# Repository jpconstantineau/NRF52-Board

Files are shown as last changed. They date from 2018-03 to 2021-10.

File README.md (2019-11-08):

# NRF52-Board

This Repository is a collection of NRF5x boards.

TODO: remap folders...

|  Hardware Name | PCB Folder name | Processor | Firmware  | Circuit Diagram | Build Guide |
| --- |:---:|:---:|:-----:|:-----:|:-----:|
|  LiPo Charger 3.3V Regulator | [Batt_Charger_Regulator](/Batt_Charger_Regulator) | n/a | n/a | | [Build Guide](/Batt_Charger_Regulator/BuildGuide.md) |
|  CR2032 Coin Cell Holder | [Battery](/Battery) | n/a | n/a | | [Build Guide](/Battery/BuildGuide.md)|
|  Mini Switch | [MiniSwitch](/MiniSwitch) |n/a |  n/a | | [Build Guide](/MiniSwitch/BuildGuide.md)|
|  BlueMicro V1.x | [EByte_E73](/EByte_E73) |NRF52832 |  [BlueMicro_BLE](https://github.com/jpconstantineau/BlueMicro_BLE) | | [Build Guide](/EByte_E73/BuildGuide.md)|
|  BlueMicro V2.0b | [EByte_E73_Batt](/EByte_E73_Batt) | NRF52832 |  [BlueMicro_BLE](https://github.com/jpconstantineau/BlueMicro_BLE) | | [Build Guide](/EByte_E73_Batt/BuildGuide.md) |
|  BlueMicro V2.0c | [EByte_E73_Batt_ErgoTravel](/EByte_E73_Batt_ErgoTravel) | NRF52832 |  [BlueMicro_BLE](https://github.com/jpconstantineau/BlueMicro_BLE) | | [Build Guide](/EByte_E73_Batt_ErgoTravel/BuildGuide.md) |
| 4X4 backpack | [EByte_E73_Batt_Macro_4x4](/EByte_E73_Batt_Macro_4x4) | NRF52832 |  [BlueMicro_BLE](https://github.com/jpconstantineau/BlueMicro_BLE) | | [Build Guide](/EByte_E73_Batt_Macro_4x4/BuildGuide.md)|
| BlueMicro Tester | [EByte_E73_tester](/EByte_E73_tester) | NRF52832 |  Arduino | | |
| BlueMicro51 | [YJ-14015](/YJ-14015)| NRF51822 |  tbd | | |

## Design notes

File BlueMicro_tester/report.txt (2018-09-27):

Info: Backing up file “C:\GIT\NRF52-Board\EByte_E73_tester\sym-lib-table” to file “C:\GIT\NRF52-Board\EByte_E73_tester\rescue-backup\sym-lib-table-2018-09-22-21-38-46”.
Info: Backing up file “C:\GIT\NRF52-Board\EByte_E73_tester\EByte_E73_tester.sch” to file “C:\GIT\NRF52-Board\EByte_E73_tester\rescue-backup\EByte_E73_tester-2018-09-22-21-38-46.sch”.
Info: Backing up file “C:\GIT\NRF52-Board\EByte_E73_tester\EByte_E73_tester.pro” to file “C:\GIT\NRF52-Board\EByte_E73_tester\rescue-backup\EByte_E73_tester-2018-09-22-21-38-46.pro”.
Info: Backing up file “C:\GIT\NRF52-Board\EByte_E73_tester\EByte_E73_tester-cache.lib” to file “C:\GIT\NRF52-Board\EByte_E73_tester\rescue-backup\EByte_E73_tester-cache-2018-09-22-21-38-46.lib”.
Info: Backing up file “C:\GIT\NRF52-Board\EByte_E73_tester\EByte_E73_tester-rescue.lib” to file “C:\GIT\NRF52-Board\EByte_E73_tester\rescue-backup\EByte_E73_tester-rescue-2018-09-22-21-38-46.lib”.
Info: Backing up file “C:\GIT\NRF52-Board\EByte_E73_tester\EByte_E73_tester-rescue.dcm” to file “C:\GIT\NRF52-Board\EByte_E73_tester\rescue-backup\EByte_E73_tester-rescue-2018-09-22-21-38-46.dcm”.
Warning: No symbol “E73-2G4M04S” found in symbol library table.
Symbol “GND” mapped to symbol library “power”.
Symbol “GND” mapped to symbol library “power”.
Symbol “GND” mapped to symbol library “power”.
Symbol “VCC” mapped to symbol library “power”.
Symbol “L” mapped to symbol library “Device”.
Symbol “C” mapped to symbol library “Device”.
Symbol “C” mapped to symbol library “Device”.
Symbol “GND” mapped to symbol library “power”.
Symbol “C” mapped to symbol library “Device”.
Warning: No symbol “SW_PUSH” found in symbol library table.
Warning: No symbol “SW_PUSH” found in symbol library table.
Symbol “GND” mapped to symbol library “power”.
Symbol “R” mapped to symbol library “Device”.
Symbol “VCC” mapped to symbol library “power”.
Symbol “GND” mapped to symbol library “power”.
Warning: No symbol “Conn_01x06” found in symbol library table.
Symbol “GND” mapped to symbol library “power”.
Symbol “VCC” mapped to symbol library “power”.
Warning: No symbol “JUMPER-SMT_2_NO” found in symbol library table.
Symbol “GND” mapped to symbol library “power”.
Warning: No symbol “ProMicro” found in symbol library table.
Symbol “GND” mapped to symbol library “power”.
Symbol “VCC” mapped to symbol library “power”.
Symbol “GND” mapped to symbol library “power”.
Warning: No symbol “SW_PUSH” found in symbol library table.
Warning: No symbol “SW_PUSH” found in symbol library table.
Symbol “C” mapped to symbol library “Device”.
Symbol “GND” mapped to symbol library “power”.
Info: Symbol library table mapping complete!

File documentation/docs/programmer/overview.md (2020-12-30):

---
id: programmer_overview
title: Need a Programmer?
slug: /programmer/
---

## Why would you need one?

Here are a few reasons why you would need a SWD programmer:

* you have built/assembled a nRF52 board using a bare nRF52 chip or a module containing a nRF52 chip which were not previously programmed.
* you have completed the build of a partially assembled nRF52 board and need to flash the bootloader
* you have somehow bricked your nRF52 board and need to re-flash the bootloader
* you want to experiment with new bootloaders

## Available Options

| Name  | Connector  | Software  | License  | Comments  |
|---|---|---|---|---|
|[Segger J-Link Plus](https://www.digikey.com/en/products/detail/segger-microcontroller-systems/8-08-28-J-LINK-PLUS/4476087)| 2.54mm 2x10 | Segger J-Link | Segger | Expensive |
|[Segger J-Link Edu](https://www.digikey.com/en/products/detail/segger-microcontroller-systems/8-08-90-J-LINK-EDU/2263130)| 2.54mm 2x10 | Segger J-Link | Segger | Educational Use Only |
|[Segger J-Link Edu Mini](https://www.digikey.com/en/products/detail/segger-microcontroller-systems/8-08-91-J-LINK-EDU-MINI/7387472)| 1.27mm 2x5 | Segger J-Link | Segger | Educational Use Only, only supports 3.3V targets.  You will need a cable adapter.|
|Chinese J-Link Clone| Varies depending on version | Segger J-Link | Segger | may generate odd error messages (which can be dismissed), only supports 3.3V targets |
|Chinese ST-Link V2 Clone| non-standard 2.54 2x5 | OpenOCD | Open Source | Complex to setup, only supports 3.3V targets |
|Raspberry Pi| 40 Pin header | OpenOCD | Open Source | Complex to setup, only supports 3.3V targets|
|CMSIS-DAP| Varies but generally 1.27mm 2x5 | OpenOCD | Open Source | Complex to setup, only supports 3.3V targets |
|[Blackmagic Probe](https://1bitsquared.com/collections/frontpage/products/black-magic-probe)| 1.27mm 2x5 | GDB | Open Source | No additional software to setup. You will need a cable adapter. Supports 1.7-5V targets.|
|BluePill| non-standard 2.54 | GDB | Open Source | Cheap but complex to setup, only supports 3.3V targets |
|[nRF52 SWD Programmer and Debugger](/docs/programmer/programmer_nrf52bmp)| 2.54mm 2x5 and 2.54mm 1x4 | GDB | Open Source | No additional software to setup. Supports 1.8-3.3V targets. |

## Notes on Nordic Semiconductor and Segger

[Segger and Nordic have worked together for years and Segger Embedded Studio is used internally by Nordic engineers](https://www.nordicsemi.com/Software-and-tools/Development-Tools/Segger-Embedded-Studio). This is why Nordic usually recommends Segger's J-Link as the tool of choice for programming the nRF52 chips.

## Notes on Adafruit nRF52 Arduino support

The [Adafruit nRF52 Arduino](https://github.com/adafruit/Adafruit_nRF52_Arduino) board support package uses Segger's J-Link to program the bootloader.  If you don't have a j-link, you won't be able to use the integration within the Arduino IDE to flash the bootloader.

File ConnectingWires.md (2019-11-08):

## Preparing Connecting wires to Flash a BlueMicro ##

**Preparing a purple Jlink wire bundle**

You will need to connect power to the BlueMicro since the purple jlink does not provide power; it only detects that the BlueMicro receives power...

Swdck -> SWDck

Swdio -> swdio

Gnd -> gnd

VCC -> VCC

Remove all 1 pin shells from a 4 wire bundle.  For the BlueMicro, this will be a M-F bundle.

* Take a 4 pin shell
* line-up the 4 dupont metal connectors in the shell to line up with the jlink lines (choose colors that make sense for each line)
* Take 2 2 pins shells. 
* Put GND and VCC in one of the 2 pin shell. 
* Put swdio and swdck in the other 2 pin shell. 

We use 2 pin shells because we need to mirror the connections when we flash to left vs right (the BlueMicro is upside down on one side)

**Preparing a Serial Bundle**

For the serial, you need 3 wires

Gnd -> gnd

Rx -> tx

Tx -> Rx.

For serial, 
* Take a 6 pin shell (enough to fit the entire CH340g serial adapter) 
* Take a 3 wire bundle (F-F).  
* On the 6 pin side, line up RX,TX and GNd with colors that make sense...
* For the other end, install the small angled header in the ErgoTravel where it has gnd, Rx and TX. This is the same header as the RGB strips connections for wired builds.  
* Once soldered, you can then fill-in a 4 pin shell with the Rx,tx and GNdD (Reset will be somewhere in there but not used) VCC isnt connected too.

Do not connect VCC of the serial adapter. I have seen such adapters burn out because the internal power regulator was competing with a more powerful power regulator... Just connect the battery and the 3 serial wires and you should be good.  You will need to press the reset switch at the right time to get the BlueMicro in dfu serial. (If a firmware is loaded, it remains in dfu serial for a couple of seconds)

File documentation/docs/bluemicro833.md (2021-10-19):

---
id: bluemicro833
title: BlueMicro833 V1.x
---
## Description

## Processor and Module

The BlueMicro833 uses the nRF52833 from Nordic Semiconductors. For an overview of the features of this SoC, refer to Nordic's [Product Page](https://www.nordicsemi.com/Products/Low-power-short-range-wireless/nRF52840).  The most important features are as follows:

* 64 MHz Cortex-M4 with FPU
* 512 KB Flash, 128 KB RAM
* 2.4 GHz Transceiver
* -20 to +8 dbm programmable TX Power
* 42 configurable GPIOs
* USB 2.0

For a detailed description of the nRF52833, you can download the [Specification](https://infocenter.nordicsemi.com/pdf/nRF52833_OPS_v0.7.pdf) (582 pages).

The BlueMicro833 uses the [Ebyte E73-2G4M08S1E module](https://s.click.aliexpress.com/e/_AkrGeT).   
The module uses a ceramic antenna and makes 31 GPIOs available externally, 2 of which are reserved for the low frequency crystal oscilator and 1 is reserved for the reset button.
For a detailed description of the module, refer to the [manual](https://www.ebyte.com/en/pdf-down.aspx?id=2004).

## Bootloader

Although the BlueMicro833 can be programmed using the Nordic Software Development Kit and other commercial tools, we recommend using the open source [Adafruit nRF52 Bootloader](https://github.com/adafruit/Adafruit_nRF52_Bootloader) as the bootloader for the BlueMicro833. 

You can obtain the bootloader from the following locations:

* release artifacts of the [Adafruit Repo](https://github.com/adafruit/Adafruit_nRF52_Bootloader/releases)

## Firmware

CircuitPython is supported by the BlueMicro833.  You can get the UF2 Build at the following location:

* CircuitPython Download for the [BlueMicro833](https://circuitpython.org/board/bluemicro833/)

## Pinout

You can find the pinout in the schematic [here](https://github.com/jpconstantineau/BlueMicro833_hardware/blob/main/Schematic.pdf) at the top right.

## PCB

[hardware design repo](https://github.com/jpconstantineau/BlueMicro833_hardware)

## Schematic

You can find the schematic [here](https://github.com/jpconstantineau/BlueMicro833_hardware/blob/main/Schematic.pdf)

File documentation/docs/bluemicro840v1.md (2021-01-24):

---
id: bluemicro840_v1
title: BlueMicro840 V1.x
---
## Description

## Processor and Module

The BlueMicro840 uses the nRF52840 from Nordic Semiconductors. For an overview of the features of this SoC, refer to Nordic's [Product Page](https://www.nordicsemi.com/Products/Low-power-short-range-wireless/nRF52840).  The most important features are as follows:

* 64 MHz Cortex-M4 with FPU
* 1 MB Flash, 256 KB RAM
* 2.4 GHz Transceiver
* -20 to +8 dbm programmable TX Power
* 48 configurable GPIOs
* USB 2.0

For a detailed description of the nRF52840, you can download the [datasheet](https://infocenter.nordicsemi.com/pdf/nRF52840_PS_v1.1.pdf) (619 pages).

The BlueMicro840 uses the [Ebyte E73-2G4M08S1C module](https://s.click.aliexpress.com/e/_dWxR3nN). This module is FCC and CE certified.  
The module uses a ceramic antenna and makes 32 GPIOs available externally, 2 of which are reserved for the low frequency crystal oscilator and 1 is reserved for the reset button.
For a detailed description of the module, refer to the [manual](http://www.ebyte.com/en/downpdf.aspx?id=445).

## Bootloader

Although the BlueMicro840 can be programmed using the Nordic Software Development Kit and other commercial tools, we recommend using the open source [Adafruit nRF52 Bootloader](https://github.com/adafruit/Adafruit_nRF52_Bootloader) as the bootloader for the BlueMicro840.  Two versions of the bootloader are compatible with the BlueMicro840:

* [Nordic nRF52840-DK](https://www.nordicsemi.com/Software-and-Tools/Development-Kits/nRF52840-DK) - also named PCA10056
* [BlueMicro840](http://nrf52.jpconstantineau.com/docs/bluemicro840_v1).

You can obtain the above bootloaders from the following locations:

* release artifacts of the [Adafruit Repo](https://github.com/adafruit/Adafruit_nRF52_Bootloader/releases)
* release artifacts of the [Forked Repo](https://github.com/jpconstantineau/Adafruit_nRF52_Bootloader/releases)
* Adafruit nRF52 Arduino Board Support Package
* Community Add-on to Adafruit nRF52 Arduino Board Support Package

## Firmware

## Pinout


NOTE: The Silkscreen on pin 6 (labelled 0.31) is incorrectly printed as 0.31. It should read 0.26. The schematic below is correct.

## PCB
| Top  | Bottom  |
|---|---|
|  |   |

NOTE: The Silkscreen on pin 6 (labelled 0.31) is incorrectly printed as 0.31. It should read 0.26. The schematic below is correct.

## Schematic

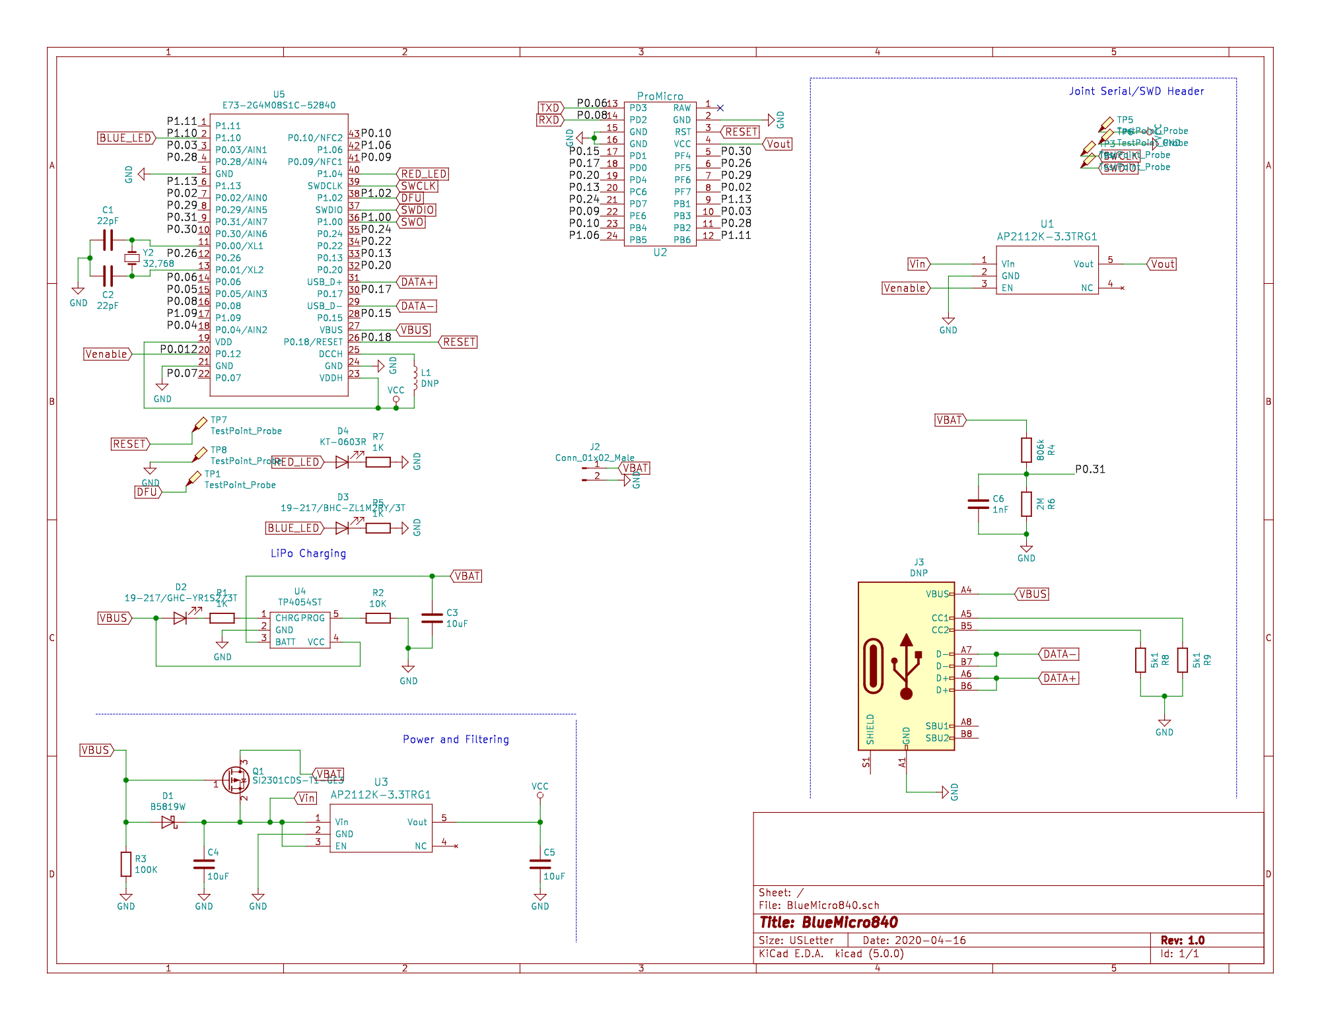
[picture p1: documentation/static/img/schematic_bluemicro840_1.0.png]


## Building it yourself?

You need to order the parts included in this [csv BOM](https://raw.githubusercontent.com/jpconstantineau/NRF52-Board/master/BlueMicro840/BlueMicro840.csv).  You can it load in Excel.  The LCSC column refers to the part number at [LCSC.com](https://lcsc.com/).

### Small Components

If you are assembling the BlueMicro840 yourself, refer to the [HTML Bom](http://nrf52.jpconstantineau.com/bom/BlueMicro840/ibom.html) to help you as you assemble it. If you have received the partially assembled boards, you will have all these components already installed and you can move on to the next section.

### USB-C Connector

Steps to solder the TYPE-C-31-M-12 from Korean Hroparts Elec onto a PCB using only a Soldering Iron:
1 - using a no-clean rosin fluxed Solder, pre-apply some solder to the pads, making sure you don't have large "blobs" or joints between pads.
2 - place the connector on top, making sure to align it properly.
3 - apply heat to the connector pins.  This will solder the pins in place.
4 - once soldered, move on to the body of the connector, starting with one of the larger pegs.
5 - Once the 4 metal body pegs are soldered, pass again over the connector pins; making sure that no solder bridges two pins.

<figure class="video-container">
 <iframe src="http://www.youtube.com/embed/PbO9HdlcIPY" frameborder="0" allowfullscreen width="100%"></iframe>
 </figure>

Tools I use for soldering the connector:

* TS 100 Soldering Iron with 19V power supply (300C setting)
* TS-D24 Soldering Tip. This is the Chisel Tip one.
* Copper Cleaning Ball for Soldering Iron (ball of copper wool in a metal container)
* MG Chemicals 63/37 No Clean Leaded Solder, 0.032" Diameter

Once you have soldered the connectors on, you will need to test if there are any shorts between VUsb and GND. These are the outermost pins on each side of the connector.  Because VUsb is not available on the pins, I use a USB tester.  You can test it using a multimeter on the continuity testing function.

<figure class="video-container">
 <iframe src="http://www.youtube.com/embed/2jEpu-We5eI" frameborder="0" allowfullscreen width="100%"></iframe>
 </figure>

Tools I use for testing  the connector:
* [USB Tester](https://s.click.aliexpress.com/e/_AaXAiW)
* [25cm USB-C Cable](https://s.click.aliexpress.com/e/_Aot7Zo)
* Old phone charger

### E73 Module

With the hidden pads underneath the module, soldering it to a PCB using just a soldering iron isn't a trivial task.

Steps:

1. Add a bead of solder to the inner pads of the E73 module.  Make sure that they are not too large and are all the same size
2. Line-up the beads with the holes matching these pads in the PCB.  Since the beads will "fall into" the holes they will "fall in place" somewhat.  A binder clip will help hold everything together
3. Heat-up the inner pads on the opposite side of the PCB, distributing the heat to all pads so that the solder melt and until there is no gap left between the module and PCB.  This will require multiple passes with a larger soldering iron tip to heat more than 1 pad at a time.
4. Once the inner pads are soldered, change your tip to a conical one with w relatively fine tip (not super fine).  You can then start soldering the outer pads.  Make sure to keep the head and iron away from the holes of the PCB.  Only heat the castellations of the module, apply a little bit of solder and let it flow towards the PCB pad.
5. Go and solder the 3 sides of the module, one joint at a time.
6. Once you have all joints done, visually inspect all connections to make sure there are no shorts between pins.
7. Go ahead and test with a USB tester.  This will make sure there are no shorts in the power circuitry.
8. To test the rest, we need to flash a bootloader and some testing firmware on it.

<figure class="video-container">
 <iframe src="http://www.youtube.com/embed/k_32XvBC0sA" frameborder="0" allowfullscreen width="100%"></iframe>
 </figure>

Tools Used:

* TS 100 Soldering Iron with 19V power supply (300C setting)
* TS-D24 Soldering Tip. This is the Chisel Tip one.
* TS-B2 Conical Soldering Tip (not very fine like the TS-I)
* Copper Cleaning Ball for Soldering Iron (ball of copper wool in a metal container)
* MG Chemicals 63/37 No Clean Leaded Solder, 0.032" Diameter
* Small Binder Clip
* Solder Wick

### Flash Bootloader

Using the Community nRF52 Add-on Boards in the Arduino IDE and a Black Magic Probe (nRF52 GDB Debugger), it's possible to unlock and flash the bootloader very easily without the need to configure any special software.

<figure class="video-container">
 <iframe src="http://www.youtube.com/embed/-Na2m6-LVGI" frameborder="0" allowfullscreen width="100%"></iframe>
 </figure>

1. Select Board type.  In this case, it's a BlueMacro840
2. Select Programmer (use Black Magic Probe - Unlock and Erase)
3. Select Serial port from Programmer (there are 2, you may have to try each one)
4. Select "Burn Bootloader" while making sure there is good contact with the board. This will unlock the nrf52840 (or nrf52832)
5. Select Programmer (use Black Magic Probe)
6. Select "Burn Bootloader" while making sure there is good contact with the board. This will flash the bootloader

There are 2 common errors:
* SWD Scan failed: this is generally due to a poor connection with the chip. Note that in the video, I give the BlueMacro840 and programmer a gentle twist to make sure I have a good contact.
* Cannot flash because the chip is protected.  You need to "unlock and erase" before flashing the bootloader. 

### Test USB-C Connector

This step is done after the bootloader is flashed to the chip.  With the bootloader enabled, we will see if the computer detects the nRF52840 chip.  If the device doesn't connect or if the device is not recognized, it's likely that the data lines on the USB-C connector are not soldered properly.

<figure class="video-container">
 <iframe src="http://www.youtube.com/embed/brCGFSwaw_k" frameborder="0" allowfullscreen width="100%"></iframe>
 </figure>

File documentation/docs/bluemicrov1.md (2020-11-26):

---
id: bluemicro_v1
title: BlueMicro V1.x
---

## Description

The BlueMicro V1.x is a simple breakout board for the Ebyte E73-2G4M04S1B module (nRF52832) so that the pinout matches that of the Arduino Pro Micro.

## Processor and Module

The BlueMicro uses the nRF52832 from Nordic Semiconductors. For an overview of the features of this SoC, refer to Nordic's [Product Page](https://www.nordicsemi.com/Products/Low-power-short-range-wireless/nRF52832).  The most important features are as follows:

* 64 MHz Cortex-M4 with FPU
* 512 KB Flash, 64 KB RAM
* 2.4 GHz Transceiver
* -20 to +4 dbm programmable TX Power
* 32 configurable GPIOs

For a detailed description of the nRF52832, you can download the [datasheet](http://infocenter.nordicsemi.com/pdf/nRF52832_PS_v1.4.pdf) (533 pages).

The BlueMicro uses the [Ebyte E73-2G4M04S1B module](https://s.click.aliexpress.com/e/_ACxA0g). This module is FCC and CE certified.  
The module uses a PCB antenna, has an external antenna connector and makes 30 GPIOs available externally, 1 of which is reserved for the reset button.  The bootloader and firmware may reserve additional GPIOs for specific functions (2 pins for serial, 1 pin for factory reset, 1 pin to put in DFU)
For a detailed description of the module, refer to the [manual](http://www.ebyte.com/en/downpdf.aspx?id=243).

If you want to replace the PCB antenna with an external antenna, the following [antenna](https://s.click.aliexpress.com/e/_A1WdTb) is the one that's designed by the module manufacturer.  The manual indicate the small surface mount resistor that needs moving to disconnect the PCB antenna and connect the external antenna.

## Bootloader

Although the BlueMicro can be programmed using the Nordic Software Development Kit and other commercial tools, we recommend using the open source [Adafruit nRF52 Bootloader](https://github.com/adafruit/Adafruit_nRF52_Bootloader) as the bootloader for the BlueMicro.  The Adafruit nRF52832 Feather bootloader is fully compatible with the BlueMicro.

You can obtain the bootloader from the following locations:

* release artifacts of the [Adafruit Repo](https://github.com/adafruit/Adafruit_nRF52_Bootloader/releases)
* release artifacts of the [Forked Repo](https://github.com/jpconstantineau/Adafruit_nRF52_Bootloader/releases)
* Adafruit nRF52 Arduino Board Support Package
* Community Add-on to Adafruit nRF52 Arduino Board Support Package

## Pinout

## PCB
| Top  | Bottom  |
|---|---|
|  |   |

## Schematic

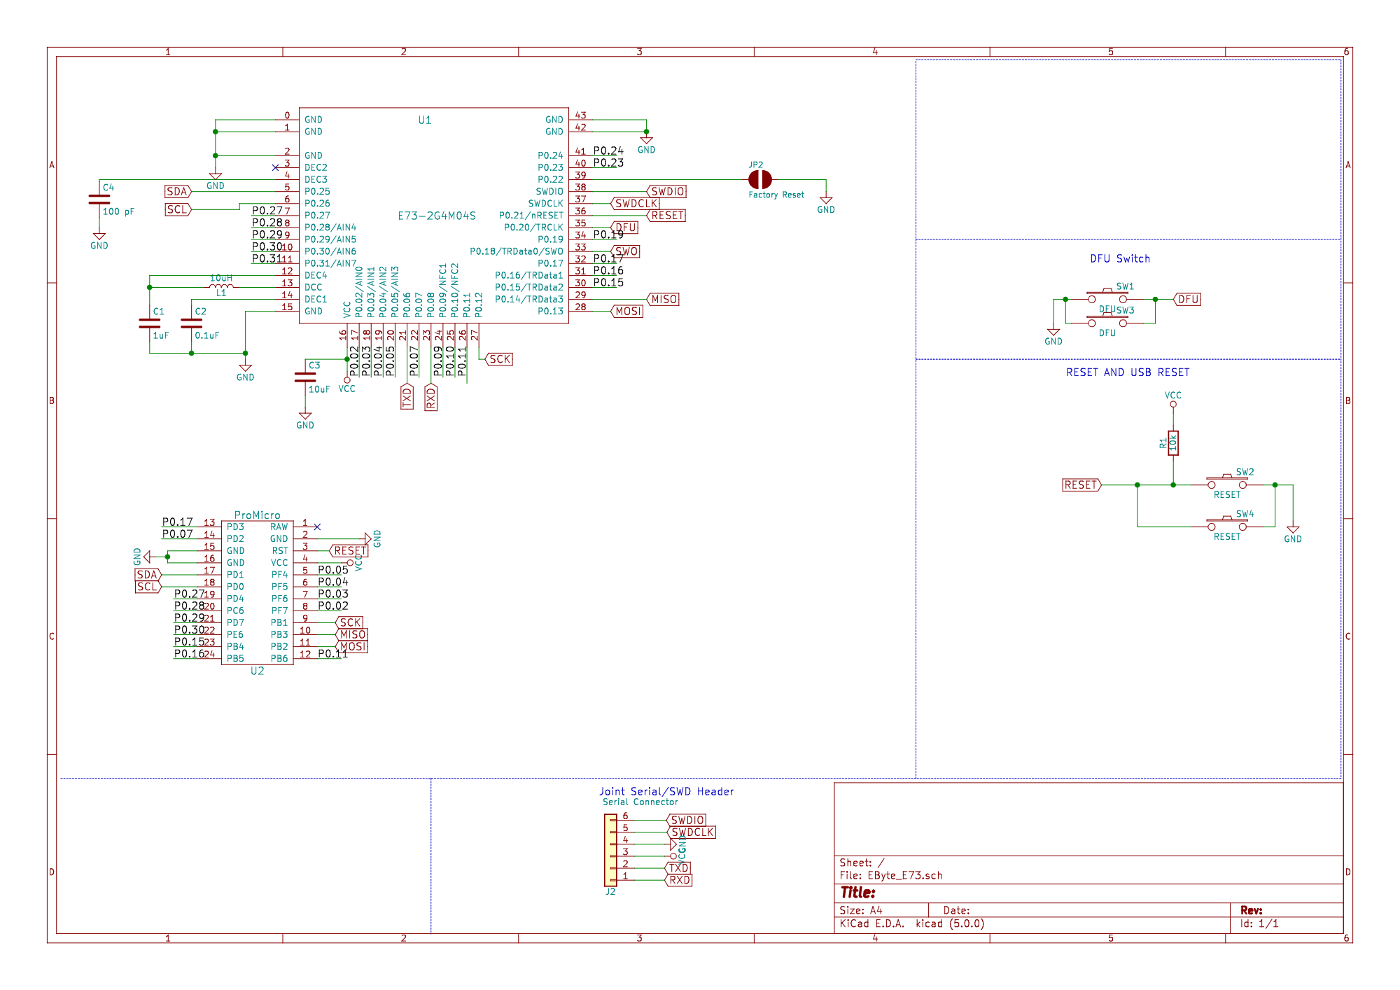
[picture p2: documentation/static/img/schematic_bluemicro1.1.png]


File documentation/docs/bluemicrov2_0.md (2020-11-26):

---
id: bluemicro_v2_0
title: BlueMicro V2.0
---

## Description

The BlueMicro V2.0 expands on the BlueMicro V1.x by adding a LiPo charger on board as well as battery monitoring circuitry to the breakout board for the Ebyte E73-2G4M04S1B module (nRF52832). The charger is powered by connecting a standard micro-usb cable to a computer or regular 5V charger.  The pinout still matches that of the Arduino Pro Micro.  The Raw pin is meant to be connected to the LiPo battery for powering on the BlueMicro.

## Processor and Module

The BlueMicro uses the nRF52832 from Nordic Semiconductors. For an overview of the features of this SoC, refer to Nordic's [Product Page](https://www.nordicsemi.com/Products/Low-power-short-range-wireless/nRF52832).  The most important features are as follows:

* 64 MHz Cortex-M4 with FPU
* 512 KB Flash, 64 KB RAM
* 2.4 GHz Transceiver
* -20 to +4 dbm programmable TX Power
* 32 configurable GPIOs

For a detailed description of the nRF52832, you can download the [datasheet](http://infocenter.nordicsemi.com/pdf/nRF52832_PS_v1.4.pdf) (533 pages).

The BlueMicro uses the [Ebyte E73-2G4M04S1B module](https://s.click.aliexpress.com/e/_ACxA0g). This module is FCC and CE certified.  
The module uses a PCB antenna, has an external antenna connector and makes 30 GPIOs available externally, 1 of which is reserved for the reset button.  The bootloader and firmware may reserve additional GPIOs for specific functions (2 pins for serial, 1 pin for factory reset, 1 pin to put in DFU)
For a detailed description of the module, refer to the [manual](http://www.ebyte.com/en/downpdf.aspx?id=243).

If you want to replace the PCB antenna with an external antenna, the following [antenna](https://s.click.aliexpress.com/e/_A1WdTb) is the one that's designed by the module manufacturer.  The manual indicate the small surface mount resistor that needs moving to disconnect the PCB antenna and connect the external antenna.

## Bootloader

Although the BlueMicro can be programmed using the Nordic Software Development Kit and other commercial tools, we recommend using the open source [Adafruit nRF52 Bootloader](https://github.com/adafruit/Adafruit_nRF52_Bootloader) as the bootloader for the BlueMicro.  The Adafruit nRF52832 Feather bootloader is fully compatible with the BlueMicro.

You can obtain the bootloader from the following locations:

* release artifacts of the [Adafruit Repo](https://github.com/adafruit/Adafruit_nRF52_Bootloader/releases)
* release artifacts of the [Forked Repo](https://github.com/jpconstantineau/Adafruit_nRF52_Bootloader/releases)
* Adafruit nRF52 Arduino Board Support Package
* Community Add-on to Adafruit nRF52 Arduino Board Support Package

## Pinout

## PCB
| Top  | Bottom  |
|---|---|
|  |   |

## Schematic

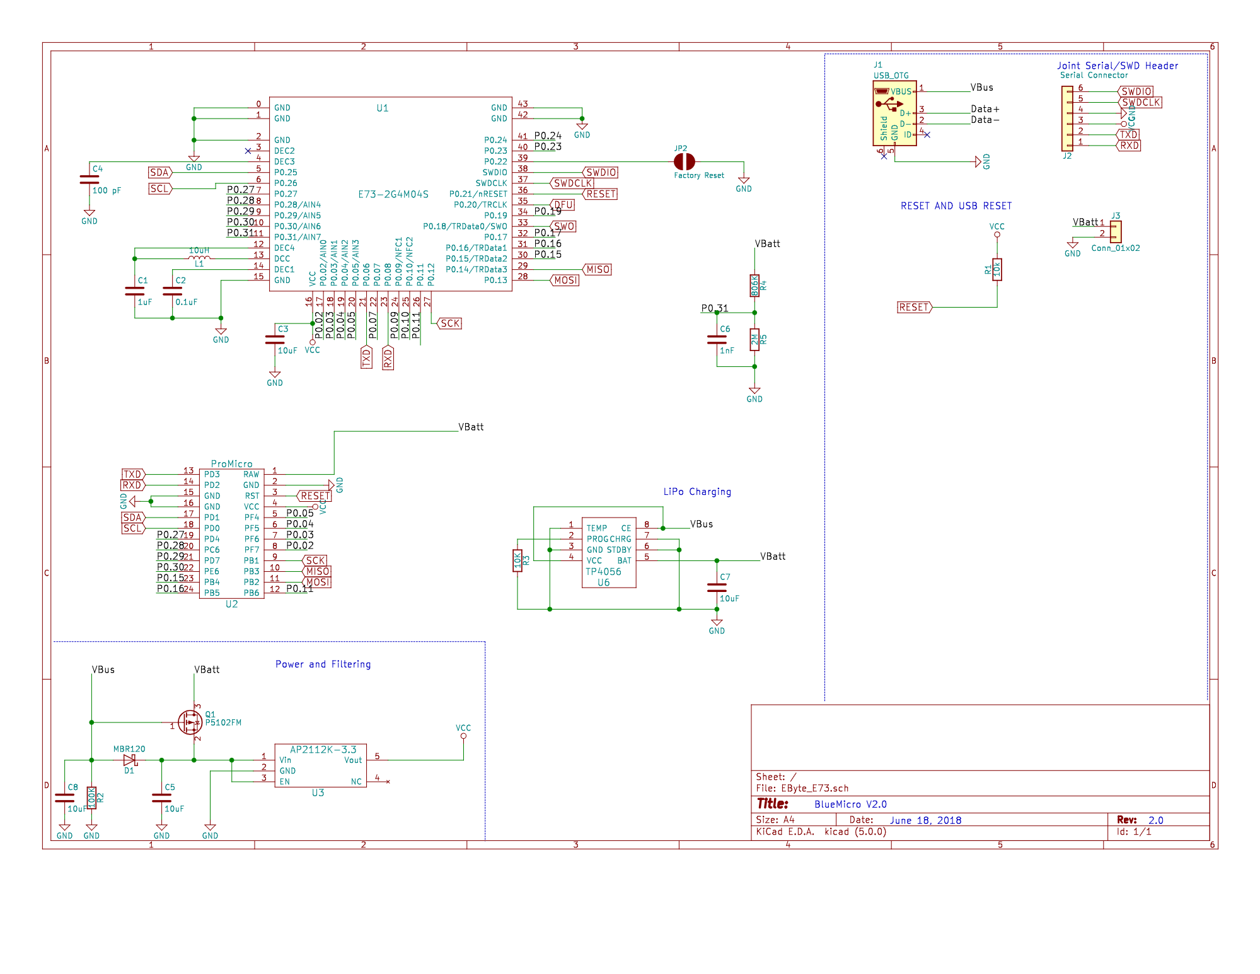
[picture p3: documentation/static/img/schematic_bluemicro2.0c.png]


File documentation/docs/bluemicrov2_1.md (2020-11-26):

---
id: bluemicro_v2_1
title: BlueMicro V2.1
---
## Description

The BlueMicro V2.1 expands on the BlueMicro V1.x and V2.0 by adding a serial chip to the breakout board for the Ebyte E73-2G4M04S1B module (nRF52832).  This serial chip allows for programming the BlueMicro without the need for any additionnal hardware and simplifies the process since the serial chip is also connected to the reset circuitry.  The charger is still powered by connecting a standard micro-usb cable to a computer or regular 5V charger.  The pinout still matches that of the Arduino Pro Micro.  The Raw pin is meant to be connected to the LiPo battery for powering on the BlueMicro.

Since the serial GPIOs are directly connected to the serial chip, the pinout differs slightly from the BlueMicro v2.0.

## Processor and Module

The BlueMicro uses the nRF52832 from Nordic Semiconductors. For an overview of the features of this SoC, refer to Nordic's [Product Page](https://www.nordicsemi.com/Products/Low-power-short-range-wireless/nRF52832).  The most important features are as follows:

* 64 MHz Cortex-M4 with FPU
* 512 KB Flash, 64 KB RAM
* 2.4 GHz Transceiver
* -20 to +4 dbm programmable TX Power
* 32 configurable GPIOs

For a detailed description of the nRF52832, you can download the [datasheet](http://infocenter.nordicsemi.com/pdf/nRF52832_PS_v1.4.pdf) (533 pages).

The BlueMicro uses the [Ebyte E73-2G4M04S1B module](https://s.click.aliexpress.com/e/_ACxA0g). This module is FCC and CE certified.  
The module uses a PCB antenna, has an external antenna connector and makes 30 GPIOs available externally, 1 of which is reserved for the reset button.  The bootloader and firmware may reserve additional GPIOs for specific functions (2 pins for serial, 1 pin for factory reset, 1 pin to put in DFU)
For a detailed description of the module, refer to the [manual](http://www.ebyte.com/en/downpdf.aspx?id=243).

If you want to replace the PCB antenna with an external antenna, the following [antenna](https://s.click.aliexpress.com/e/_A1WdTb) is the one that's designed by the module manufacturer.  The manual indicate the small surface mount resistor that needs moving to disconnect the PCB antenna and connect the external antenna.

## Bootloader

Although the BlueMicro can be programmed using the Nordic Software Development Kit and other commercial tools, we recommend using the open source [Adafruit nRF52 Bootloader](https://github.com/adafruit/Adafruit_nRF52_Bootloader) as the bootloader for the BlueMicro.  The Adafruit nRF52832 Feather bootloader is fully compatible with the BlueMicro.

You can obtain the bootloader from the following locations:

* release artifacts of the [Adafruit Repo](https://github.com/adafruit/Adafruit_nRF52_Bootloader/releases)
* release artifacts of the [Forked Repo](https://github.com/jpconstantineau/Adafruit_nRF52_Bootloader/releases)
* Adafruit nRF52 Arduino Board Support Package
* Community Add-on to Adafruit nRF52 Arduino Board Support Package

## Pinout

## PCB
| Top  | Bottom  |
|---|---|
|  |   |

## Schematic

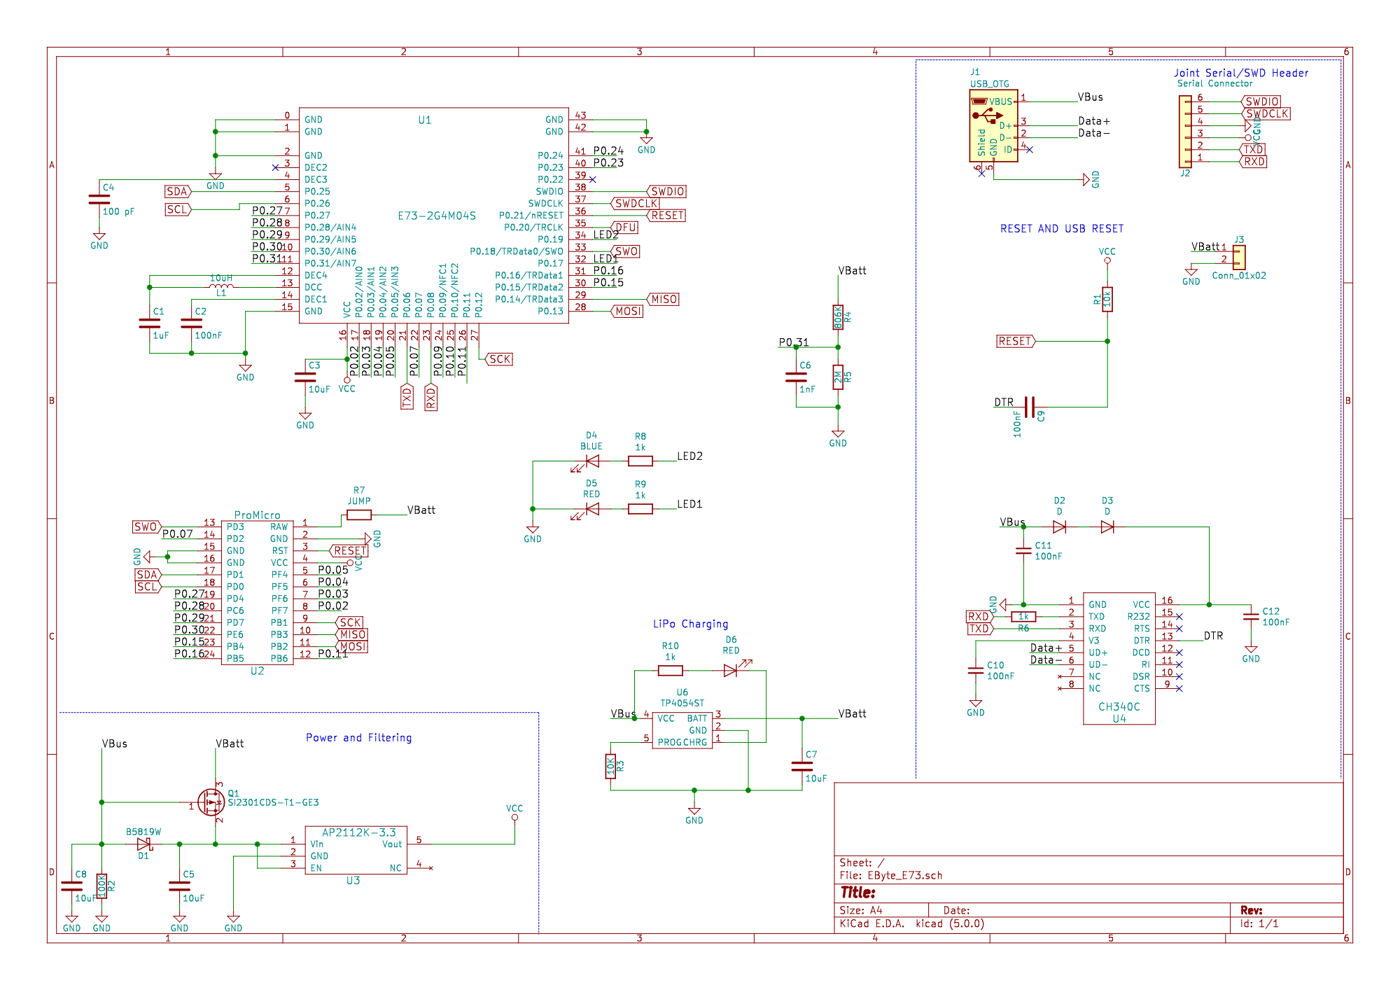
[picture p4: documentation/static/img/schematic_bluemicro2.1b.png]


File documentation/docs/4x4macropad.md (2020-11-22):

---
id: 4x4macropad
title: 4x4 Macropad
---

## Pinout

## Schematic

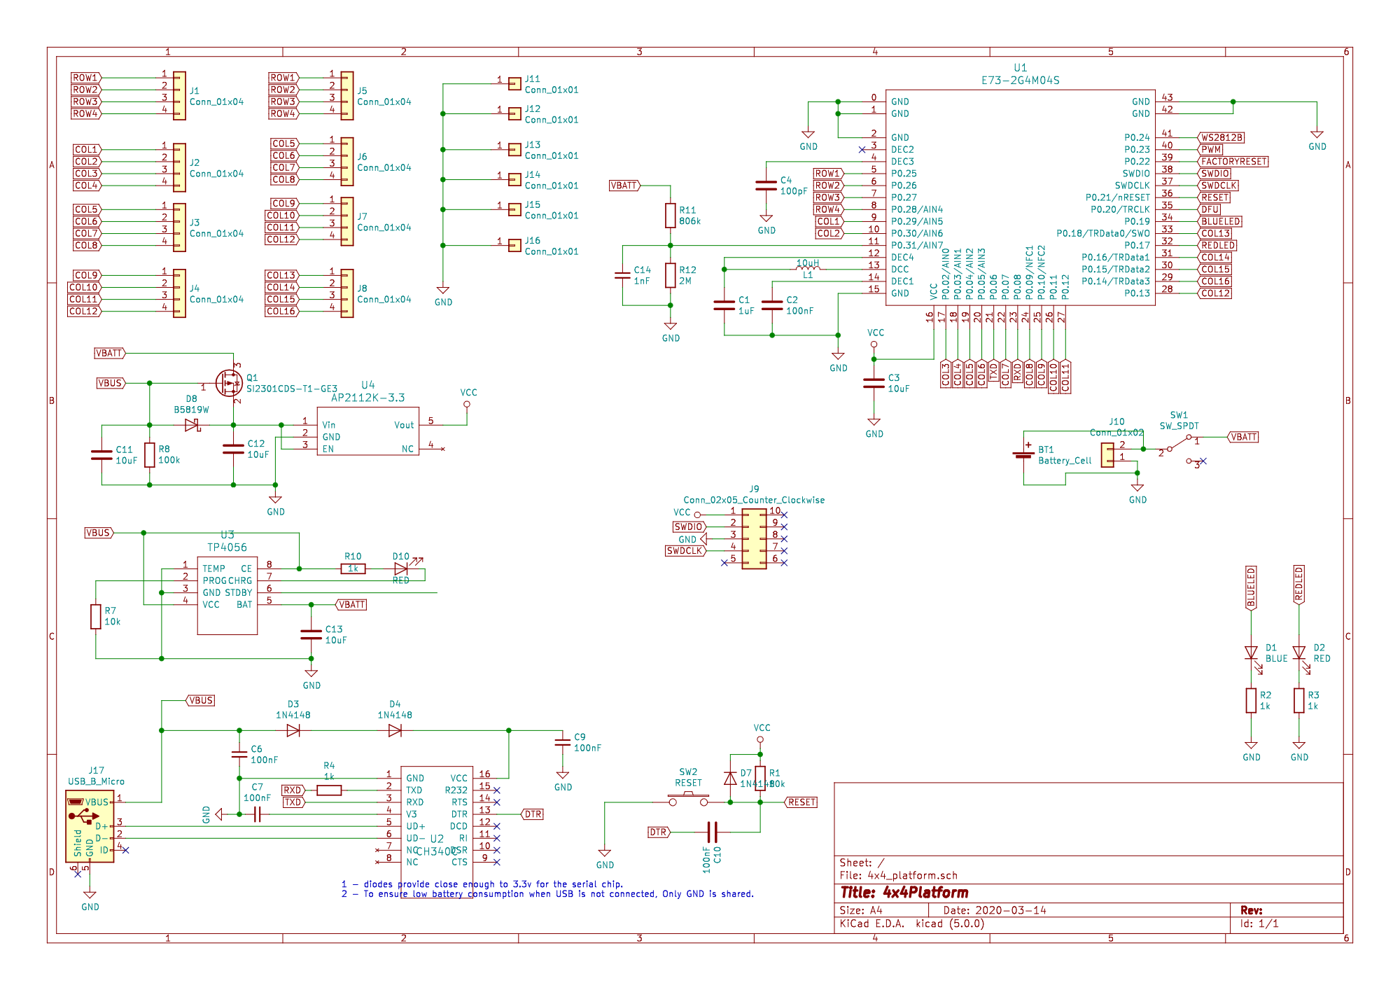
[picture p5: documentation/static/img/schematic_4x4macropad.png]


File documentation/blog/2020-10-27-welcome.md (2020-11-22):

---
slug: welcome
title: Welcome
author: Pierre Constantineau
author_title: Wireless electronics enthousiast in Canada
author_url: https://github.com/jpconstantineau
author_image_url: https://avatars3.githubusercontent.com/u/1149816?s=460&u=521fbf5035ea442b1d07281c0c7573ca3596cf3f&v=4
tags: [BlueMicro]
---

Currently working on:
- Documentation
- More Documentation
- Helping people out on Discord.

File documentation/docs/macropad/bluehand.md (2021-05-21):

---
id: bluehand
title: 2x4 BlueHand
---

## Description

The BlueHand was custom designed for the layout of [artsey.io](https://www.artsey.io/).  This layout uses 8 keys as a chorded layout that allows for typing pretty much everything by pressing chords instead of single keys (a bit like steno keyboards).
It's easy to pick up in your own hands and even type from inside your pockets!

## Processor and Module

The BlueHand uses the nRF52840 from Nordic Semiconductors. For an overview of the features of this SoC, refer to Nordic's [Product Page](https://www.nordicsemi.com/Products/Low-power-short-range-wireless/nRF52840).  The most important features are as follows:

* 64 MHz Cortex-M4 with FPU
* 1 MB Flash, 256 KB RAM
* 2.4 GHz Transceiver
* -20 to +8 dbm programmable TX Power
* 48 configurable GPIOs
* USB 2.0

For a detailed description of the nRF52840, you can download the [datasheet](https://infocenter.nordicsemi.com/pdf/nRF52840_PS_v1.1.pdf) (619 pages).

The BlueHand uses the [Ebyte E73-2G4M08S1C module](https://s.click.aliexpress.com/e/_dWxR3nN). This module is FCC and CE certified.  
The module uses a ceramic antenna and makes 32 GPIOs available externally, 2 of which are reserved for the low frequency crystal oscilator and 1 is reserved for the reset button.
For a detailed description of the module, refer to the [manual](http://www.ebyte.com/en/downpdf.aspx?id=445).

## Bootloader

Although the BlueHand can be programmed using the Nordic Software Development Kit and other commercial tools, we recommend using the open source [Adafruit nRF52 Bootloader](https://github.com/adafruit/Adafruit_nRF52_Bootloader) as the bootloader for the BlueHand.  Two versions of the bootloader are compatible with the BlueHand:

* [Nordic nRF52840-DK](https://www.nordicsemi.com/Software-and-Tools/Development-Kits/nRF52840-DK) - also named PCA10056
* [BlueMicro840](http://nrf52.jpconstantineau.com/docs/bluemicro840_v1).

You can obtain the above bootloaders from the following locations:

* release artifacts of the [Adafruit Repo](https://github.com/adafruit/Adafruit_nRF52_Bootloader/releases)
* release artifacts of the [Forked Repo](https://github.com/jpconstantineau/Adafruit_nRF52_Bootloader/releases)
* Adafruit nRF52 Arduino Board Support Package
* Community Add-on to Adafruit nRF52 Arduino Board Support Package

## Firmware

### Artsey & ZMK

Once you have your BlueHand, you can head over to the builds of [zmk-artsey](https://github.com/artseyio/zmk-artsey).  Look into the artifacts in the most recent [actions](https://github.com/artseyio/zmk-artsey/actions) and download the bluehand_right-bluemicro840_v1-zmk-artsey or bluehand_left-bluemicro840_v1-zmk-artsey firmare. Unzip the file, double-press reset and copy the uf2 file to the mass storage device that appeared as you double-reset the BlueHand.  Since it's compatible with the BlueMicro840, you should see BlueMicro840 as the device that just showed up for the firmware update.  

### BlueMicro_BLE

## PCB

 

## Schematic



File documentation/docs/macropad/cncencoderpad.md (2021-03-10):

---
id: cncencoderpad
title: Encoder Pad
---

## Description

## PCB

## Schematic

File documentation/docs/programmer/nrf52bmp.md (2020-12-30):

---
id: programmer_nrf52bmp
title: nRF52 GDB Debugger
---

## Description

The nRF52 GDB Debugger is an inexpensive Open Source blackmagic probe compatible SWD debugger designed to be used with ARM GDB. It supports [many platforms](https://github.com/blacksphere/blackmagic/wiki), but was primarily designed for use with our Nordic Semiconductor nRF52 BLE boards.

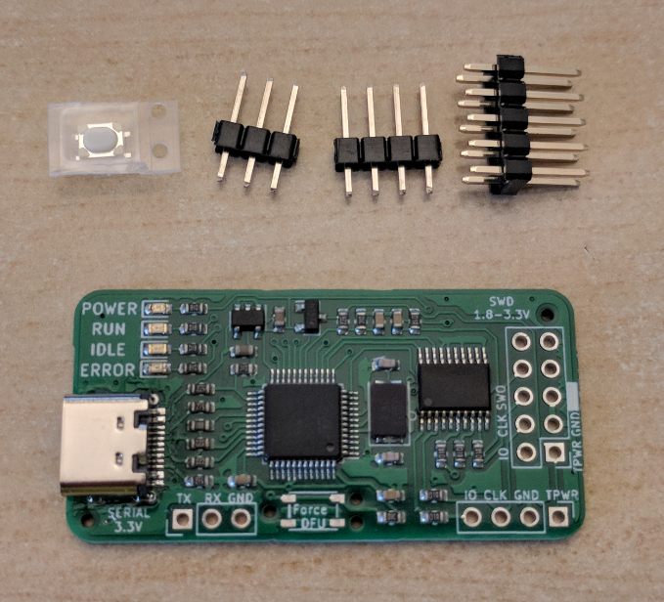
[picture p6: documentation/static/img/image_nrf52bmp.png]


When we built our BlueMicro840 and BlueMacro840 boards, we were looking for an simple option to upload the bootloader without the need to worry about additionnal cables or adapters between the programmer and the board.  Then we came across the blackmagic probe (BMP) project - an Open Source debugging tool for embedded microprocessors. 

Although the BMP hardware is excellent, it requires the use of adapters to convert the standard 1.27mm 2x5 pins programming header to the larger 2.54mm pin header.
So we decided to make use of their liberal open source license and build something that fits our requirements, albeit with less capabilities.  To maintain firmware compatibility with the original BMP, we designed it to be compatible with the first version of the BlackMagic probe.  As such, the same firmware as the Blackmagic Probe can be uploaded to the nRF52 GDB Debugger.

From a software point of view, using the Blackmagic probe greatly simplifies the debugging and code uploading process by just using ARM GDB - no need to run a GDB server or use an additional complex tool like openocd.  Arduino Support for the nRF52 GDB Debugger has been added to the Community nRF52 Board Support Package.  This further simplifies the process of uploading the bootloader to the boards. 

## Final Assembly

If you purchased an assembled and tested nRF52 GDB Debugger, the USB-C connector will be soldered on.  The bootloader and the Black Magic Probe firmware will have been flashed on.  To save on potential damage to the headers while shipping, they are not installed on the nRF52 GDB Debugger.  You will need to solder these yourself.  

* 2x5 Pin header: this is a standard ARM programmer pinout which is designed to be used with the Tag Connect TC2050-IDC-NL programming cable.  These are only needed if you plan to use a standard ARM programming cable.
* 1x4 Pin header: this header matches the SWD pins on the edge of the BlueMicro840 and BlueMacro840 controllers. If you only need to flash a BlueMicro840 or BlueMacro840, you only need to install these pins.
* 1x3 Pin header: this header exposes the serial pins of the programmer.  These are not generally needed.
* DFU update button: this button is only needed if you need to upload a new version of the firmware to the nRF52 GDB Debugger.

## Received a pertially assembled one?

If you purchased a partially assembled nRF52 GDB Debugger, the USB-C connector won't be soldered on.  The bootloader will have been flashed but the firmware will not have been flashed.

### USB-C Connector

Steps to solder the TYPE-C-31-M-12 from Korean Hroparts Elec onto a PCB using only a Soldering Iron:

1.  using a no-clean rosin fluxed Solder, pre-apply some solder to the pads, making sure you don't have large "blobs" or joints between pads.
2.  place the connector on top, making sure to align it properly.
3. apply heat to the connector pins.  This will solder the pins in place.
4. once soldered, move on to the body of the connector, starting with one of the larger pegs.
5. Once the 4 metal body pegs are soldered, pass again over the connector pins; making sure that no solder bridges two pins.

<figure class="video-container">
 <iframe src="http://www.youtube.com/embed/PbO9HdlcIPY" frameborder="0" allowfullscreen width="100%"></iframe>
 </figure>

Tools I use for soldering the connector:

* TS 100 Soldering Iron with 19V power supply (300C setting)
* TS-D24 Soldering Tip. This is the Chisel Tip one.
* Copper Cleaning Ball for Soldering Iron (ball of copper wool in a metal container)
* MG Chemicals 63/37 No Clean Leaded Solder, 0.032" Diameter

Once you have soldered the connectors on, you will need to test if there are any shorts between VUsb and GND. These are the outermost pins on each side of the connector.  Because VUsb is not available on the pins, I use a USB tester.  You can test it using a multimeter on the continuity testing function.

<figure class="video-container">
 <iframe src="//www.youtube.com/embed/2jEpu-We5eI" frameborder="0" allowfullscreen width="100%"></iframe>
 </figure>

Tools I use for testing  the connector:
* [USB Tester](https://s.click.aliexpress.com/e/_AaXAiW)
* [25cm USB-C Cable](https://s.click.aliexpress.com/e/_Aot7Zo)
* Old phone charger

### Flashing the firmware

With the bootloader flashed to the nRF52 GDB Debugger, the LEDs will be cycling/blinking.  This indicates that the bootloader is ready to listen to the DFU-Util for flashing a firmware.

You will need to download the [latest firmware](https://github.com/blacksphere/blackmagic/releases) from the blackmagic github reporitory. Just download the latest .tar.gz file and uncompress it (I use 7-zip). You will need the "blackmagic-native.bin" file from it.

To flash the firmware, you will need the "dfu-util" package. Follow the instructions on Blackmagic's [Upgrading Fiwmware](https://github.com/blacksphere/blackmagic/wiki/Upgrading-Firmware) wiki page for detailed steps on how to proceed.

## Using the nRF52 GDB Debugger to Flash the bootloader to a nRF52

Using the [Community nRF52 Add-on Boards](https://github.com/jpconstantineau/Community_nRF52_Arduino/wiki/Installation-Instructions) in the Arduino IDE, it's possible to unlock and flash the bootloader very easily without the need to configure any special software.

<figure class="video-container">
 <iframe src="http://www.youtube.com/embed/-Na2m6-LVGI" frameborder="0" allowfullscreen width="100%"></iframe>
 </figure>

1. Select Board type.  In this video, it's a BlueMacro840
2. If your chip is locked: Select Programmer (use Black Magic Probe - Unlock and Erase)
3. Select Serial port from Programmer (there are 2, you may have to try each one)
4. Select "Burn Bootloader" while making sure there is good contact with the board. This will unlock the nrf52840 (or nrf52832)
5. If your chip is not locked: Select Programmer (use Black Magic Probe)
6. Select "Burn Bootloader" while making sure there is good contact with the board. This will flash the bootloader

There are 2 common errors:
* SWD Scan failed: this is generally due to a poor connection with the chip. Note that in the video, I give the BlueMacro840 and nRF52 GDB Debugger a gentle twist to make sure I have a good contact.
* Cannot flash because the chip is protected.  You need to "unlock and erase" before flashing the bootloader. 

## PCB
| Top  | Bottom  |
|---|---|
| |  |

## Schematic

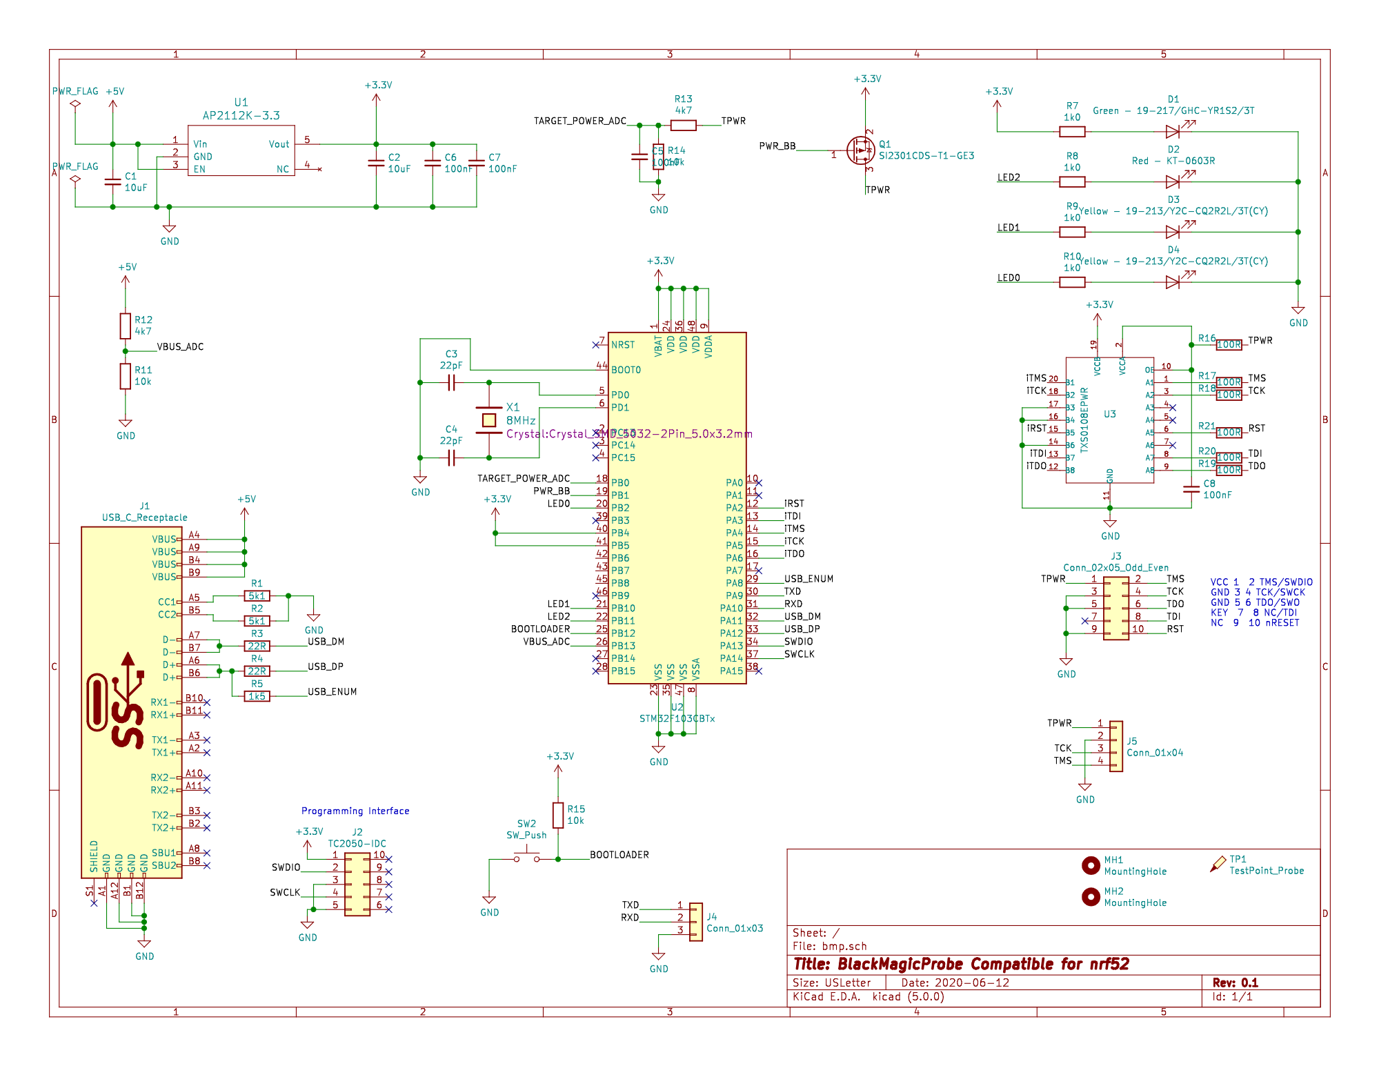
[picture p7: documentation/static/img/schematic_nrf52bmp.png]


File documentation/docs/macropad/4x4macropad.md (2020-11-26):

---
id: 4x4macropad
title: 4x4 Macropad
---

## Description

The 4x4 Macropad design was inspired from the 4x4 macropad from [40 percent club](https://www.40percent.club/2018/01/4x4x4x4x4.html). 

## Processor and Module

The Macropad uses the nRF52832 from Nordic Semiconductors. For an overview of the features of this SoC, refer to Nordic's [Product Page](https://www.nordicsemi.com/Products/Low-power-short-range-wireless/nRF52832).  The most important features are as follows:

* 64 MHz Cortex-M4 with FPU
* 512 KB Flash, 64 KB RAM
* 2.4 GHz Transceiver
* -20 to +4 dbm programmable TX Power
* 32 configurable GPIOs

For a detailed description of the nRF52832, you can download the [datasheet](http://infocenter.nordicsemi.com/pdf/nRF52832_PS_v1.4.pdf) (533 pages).

The Macropad uses the [Ebyte E73-2G4M04S1B module](https://s.click.aliexpress.com/e/_ACxA0g). This module is FCC and CE certified.  
The module uses a PCB antenna, has an external antenna connector and makes 30 GPIOs available externally, 1 of which is reserved for the reset button.  The bootloader and firmware may reserve specific GPIOs for specific functions (2 pins for serial, 1 pin for factory reset, 1 pin to put in DFU)
For a detailed description of the module, refer to the [manual](http://www.ebyte.com/en/downpdf.aspx?id=243).

If you want to replace the PCB antenna with an external antenna, the following [antenna](https://s.click.aliexpress.com/e/_A1WdTb) is the one that's designed by the module manufacturer.  The manual indicate the small surface mount resistor that needs moving to disconnect the PCB antenna and connect the external antenna.

## Bootloader

Although the Macropad can be programmed using the Nordic Software Development Kit and other commercial tools, we recommend using the open source [Adafruit nRF52 Bootloader](https://github.com/adafruit/Adafruit_nRF52_Bootloader) as the bootloader for the Macropad.  The Adafruit nRF52832 Feather bootloader is fully compatible with the Macropad.

You can obtain the bootloader from the following locations:

* release artifacts of the [Adafruit Repo](https://github.com/adafruit/Adafruit_nRF52_Bootloader/releases)
* release artifacts of the [Forked Repo](https://github.com/jpconstantineau/Adafruit_nRF52_Bootloader/releases)
* Adafruit nRF52 Arduino Board Support Package
* Community Add-on to Adafruit nRF52 Arduino Board Support Package

## Pinout

## PCB
| Top  | Bottom  |
|---|---|
|  |   |

## Schematic



## Build Guide

<iframe width="800" height="450" src="https://www.youtube.com/embed/ZNXx6ZQMCHM" frameborder="0" allow="accelerometer; autoplay; clipboard-write; encrypted-media; gyroscope; picture-in-picture" allowfullscreen></iframe>

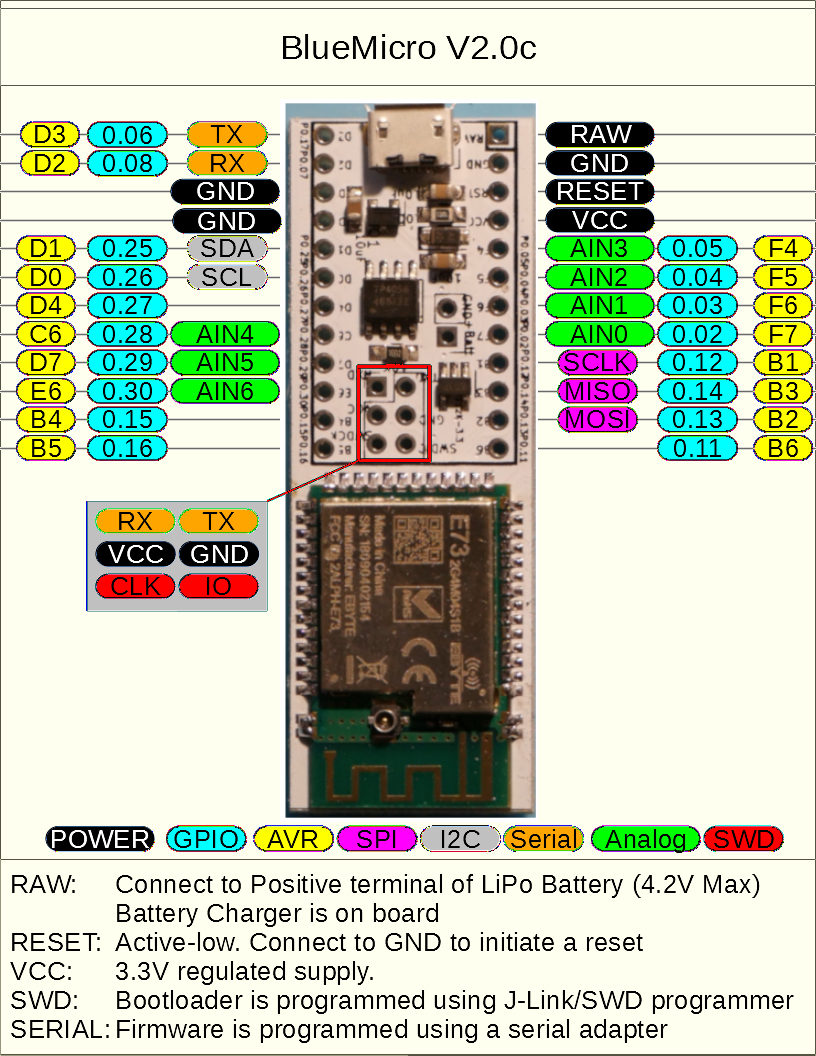
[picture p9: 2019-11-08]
BlueMicro2.0c/BlueMicro2.0c.pinout.png

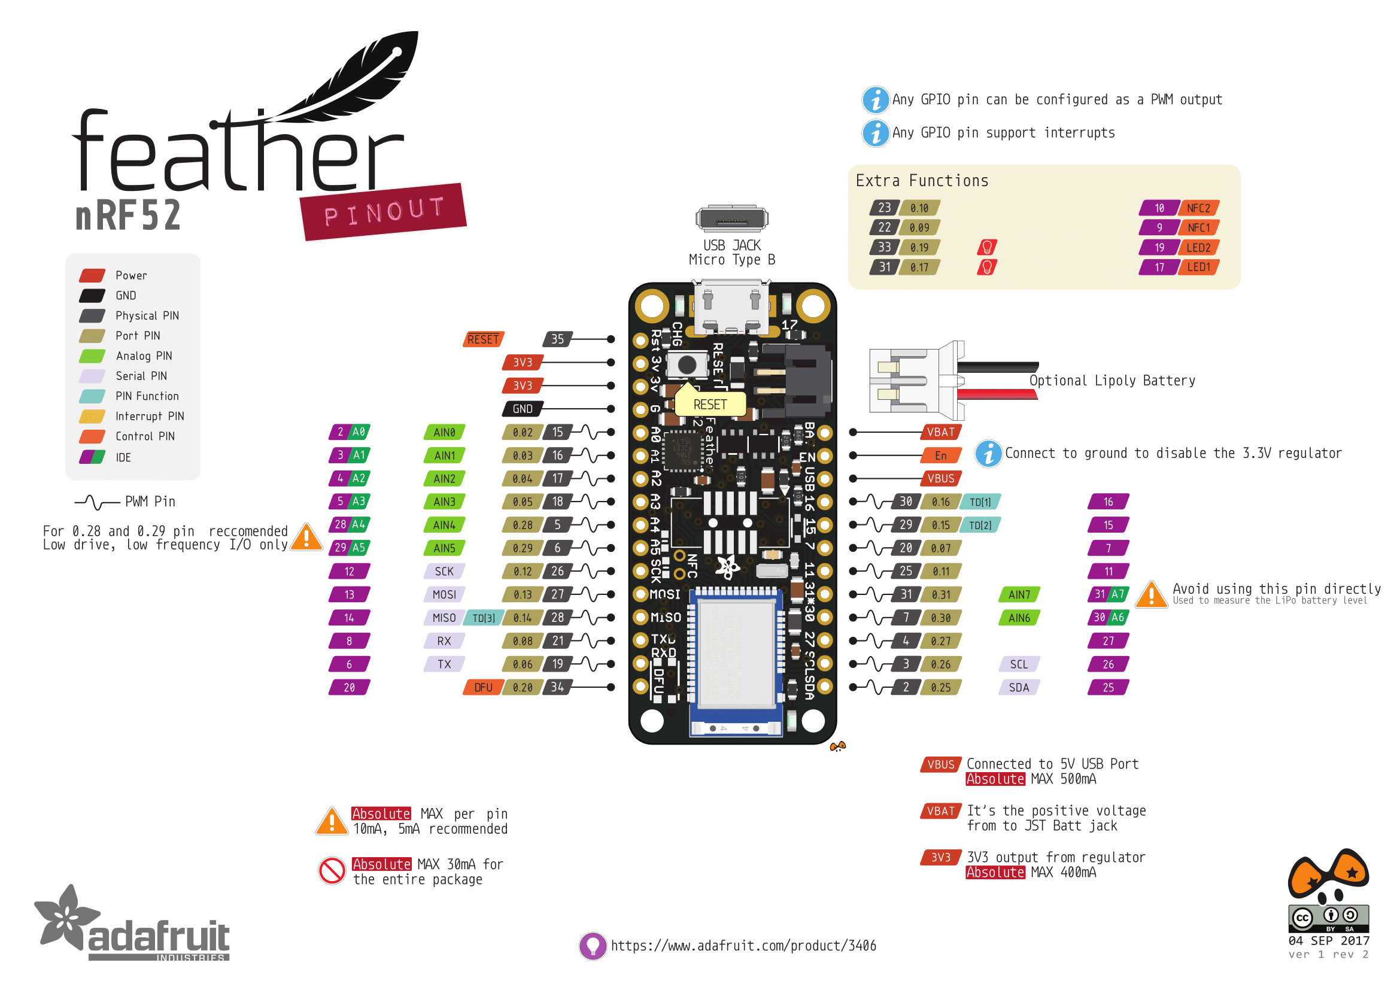
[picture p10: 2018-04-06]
Reference/microcontrollers_Feather_NRF52_Pinout_v1.2-1.png

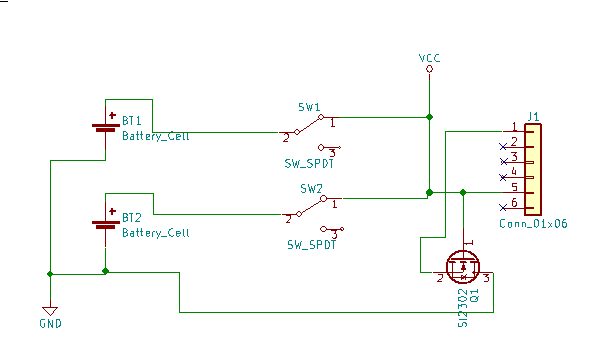
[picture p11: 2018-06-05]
Misc PCBs/CR2032_Battery/Schematic.PNG

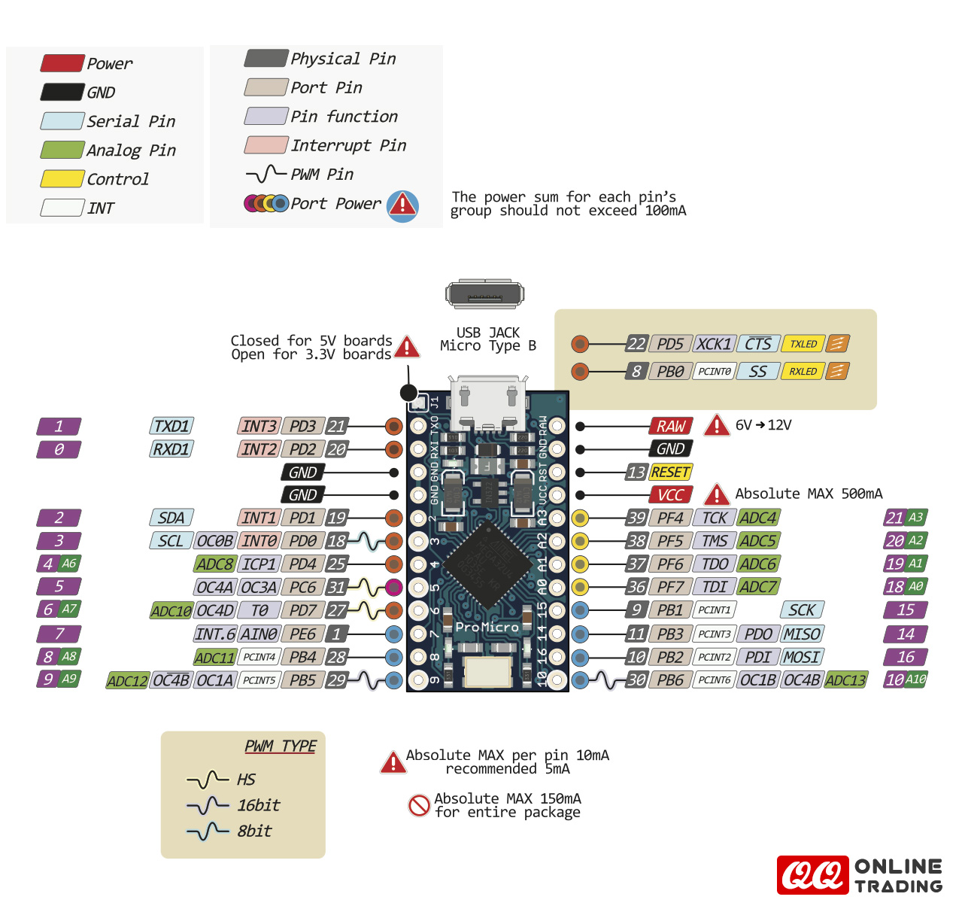
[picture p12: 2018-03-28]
Reference/pro_micro_pinout_v1_0_blue.jpg

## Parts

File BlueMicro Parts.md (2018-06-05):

BlueMicro Development Kits

**BlueMicro PCBs**

Contact /u/jpconstantineau for availability

- V1.0: suitable for the Ergotravel

- V1.1: suitable for any boards that uses the TX/RD arduino lines as GPIOs

**CR2032 Coin Cell holder:**

Contact /u/jpconstantineau for availability

This is an inexpensive way to power the BlueMicro.  Alternate methods will be to use a LiPo rechargable battery.  The Coin cell holder is designed to fit (with minor adjustments) in the ICP header of the Ergotravel. It also fits on the same header of the Iris. 
If using it directly in the header, the thickness of the board may need to be a bit thicker.

**NRF52832 Modules:**

Order directly from china on ebay or AliExpress

1 E73-2G4M04S1B Module: [ebay](https://www.ebay.com/itm/CE-FCC-nRF52832-E73-2G4M04S1B-2-4GHz-SMD-Wireless-Module-PCB-IPX-compatiable/192508539795) or [aliexpress](https://www.aliexpress.com/item/CDEBYTE-E73-2G4M04S-BLE-4-2-5-0-long-distance-100m-2-4GHz-SMD-ARM-Core/32820692238.html)

2 E73-2G4M04S1B Modules: [ebay]() or [aliexpress](https://www.aliexpress.com/item/CDEBYTE-E73-2G4M04S-BLE-4-2-5-0-long-distance-100m-2-4GHz-SMD-ARM-Core/32820692238.html)

**Programming Modules:**

Order directly from china on ebay or AliExpress

*Serial Programming Modules for BlueMicro*

CH340G Modules [ebay]() or [aliexpress](https://www.aliexpress.com/store/product/10PCS-replace-Pl2303-CP2102-USB-To-RS232TTL-CH340G-Converter-Module-Adapter-STC-NEW/2130127_32652163895.html)

CP2102 Modules [ebay]() or [aliexpress](https://www.aliexpress.com/item/1Pcs-CP2102-USB-2-0-to-TTL-UART-Module-6Pin-Serial-Converter-STC-Replace-FT232-Adapter/32279672853.html)

*SWD Programming Modules for BlueMicro*

Purple Jlink Clone [ebay]() or [aliexpress](https://www.aliexpress.com/item/CJMCU-Jlink-for-SWD-Jlink-3-Wire-for-STM32-on-SWD-Debug/32622682260.html)

Blue Jlink Clone [ebay]() or [Aliexpress](https://www.aliexpress.com/item/The-J-link-OB-ARM-emulator-debugger-j-link-programmer-downloader-link-instead-of-V8-SWD/32812820920.html)

Black j-Link Clone: [ebay]() or [aliexpress](https://www.aliexpress.com/item/Black-Plastic-ADS-IAR-STM32-JTAG-Interface-JLINK-V8-Debugger-ARM-ARM7-Emulator-Cortex-M4-M0/32810732789.html)

This module is useful on the black JLink: [aliexpress](https://www.aliexpress.com/item/SWD-TO-JTAG-Adapter-Board-For-STM32/32818529073.html)

NRD52 DK from Nordic Semiconductors contains a genuine j-link and can used to flash exterval boards. see [here](https://devzone.nordicsemi.com/f/nordic-q-a/20536/programming-external-custom-nrf52832-board-using-nrf52-dk) for instructions.

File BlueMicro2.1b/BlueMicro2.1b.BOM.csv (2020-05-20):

Comment | Designator | Footprint | LCSC | LCSC
1uF | C1 | Capacitor_SMD:C_0402_1005Metric |  | C52923
100nF | C2,C9,C10,C11,C12 | Capacitor_SMD:C_0402_1005Metric |  | C1525
10uF | C3,C5,C7,C8 | Capacitor_SMD:C_0402_1005Metric |  | C15525
100 pF | C4 | Capacitor_SMD:C_0402_1005Metric |  | C1546
1nF | C6 | Capacitor_SMD:C_0402_1005Metric |  | C1523
B5819W | D1 | Diode_SMD:D_SOD-123 |  | C8598
D | D2,D3 | Diode_SMD:D_SOD-123 |  | C81598
BLUE | D4 | LED_SMD:LED_0603_1608Metric |  | C72041
RED | D5,D6 | LED_SMD:LED_0603_1608Metric |  | C2286
USB_OTG | J1 | Connectors_USB:USB_Micro-B_Molex-105017-0001
Serial Connector | J2 | Pin_Headers:Pin_Header_Straight_2x03_Pitch2.54mm
Conn_01x02 | J3 | Pin_Headers:Pin_Header_Straight_1x02_Pitch2.54mm
10uH | L1 | Inductor_SMD:L_0805_2012Metric |  | C1046
SI2301CDS-T1-GE3 | Q1 | TO_SOT_Packages_SMD:SOT-23 |  | C10487
10k | R1 | Resistor_SMD:R_0402_1005Metric |  | C25744
100K | R2 | Resistor_SMD:R_0402_1005Metric |  | C25741
10K | R3 | Resistor_SMD:R_0402_1005Metric |  | C25744
806K | R4 | Resistor_SMD:R_0603_1608Metric |  | C23250
2M | R5 | Resistor_SMD:R_0603_1608Metric |  | C22976
1k | R6,R8,R9,R10 | Resistor_SMD:R_0402_1005Metric |  | C11702
JUMP | R7 | Resistor_SMD:R_0402_1005Metric |  | C17168
E73-2G4M04S | U1 | E73:E73-2G4M04S
ProMicro | U2 | footprints:Pro_Micro
AP2112K-3.3 | U3 | Package_TO_SOT_SMD:SOT-23-5 |  | C51118
CH340C | U4 | SMD_Packages:SO-16-N |  | C84681
TP4054ST | U6 | Package_TO_SOT_SMD:SOT-23-5 |  | C32574

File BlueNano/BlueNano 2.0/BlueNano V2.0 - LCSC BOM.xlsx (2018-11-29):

Quantity | Manufacture Part Number | Manufacturer(optional) | Description(optional) | LCSC Part Number(optional) | Package(optional)
10 | NRF52832-QFAA-R | Nordic Semiconductor | U1 - NRF52832 | C77540 | QFN-48_6x6x04P
10 | CP2104-F03-GM | SILICON LABS | U2 - USB Serial | C47742 | QFN-24_4x4x05P
10 | AP2112K-3.3TRG1 | Diodes Incorporated | U3 - LDO Regulator 3.3V | C51118 | SOT-25
10 | TP4054 | Nanjing Extension Microelectronics | U4 - TP4054 - LiPo Charger | C32574 | SOT-23-5
10 | X201632MKD4SI | Yangxing Tech | Y1 - 32Mhz | C108165 | SMD-2016_4P
10 | SC-32S32.768kHz20PPM9pF | Seiko Instruments | Y2 - 32.768khz | C97605 | SMD-3215_2P
10 | LQW15AN3N9B00D | Murata Electronics | L1 - 3.9nH | C98062 | 0402
50 | FC-DA1608HRK-620D | Foshan NationStar Optoelectronics | D1 - led red | C84263 | 0603
10 | B140WS-7 | Diodes Incorporated | D2 - schottky barier diode | C95171 | SOD-323
10 | LP0404N3T5G | Leshan Radio | Q1 mosfet p-channel | C172433 | SOT-883
10 |  | Jing Extension of the Electronic Co | J2 - Micro USB Connector | C10418 | SMD
50 | C0402C0G120K500NTB | Shenzhen Eyang Tech Development | C1,C2,C11,C12 - 12pF | C183716 | 0402
50 | C0402C0G0R8B500NTB | Shenzhen Eyang Tech Development | C3 - 0.8pF | C183713 | 0402
50 | GRM155R71A104KA01D | Murata Electronics | C4,C5,C8,C16,C18 - 100nF 0402 | C71687 | 0402
50 | 0402X106M6R3NT | Guangdong Fenghua Advanced Tech | C6, C14,C15,C17 - 10uF 0402 | C163694 | 0402
50 | 0402CG101J500NT | Guangdong Fenghua Advanced Tech | C7 - 100pF | C1546 | 0402
50 | 0402X475M100NT | Guangdong Fenghua Advanced Tech | C9 - 4.7uF | C167656 | 0402
50 | CL05X105KQ5NNNC | Samsung Electro-Mechanics | C10 - 1uF | C318566 | 0402
50 | 0402B102K500NT | Guangdong Fenghua Advanced Tech | C13 - 1nF | C1523 | 0402
100 | AC0402FR-07806KL | YAGEO | R1 - 806kohm | C227236 | 0402
100 | RC0402FR-072ML | YAGEO | R2 - 2MOhm | C138014 | 0402
100 | RC0402FR-0710KL | YAGEO | R3, R6 - 10kohm | C60490 | 0402
100 | RC0402FR-07330RL | YAGEO | R4 - 330ohm 0402 | C105875 | 0402
100 | 0402WGJ0104TCE | Uniroyal Elec | R5 - 100kohm | C25530 | 0402
100 | RC0402JR-071KL | YAGEO | R7 - 1k | C105637 | 0402
0 | CL10B105KO8NNNC | Samsung Electro-Mechanics | C10(V1.0) - 1uF 0603 | C59782 | 0603
0 | CL10A475KQ8NNNC | Samsung Electro-Mechanics | C9(V1.0) - 4.7uF 0603 | C8032 | 0603

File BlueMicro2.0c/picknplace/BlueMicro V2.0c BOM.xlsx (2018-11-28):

Item # | *Ref Des | *Qty | Manufacturer | *Mfg Part # | Description / Value | *Package | Type | Your Instructions / Notes
1 | U1 | DNP | ebyte | E73-2G4M04S1B | nRF52832 Bluetooth Module | Module | SMD | Do not source/install
2 | U2 | DNP | n/a | n/a | Pro Micro Footprint | DIP | thru-hole | Nothing to install
3 | U3 | 1 | Diodes Incorporated | AP2112K-3.3TRG1 | AP2112K-3.3 | SOT-25 | SMD
4 | U6 | 1 | Nanjing Extension Microelectronics | TP4056 | TP4056 | SOP-8_EP_150mil | SMD
5 | Q1 | 1 | NIKO Semicon | P5102FM | MOSFET P-Channel 20V 3.5A 900mV @ 250uA 45 mΩ @ 3.5A, 4.5V SOT-23(SOT-23-3) RoHS | SOT-23 | SMD
6 | D1 | 1 | SK | MBR120LSF | Schottky Barrier Diodes (SBD) SOD-123 RoHS | SOD-123 | SMD
7 | J1 | 1 | Jing Extension of the Electronic Co. | A01SB141B1-067 | LCSC MICRO USB 5S B Type horns High temperature | SMD | SMD | LCSC Part No: C10418
8 | L1 | 1 | Sunlord | SDFL2012S100KTF | 10 uH ±10% | 0805 | SMD | Replacement with similar part OK
9 | R1, R3 | 2 | YAGEO | RC0805FR-0710KL | Chip Resistor - Surface Mount 10KOhms ±1% 1/8W 0805 | 0805 | SMD | Replacement with similar part OK
10 | R2 | 1 | YAGEO | RC0805FR-07100KL | Chip Resistor - Surface Mount 100KOhms ±1% 1/8W 0805 RoHS | 0805 | SMD | Replacement with similar part OK
11 | R4 | 1 | YAGEO | AC0805FR-07806KL | Chip Resistor - Surface Mount 806KOhms ±1% 1/8W 0805 RoHS | 0805 | SMD | Replacement with similar part OK
12 | R5 | 1 | YAGEO | RC0805JR-072ML | Chip Resistor - Surface Mount 2MOhms ±5% 1/8W 0805 RoHS | 0805 | SMD | Replacement with similar part OK
13 | C3, C5, C7, C8 | 4 | Samsung Electro-Mechanics | CL21A106KOQNNNE | Multilayer Ceramic Capacitors MLCC - SMD/SMT 10uF 16V 0805 RoHS | 0805 | SMD | Replacement with similar part OK
14 | C6 | 1 | Guangdong Fenghua Advanced Tech | 0805CG102J500NT | Multilayer Ceramic Capacitors MLCC - SMD/SMT 1nF 50V 0805 RoHS | 0805 | SMD | Replacement with similar part OK
15 | C4 | 1 | YAGEO | CC0805KRX7R9BB101 | Multilayer Ceramic Capacitors MLCC - SMD/SMT 100pF 50V 0805 RoHS | 0805 | SMD | Replacement with similar part OK
16 | C1 | 1 | Samsung Electro-Mechanics | CL21B105KAFNFNE | Multilayer Ceramic Capacitors MLCC - SMD/SMT 1uF 25V 0805 RoH | 0805 | SMD | Replacement with similar part OK
17 | C2 | 1 | Guangdong Fenghua Advanced Tech | 0805B104K500NT | Multilayer Ceramic Capacitors MLCC - SMD/SMT 100nF 50V 0805 RoHS | 0805 | SMD | Replacement with similar part OK
 | DNP= Do not populate
 | * Must filled

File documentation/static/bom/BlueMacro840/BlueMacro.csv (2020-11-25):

Comment | Designator | Footprint | LCSC | LCSC
22pF | C1,C2 | Capacitor_SMD:C_0603_1608Metric |  | C1653
10uF | C3,C5,C4 | Capacitor_SMD:C_0603_1608Metric |  | C19702
1nF | C6 | Capacitor_SMD:C_0603_1608Metric |  | C1588
B5819W | D1 | Diode_SMD:D_SOD-123 |  | C8598
19-217/GHC-YR1S2/3T | D2 | LED_SMD:LED_0603_1608Metric |  | C72043
KT-0603R | D3 | LED_SMD:LED_0603_1608Metric |  | C2286
19-217/BHC-ZL1M2RY/3T | D4 | LED_SMD:LED_0603_1608Metric |  | C72041
Conn_01x02 | J1 | Connector_PinHeader_2.54mm:PinHeader_1x02_P2.54mm_Vertical
USB_C_Receptacle | J3 | footprints:HRO-TYPE-C-31-M-12-C165948 |  | C165948
L | L1 | Inductor_SMD:L_0805_2012Metric |  | C1046
SI2301CDS-T1-GE3 | Q1 | Package_TO_SOT_SMD:SOT-23 |  | C10487
100k | R1 | Resistor_SMD:R_0603_1608Metric |  | C25803
10k | R2 | Resistor_SMD:R_0603_1608Metric |  | C25804
1k | R3,R7,R8 | Resistor_SMD:R_0603_1608Metric |  | C21190
806k | R4 | Resistor_SMD:R_0603_1608Metric |  | C23250
2M | R5 | Resistor_SMD:R_0603_1608Metric |  | C22976
5.1k | R6,R9 | Resistor_SMD:R_0603_1608Metric |  | C23186
VCC | TP1 | footprints:TestPoint_THTPad_1.1x1.1mm_Drill0.8mm
GND | TP2 | footprints:TestPoint_THTPad_1.1x1.1mm_Drill0.8mm
SWDCK | TP3 | footprints:TestPoint_THTPad_1.1x1.1mm_Drill0.8mm
SDWIO | TP4 | footprints:TestPoint_THTPad_1.1x1.1mm_Drill0.8mm
TP4054ST | U1 | Package_TO_SOT_SMD:SOT-23-5 |  | C32574
E73-2G4M08S1C | U2 | E73:E73-2G4M08S1C-52840
AP2112K-3.3TRG1 | U3,U5 | Package_TO_SOT_SMD:SOT-23-5 |  | C51118
Micro | U4 | E73:arduino_micro
32.768kHz | Y1 | Crystal:Crystal_SMD_3215-2Pin_3.2x1.5mm |  | C32346

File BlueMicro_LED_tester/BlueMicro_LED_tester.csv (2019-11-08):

Comment | Designator | Footprint | LCSC
LED | D1,D12,D13,D14,D15,D16,D17,D18,D19,D20,D2,D3,D4,D5,D6,D7,D8,D9,D10,D11 | LED_SMD:LED_0603_1608Metric | C2286
DNP | J1 | Connector_PinHeader_2.54mm:PinHeader_1x02_P2.54mm_Vertical
2k2 | R1,R12,R13,R14,R15,R16,R17,R18,R19,R20,R2,R3,R4,R5,R6,R7,R8,R9,R10,R11 | Resistor_SMD:R_0603_1608Metric | C4190
SW_PUSH | SW1 | footprints:SW_TACT_ALPS_SKQGABE010 | C318884
DMP | U1 | footprints:Pro_Micro

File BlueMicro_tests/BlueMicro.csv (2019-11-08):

Comment | Designator | Footprint | LCSC
1uF | C1 | Capacitor_SMD:C_0603_1608Metric
1nF | C14 | Capacitor_SMD:C_0603_1608Metric
0.1uF | C2,C10 | Capacitor_SMD:C_0603_1608Metric
10uF | C3,C12,C11,C13 | Capacitor_SMD:C_0603_1608Metric
100pF | C4 | Capacitor_SMD:C_0603_1608Metric
22pF | C5,C8 | Capacitor_SMD:C_0603_1608Metric
100nF | C7,C9,C6 | Capacitor_SMD:C_0603_1608Metric
BLUE | D1 | LED_SMD:LED_0603_1608Metric
RED | D2,D5,D6,D10 | LED_SMD:LED_0603_1608Metric
1N4148W | D3,D4,D7 | Diode_SMD:D_SOD-123
B5819W | D8 | Diode_SMD:D_SOD-123
GREEN | D9 | LED_SMD:LED_0603_1608Metric
Conn_01x02 | J10 | Connector_PinHeader_2.54mm:PinHeader_1x02_P2.54mm_Vertical
USB_B_Micro | J17 | Connector_USB:USB_Micro-B_Molex-105017-0001
Conn_01x04 | J9 | Connector_PinHeader_2.54mm:PinHeader_1x04_P2.54mm_Vertical
10uH | L1 | Inductor_SMD:L_0603_1608Metric
Si2301CDS | Q1 | Package_TO_SOT_SMD:SOT-23
10k | R1,R7,R9 | Resistor_SMD:R_0603_1608Metric
806k | R11 | Resistor_SMD:R_0603_1608Metric
2M | R12 | Resistor_SMD:R_0603_1608Metric
1k | R2,R3,R4,R5,R6,R10 | Resistor_SMD:R_0603_1608Metric
100k | R8 | Resistor_SMD:R_0603_1608Metric
TestPoint_Probe | TP1,TP2,TP3,TP4,TP5,TP6,TP7 | TestPoint:TestPoint_Pad_1.0x1.0mm
E73-2G4M04S | U1 | E73:E73-2G4M04S
CH340G | U2 | Package_SO:SOP-16_4.4x10.4mm_P1.27mm
TP4056 | U3 | Package_SO:SSOP-8_3.95x5.21x3.27mm_P1.27mm
AP2112K-3.3 | U4 | Package_TO_SOT_SMD:SOT-23-5
ProMicro | U5 | footprints:Pro_Micro
12MHz | Y1 | Crystal:Crystal_SMD_3225-4Pin_3.2x2.5mm

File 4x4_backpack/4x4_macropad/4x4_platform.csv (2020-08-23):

Comment | Designator | Footprint | LCSC | LCSC
Battery_Cell | BT1 | E73:Keystone_1058_1x2032-CoinCell
1uF | C1 | Capacitor_SMD:C_0805_2012Metric_Pad1.15x1.40mm_HandSolder |  | C28323
1nF | C14 | Capacitor_SMD:C_0805_2012Metric_Pad1.15x1.40mm_HandSolder |  | C46653
100nF | C2,C7,C9,C6,C10 | Capacitor_SMD:C_0805_2012Metric_Pad1.15x1.40mm_HandSolder |  | C49678
10uF | C3,C12,C11,C13 | Capacitor_SMD:C_0805_2012Metric_Pad1.15x1.40mm_HandSolder |  | C15850
100pF | C4 | Capacitor_SMD:C_0805_2012Metric_Pad1.15x1.40mm_HandSolder |  | C1790
BLUE | D1 | LED_SMD:LED_0805_2012Metric_Pad1.15x1.40mm_HandSolder |  | C2293
RED | D2,D10 | LED_SMD:LED_0805_2012Metric_Pad1.15x1.40mm_HandSolder |  | C84256
1N4148 | D3,D4,D7 | Diode_SMD:D_SOD-123 |  | C81598
B5819W | D8 | Diode_SMD:D_SOD-123 |  | C8598
Conn_01x04 | J1,J2,J3,J4,J5,J6,J7,J8 | Connector_PinHeader_2.54mm:PinHeader_1x04_P2.54mm_Vertical
Conn_01x02 | J10 | Connector_PinHeader_2.54mm:PinHeader_1x02_P2.54mm_Vertical
Conn_01x01 | J11,J12,J13,J14,J15,J16 | MountingHole:MountingHole_2.2mm_M2_ISO7380
USB_B_Micro | J17 | Connector_USB:USB_Micro-B_Molex-105017-0001
Conn_02x05_Counter_Clockwise | J9 | Connector:Tag-Connect_TC2050-IDC-NL_2x05_P1.27mm_Vertical
10uH | L1 | Capacitor_SMD:C_0805_2012Metric_Pad1.15x1.40mm_HandSolder |  | C1046
SI2301CDS-T1-GE3 | Q1 | Package_TO_SOT_SMD:SOT-23 |  | C10487
10k | R1 | Capacitor_SMD:C_0805_2012Metric_Pad1.15x1.40mm_HandSolder |  | C17414
806k | R11 | Resistor_SMD:R_0805_2012Metric_Pad1.15x1.40mm_HandSolder |  | C63494
2M | R12 | Resistor_SMD:R_0805_2012Metric_Pad1.15x1.40mm_HandSolder |  | C26112
1k | R2,R3,R4,R10 | Resistor_SMD:R_0805_2012Metric_Pad1.15x1.40mm_HandSolder |  | C17513
10k | R7 | Resistor_SMD:R_0805_2012Metric_Pad1.15x1.40mm_HandSolder |  | C17414
100k | R8 | Resistor_SMD:R_0805_2012Metric_Pad1.15x1.40mm_HandSolder |  | C17407
SW_SPDT | SW1 | E73:SPDT_C128955
RESET | SW2 | E73:SW_TACT_ALPS_SKQGABE010 |  | C318884
E73-2G4M04S | U1 | E73:E73-2G4M04S
CH340C | U2 | Package_SO:SOP-16_4.4x10.4mm_P1.27mm |  | C84681
TP4056 | U3 | Package_SO:SSOP-8_3.95x5.21x3.27mm_P1.27mm |  | C16581
AP2112K-3.3 | U4 | Package_TO_SOT_SMD:SOT-23-5 |  | C51118

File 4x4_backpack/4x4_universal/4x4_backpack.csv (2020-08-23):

Comment | Designator | Footprint | LCSC
DIODE | D1,D3,D4,D2,D8,D7,D6,D5,D9,D10,D11,D12,D14,D13,D15,D16 | footprints:D_SOD123_axial-dual
Conn_01x04 | J1,J2,J3,J4,J5,J6,J7,J8 | Connector_PinHeader_2.54mm:PinHeader_1x04_P2.54mm_Vertical
Conn_01x01 | J11,J12,J13,J14,J15,J16 | MountingHole:MountingHole_2.2mm_M2_ISO7380
CHERRY_MX | S1,S5,S10,S13,S2,S3,S4,S6,S7,S8,S11,S9,S12,S14,S15,S16 | footprints:MX-Alps-Choc-1U

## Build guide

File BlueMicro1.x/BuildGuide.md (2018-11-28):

# BlueMicro V1.x Build Guide

Line up all the components - in their bags.  DO NOT remove SMD components from bags yet! You can't differentiate them.  Assembly steps for the V1.0 are identical.

Let's start with 1 capacitor.  Always open 1 bag at a time.  This makes sure that all free components on the bench are identical.

Place a bit of solder on one of the pads.

Melt solder, Place capacitor, remove soldering iron while holding the capacitor. Rotate board for easier access of the other side.  Solder the other side of the capacitor.

Capacitor Installed.

Install the capacitor

Inductor installed (missing picture) - Install the last Capacitor on this side.

Back side complete.

Install the Resistor.

Finish with the last capacitor.

Now that all discrete components are installed, let's get ready with the module.

Use Painter's tape to hold the module in place.

Align the connections.

Be careful of the alignment in both directions - on all 3 sides.

Module "tacked" in place.  Remove the tape.

Module "tacked" in place.  From here on, solder all the joints.

Module "tacked" in place.  From here on, solder all the joints.

Using Diode Legs to create pins to socket the BlueMicro.  Note the use of Painter's tape to make sure that the legs don't get soldered into the socket.  Note that the Reset and DFU switches were installed prior to this step.  For a split keyboard, it's common to have to have the Pro Micro face down on one half and face up on the other half.  The switches are soldered on top for one and on the bottom for the other Blue Micro.  This allows for easy access to the switches once installed in the keyboard halves.

Using Diode Legs to create pins to socket the BlueMicro.
Note the use of other sockets to help with alignment and holding the SIP sockets in place.

BlueMicro with legs.

Verify that all legs are the same length.

Note mistake made: Shorter leg.  This will not contact in the socket properly.  Must be fixed before continuing.

Let's Get Ready to Flash the Bootloader - You will need a J-link.  Here I am showing the blue chinese clone.  The Purple chinese and black chinese clones work too.  If you have a genuine j-link, use that.  If you have a NRF52-DK, you can use it too since it contains a j-link

The blue Chinese j-link clone supplies +3.3V.  You can connect it to the central header of the BlueMicro.

Once the bootloader if flashed, the firmware can be flashed using a serial adapter.  Note that the serial adapter supplied 3.3V and is connected to the central header.  Note that the TX is connected to RX and RX is connected to TX.

Flashing the Firmware using Serial connection

The BlueMicro and the CR2032 battery in an Iris

The Black Chinese J-Link Clone with the adapter supplied 3.3V. It can connect directly to the central header of the BlueMicro.

The Purple Chinese J-Link Clone with the adapter DOES NOT supply 3.3V. It can connect directly to the central header of the BlueMicro but a 3V source must supply power to the BlueMicro.  In this case, the CR2032 coin cell works perfectly.

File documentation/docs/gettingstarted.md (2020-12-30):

---
id: gettingstarted
title: Overview
slug: /
---

### What are they?

The BlueMicro boards are designed to be used with the Adafruit nRF52 Arduino Core but with the footprint of other Arduino boards such as the Arduino Pro Micro and the Arduino Micro.  

### Why?

Many DIY keyboards use the Arduino Pro Micro or the Arduino Micro as their microcontroller.  These don't support BLE communications natively.   Because the nRF52 chips have a 32-bit ARM Cortex-M4F processor, they have plenty of processing power compared to the traditional AVR chips. The BlueMicro boards were inspired from the Adafruit nrf52 feathers but made to be used directly in DIY keyboards as a replacement for the atmega32u4 based controllers.  By taking the schematic of the Feather and making a breakout board that matches the Arduino Pro Micro, I was able to replace the Pro Micros in my keyboards.

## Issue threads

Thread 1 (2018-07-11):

YJ-14015 setup

joric, 2018-07-11:
YJ-14015 is nRF51 but all the Adafruit nRF52 Arduino documentation is about nRF52, and s132 softdevice isn't compatible with nRF51 either. Is it supposed to use Arduino-nRF5 by Sandeep Mistry?

jpconstantineau, 2018-07-11:
You are right. This isn't for the BlueMicro software which needs SoftDevice S132 and not S130.

This hardware board is intended as a breakout board for the YJ14015 modules.
I have a few of these modules on hand but the current board has a problem with the module footprint.

joric, 2018-07-11:
I've just managed to run [Arduino-nRF5 by Sandeep Mistry](https://github.com/sandeepmistry/arduino-nRF5) on a similar to YJ-14015 nRF51 chip (Waveshare Core51822 and BLE400 board with ST-Link v2, pretty generic) in arduino IDE, just followed instructions. Not sure there's a Bluefruit library but it works.
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

joric, 2018-07-11:
Managed to make it work as a HID keyboard using unmodified HID sample from https://github.com/sandeepmistry/arduino-BLEPeripheral and get output from the BLE400 built in UART. So yeah, it's all very doable. I'll post my progress at https://github.com/joric/mitosis/tree/devel/

Closed 2018-08-13.

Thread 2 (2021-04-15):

4x4 Bluetooth Macropad Rotary Encoder

bentemple, 2021-04-15:
Just wondering if there are a few open pins that I could hook up a rotary encoder to to include one with my 4x4 bluetooth macropad.

Sorry, couldn't find your email or a way to contact so thought this might be a reasonable place to reach you on. Thanks in advance for any help!

bentemple, 2021-04-15:
NVM, found email. I'm stupid

Closed 2021-04-15.

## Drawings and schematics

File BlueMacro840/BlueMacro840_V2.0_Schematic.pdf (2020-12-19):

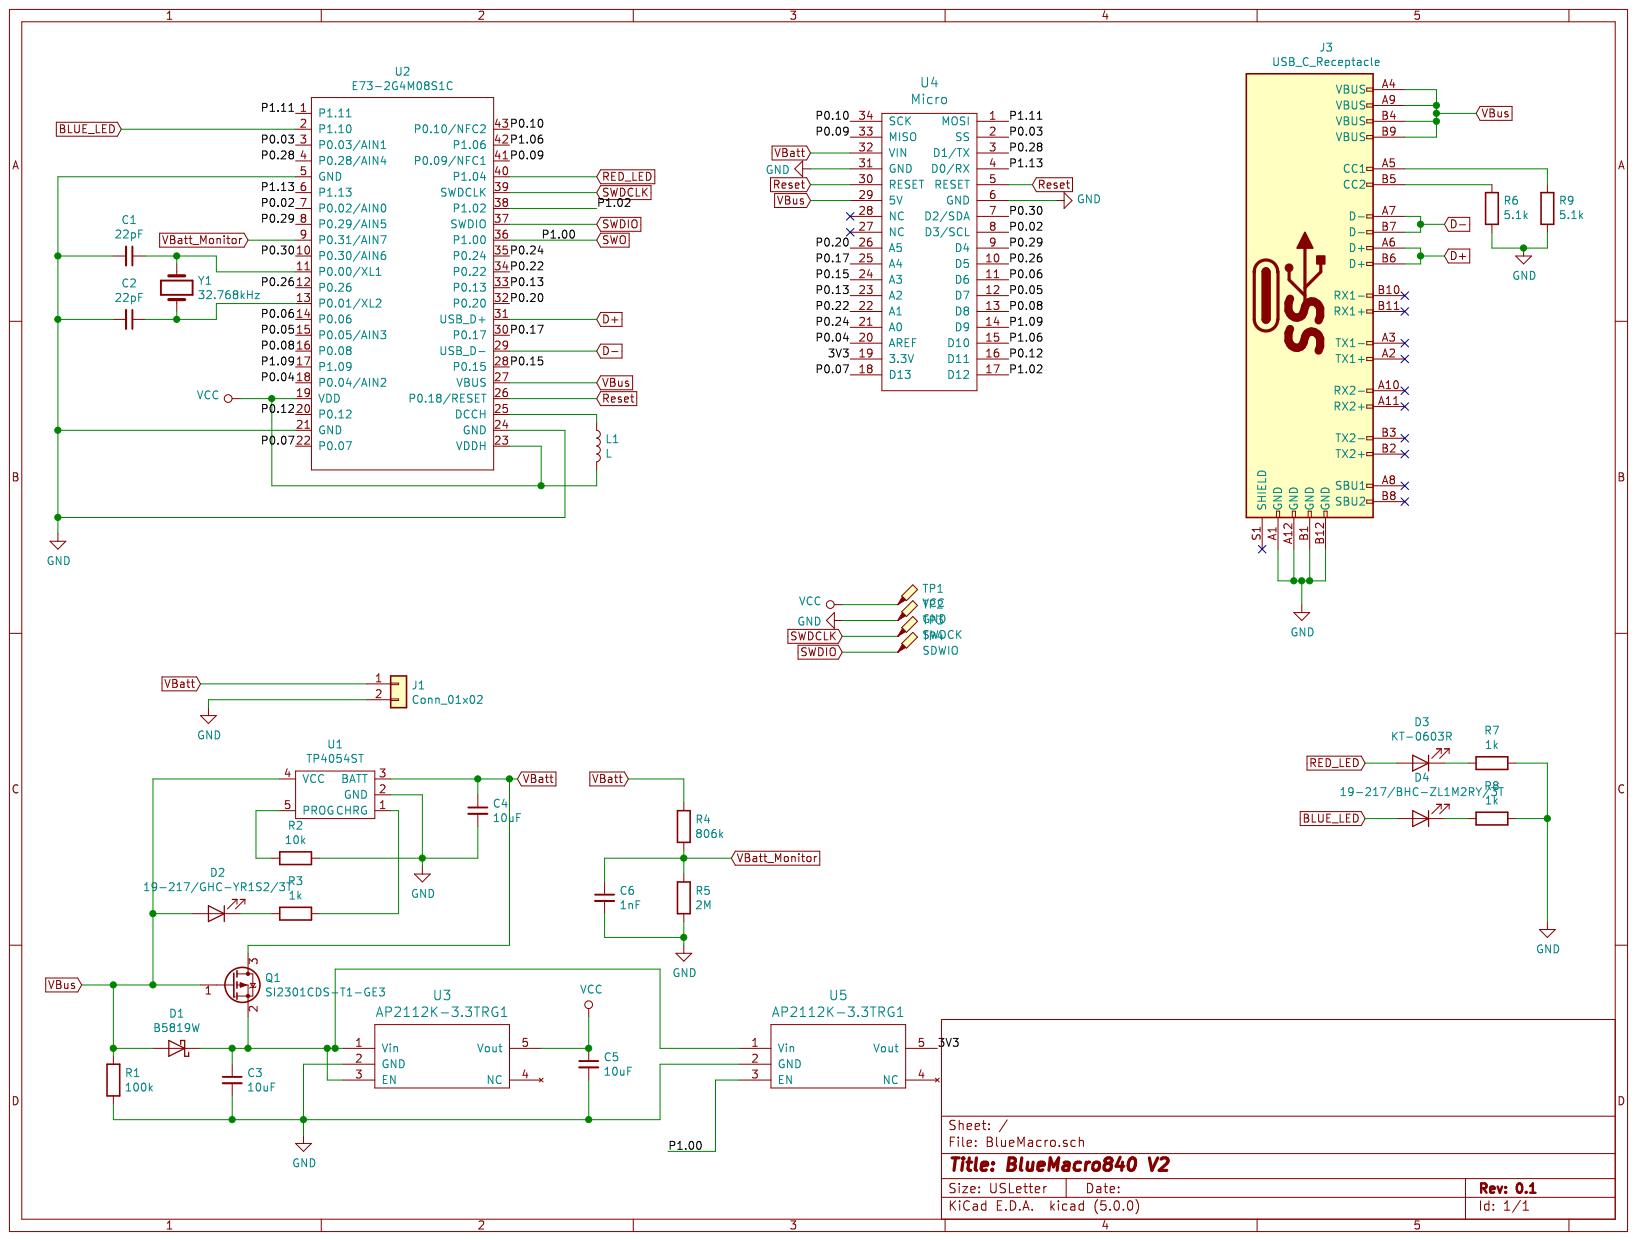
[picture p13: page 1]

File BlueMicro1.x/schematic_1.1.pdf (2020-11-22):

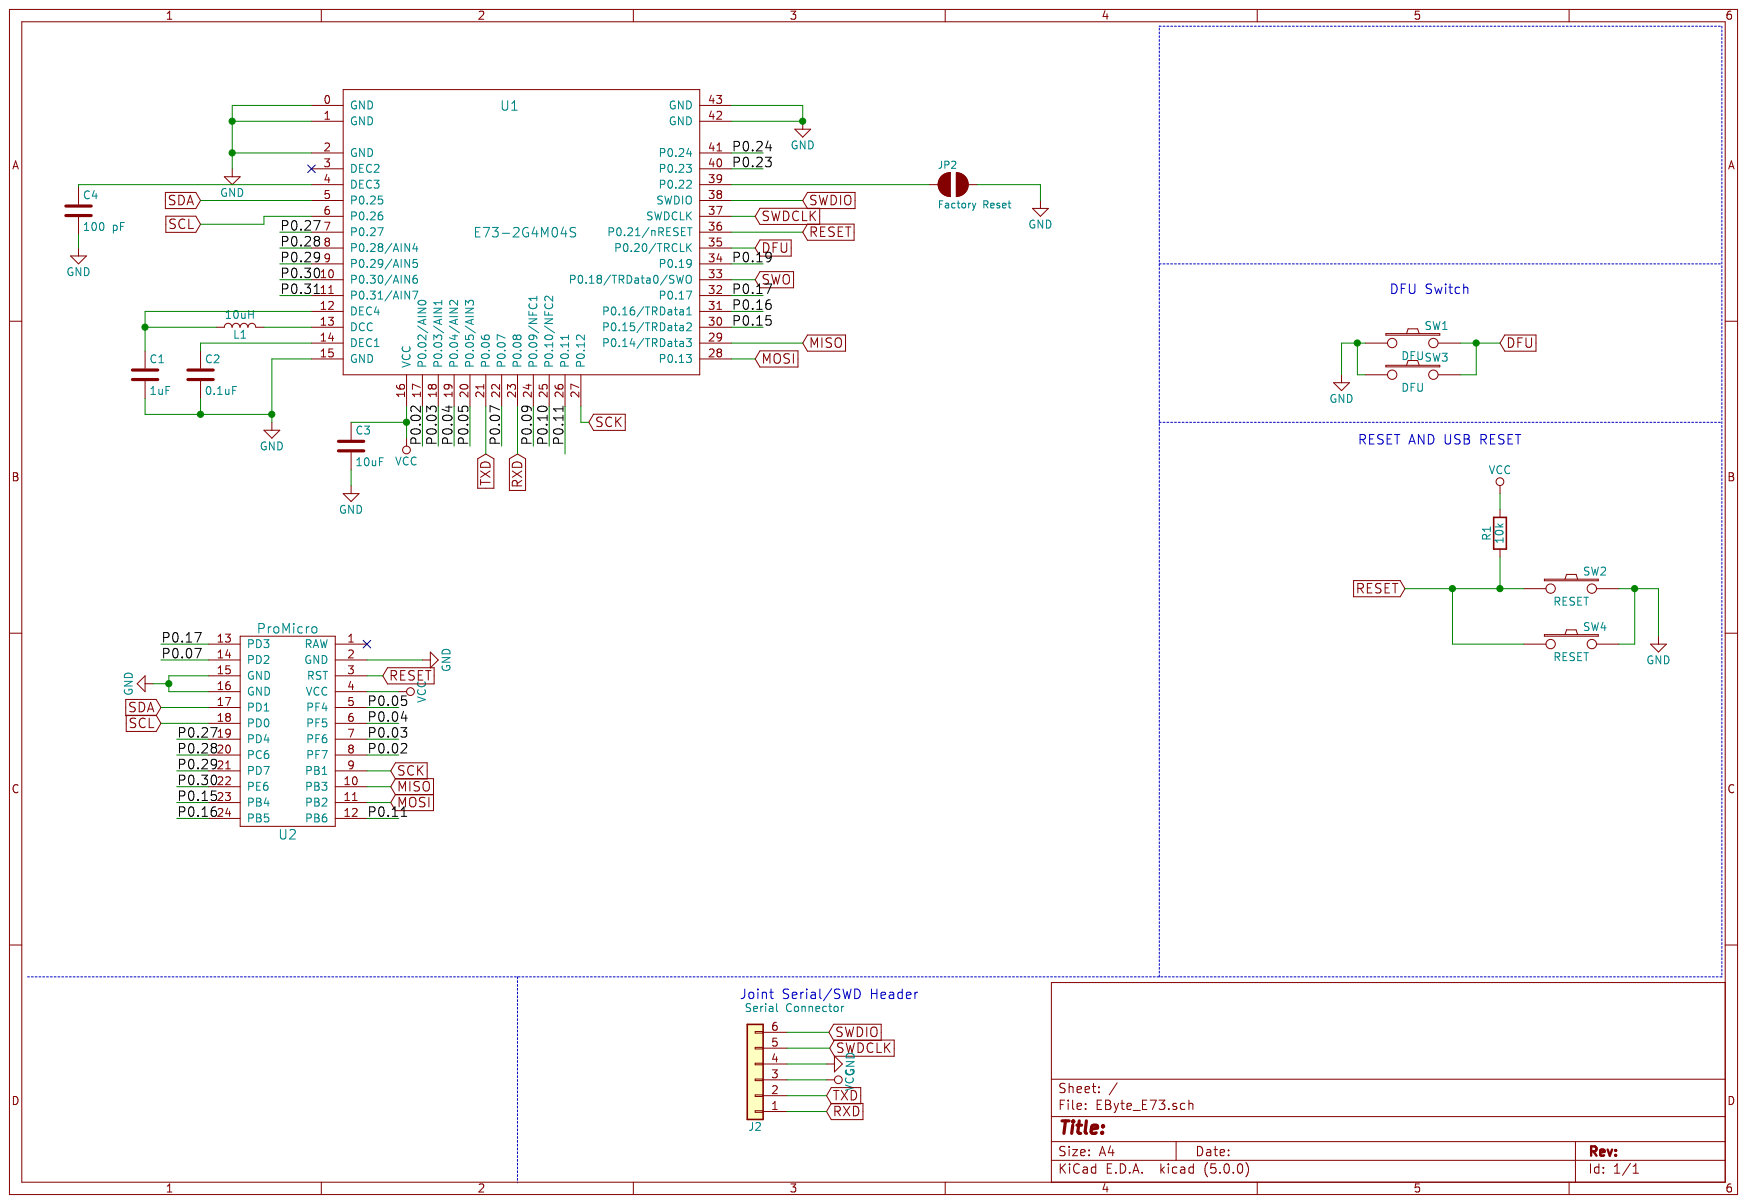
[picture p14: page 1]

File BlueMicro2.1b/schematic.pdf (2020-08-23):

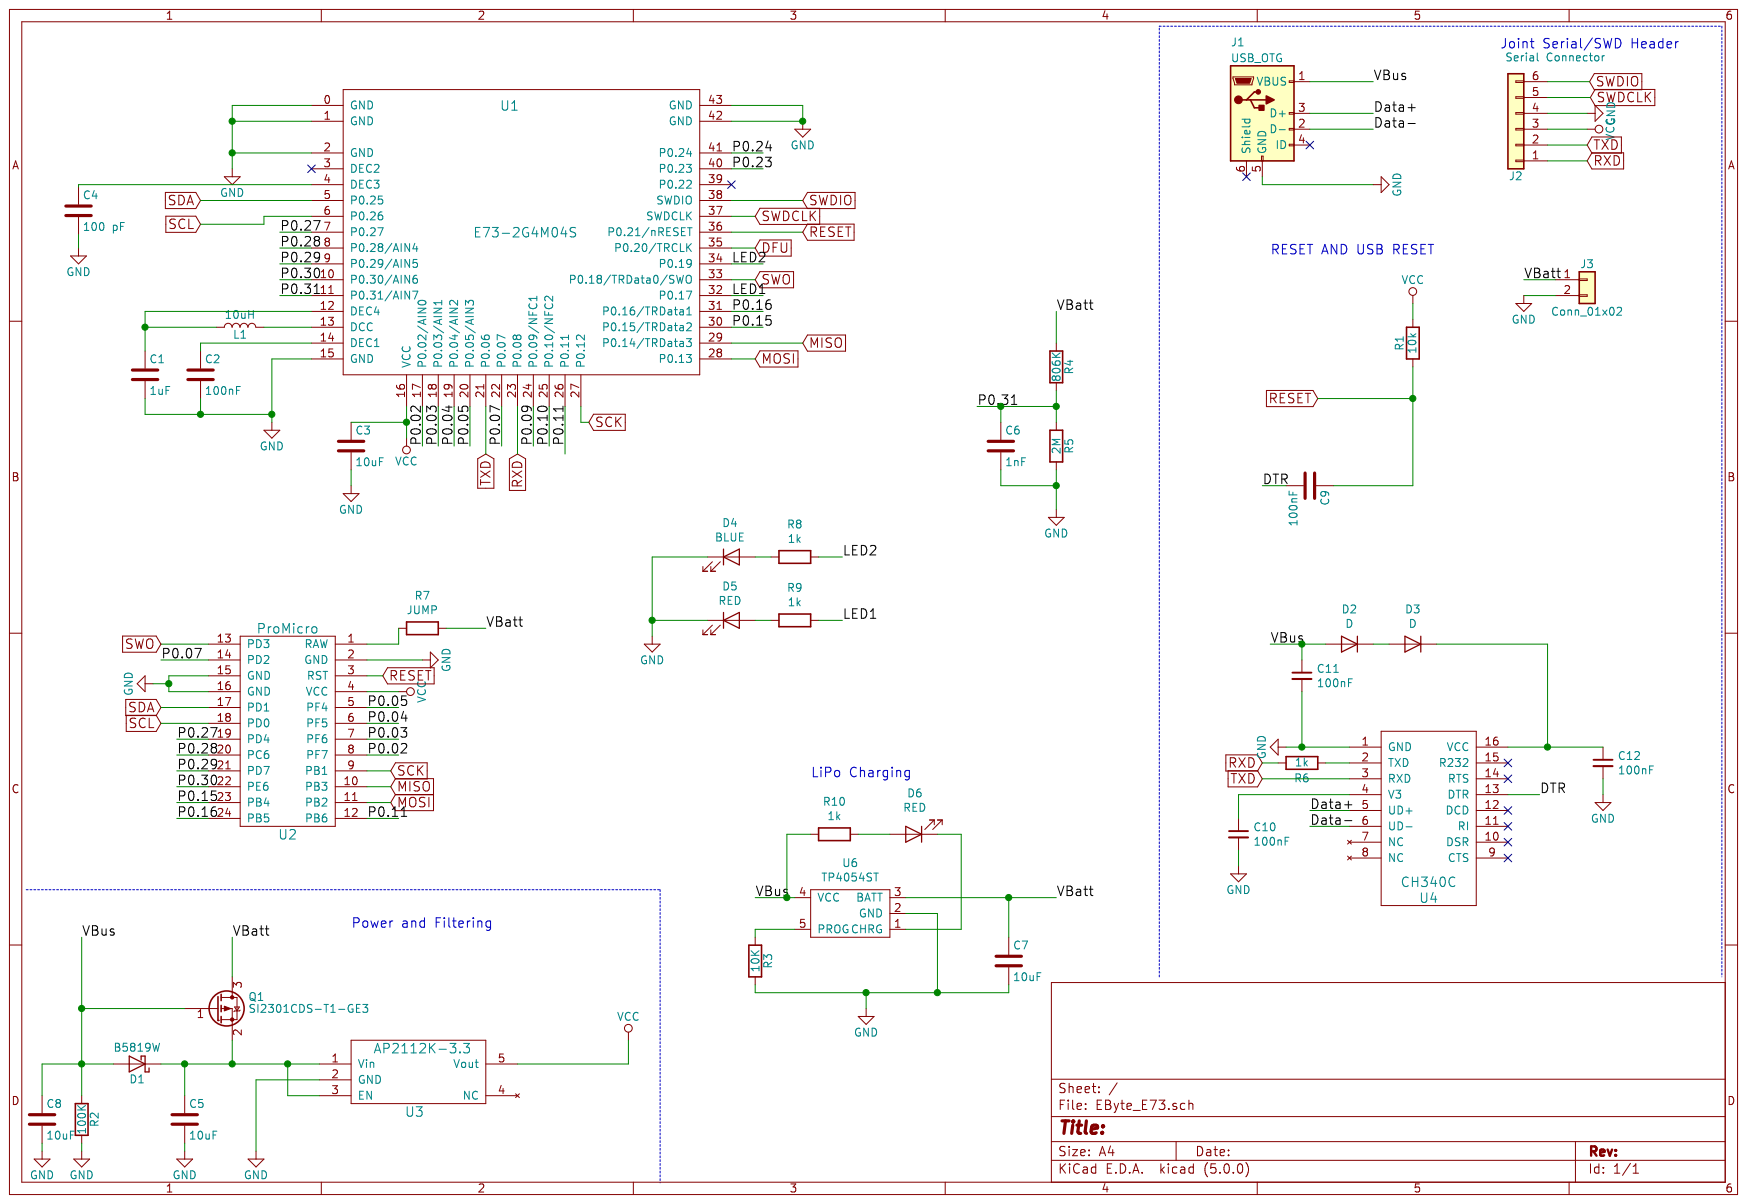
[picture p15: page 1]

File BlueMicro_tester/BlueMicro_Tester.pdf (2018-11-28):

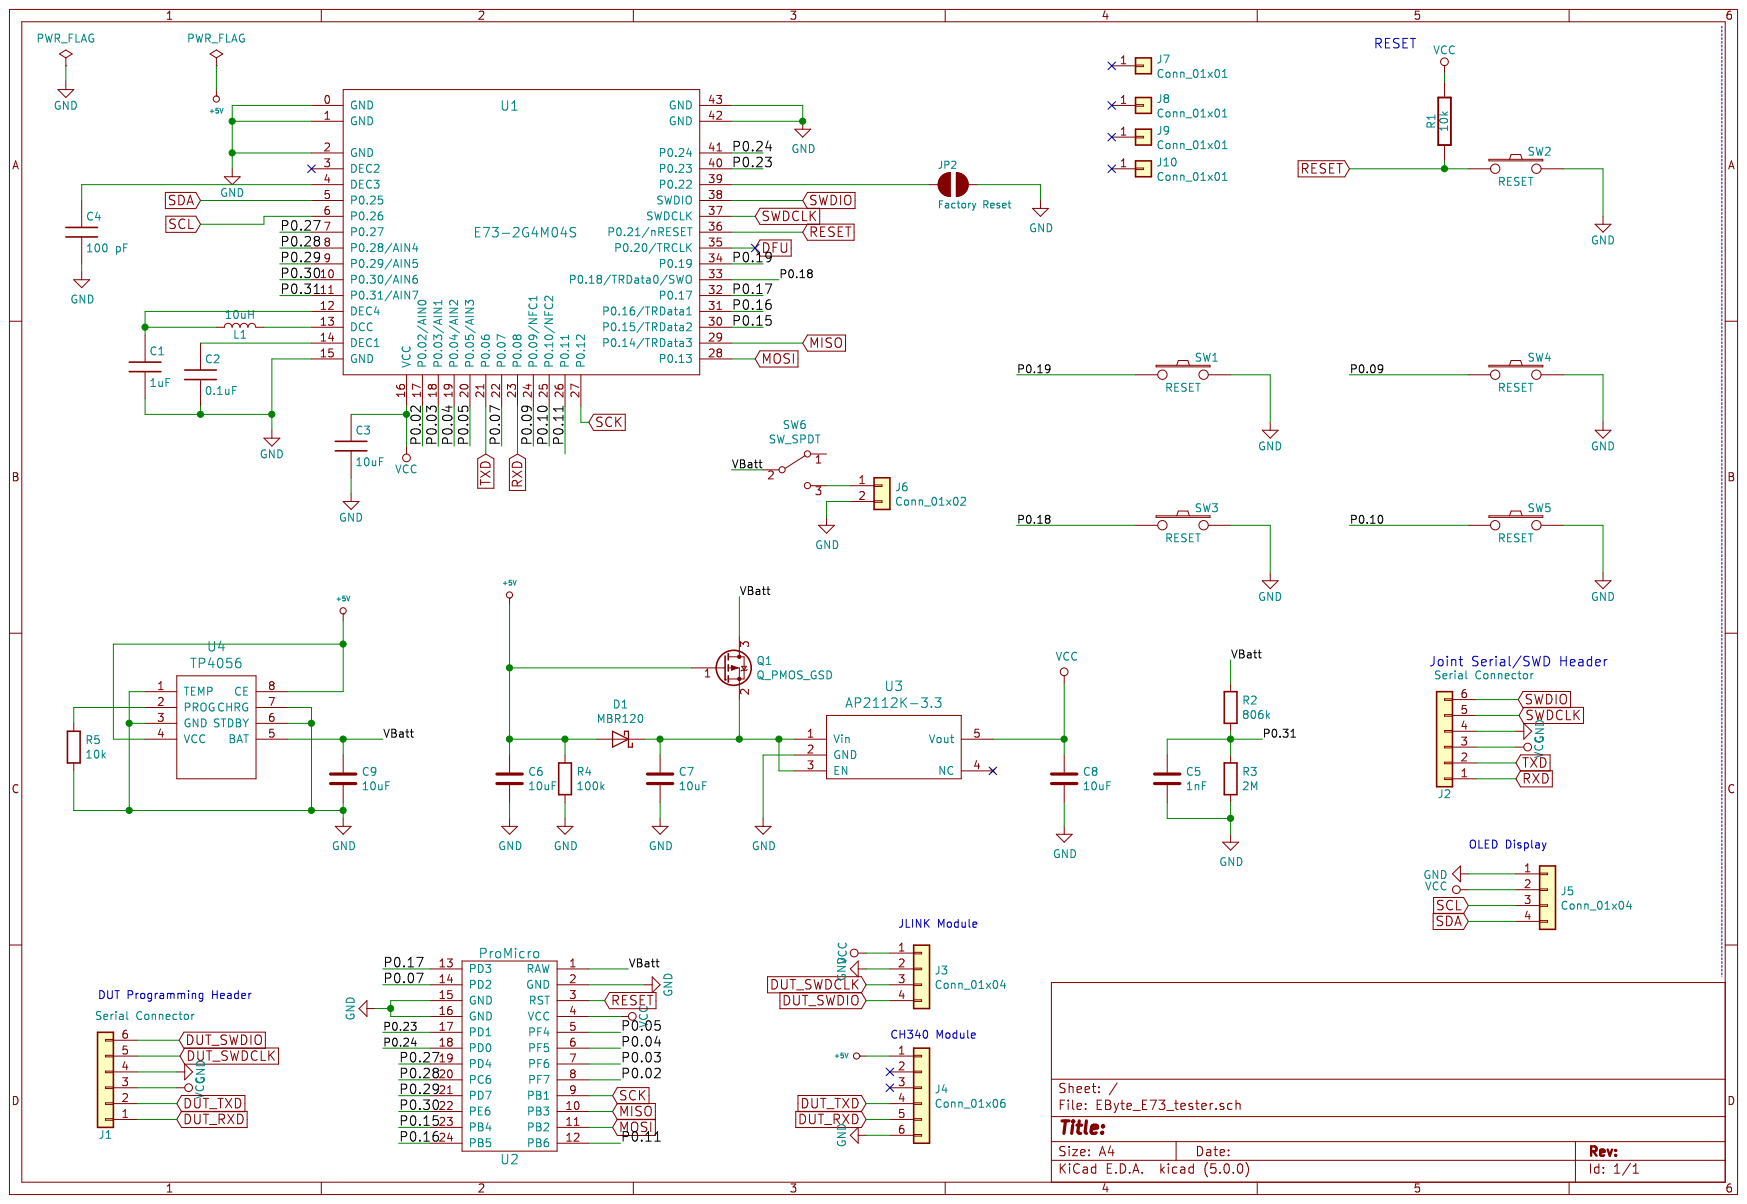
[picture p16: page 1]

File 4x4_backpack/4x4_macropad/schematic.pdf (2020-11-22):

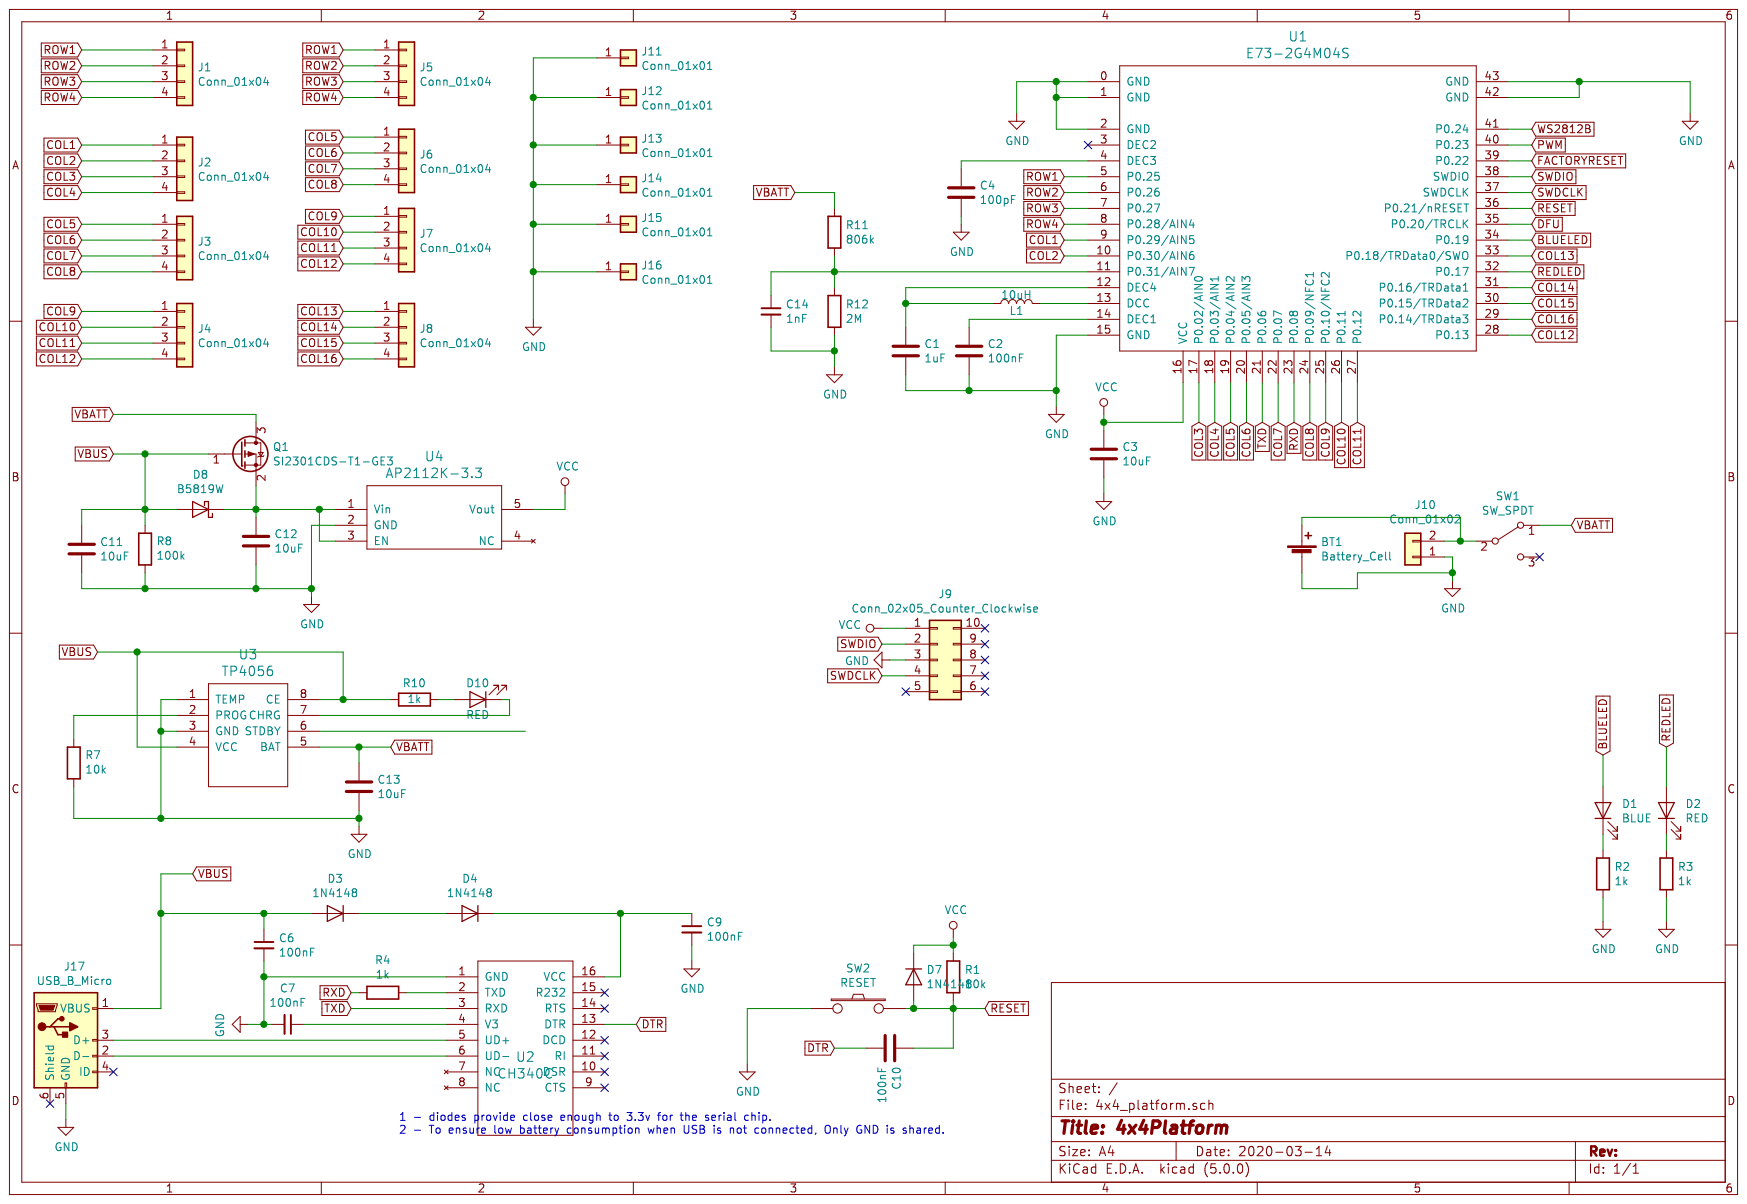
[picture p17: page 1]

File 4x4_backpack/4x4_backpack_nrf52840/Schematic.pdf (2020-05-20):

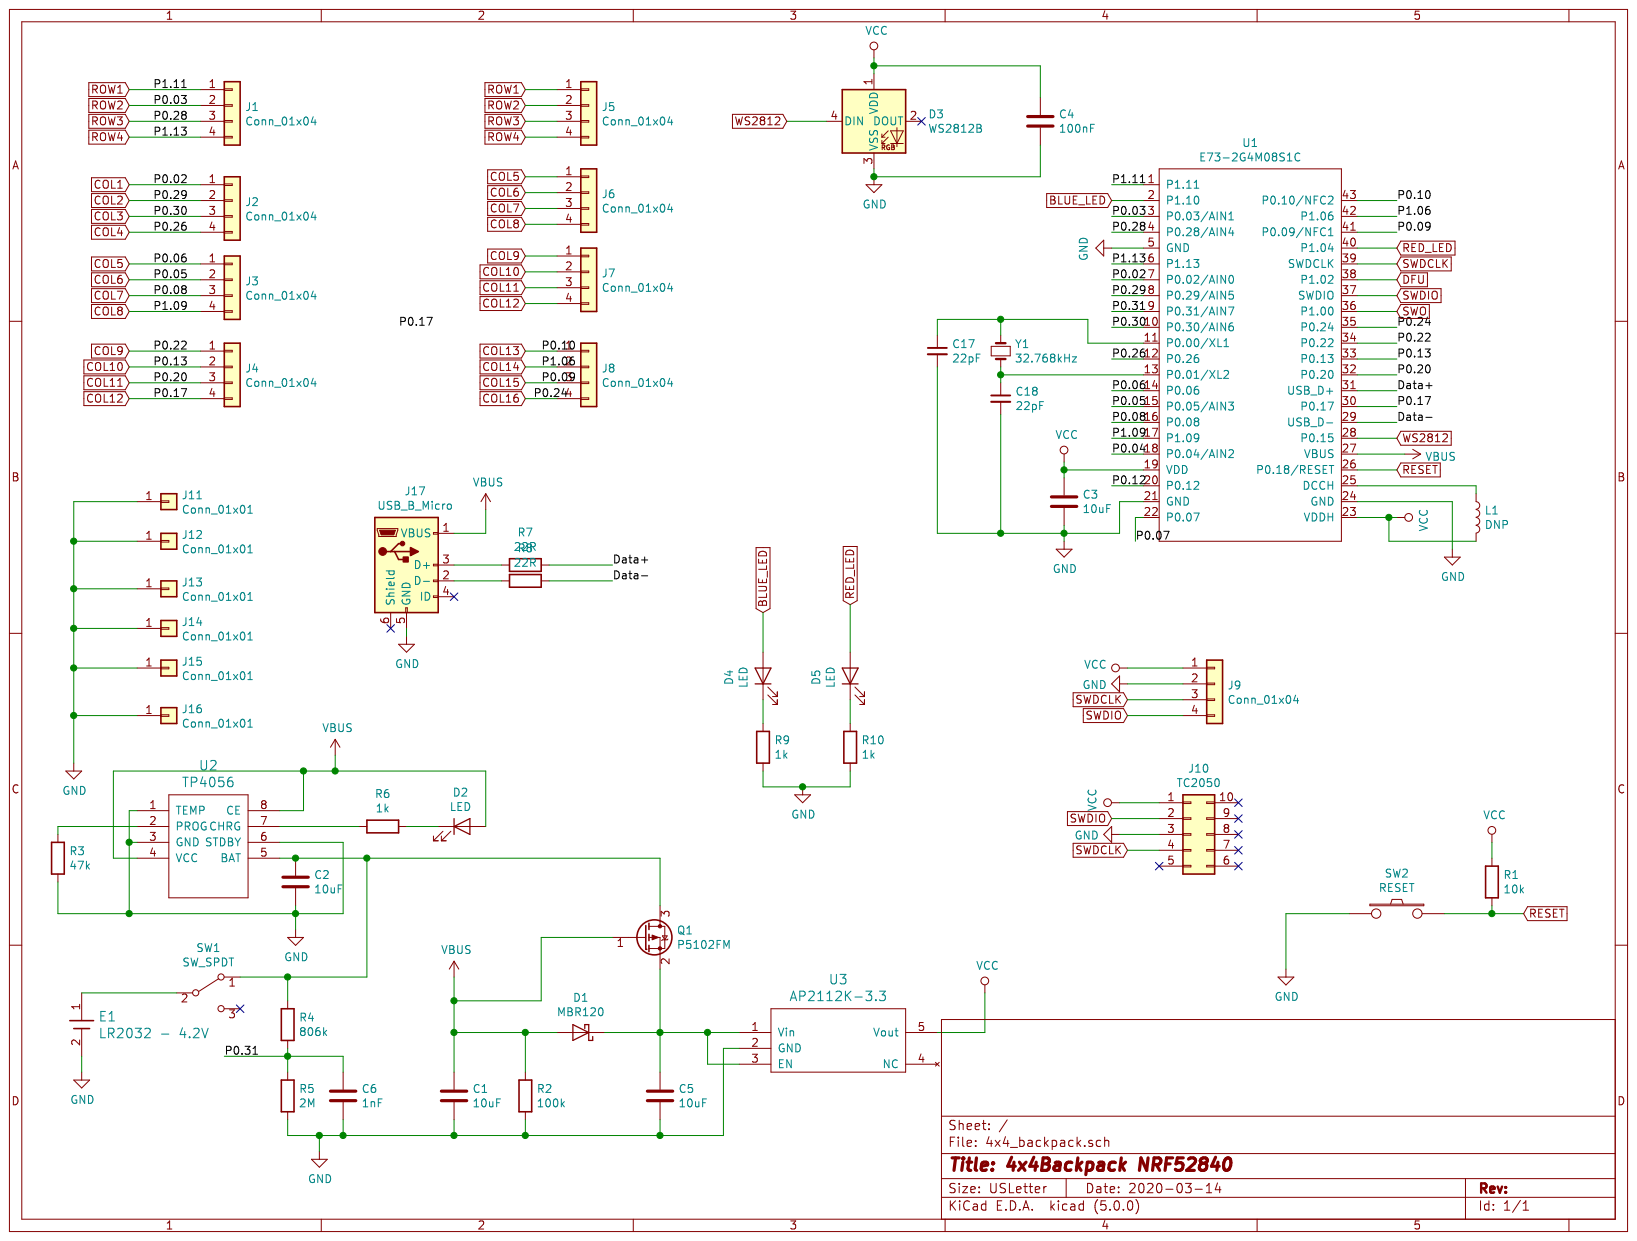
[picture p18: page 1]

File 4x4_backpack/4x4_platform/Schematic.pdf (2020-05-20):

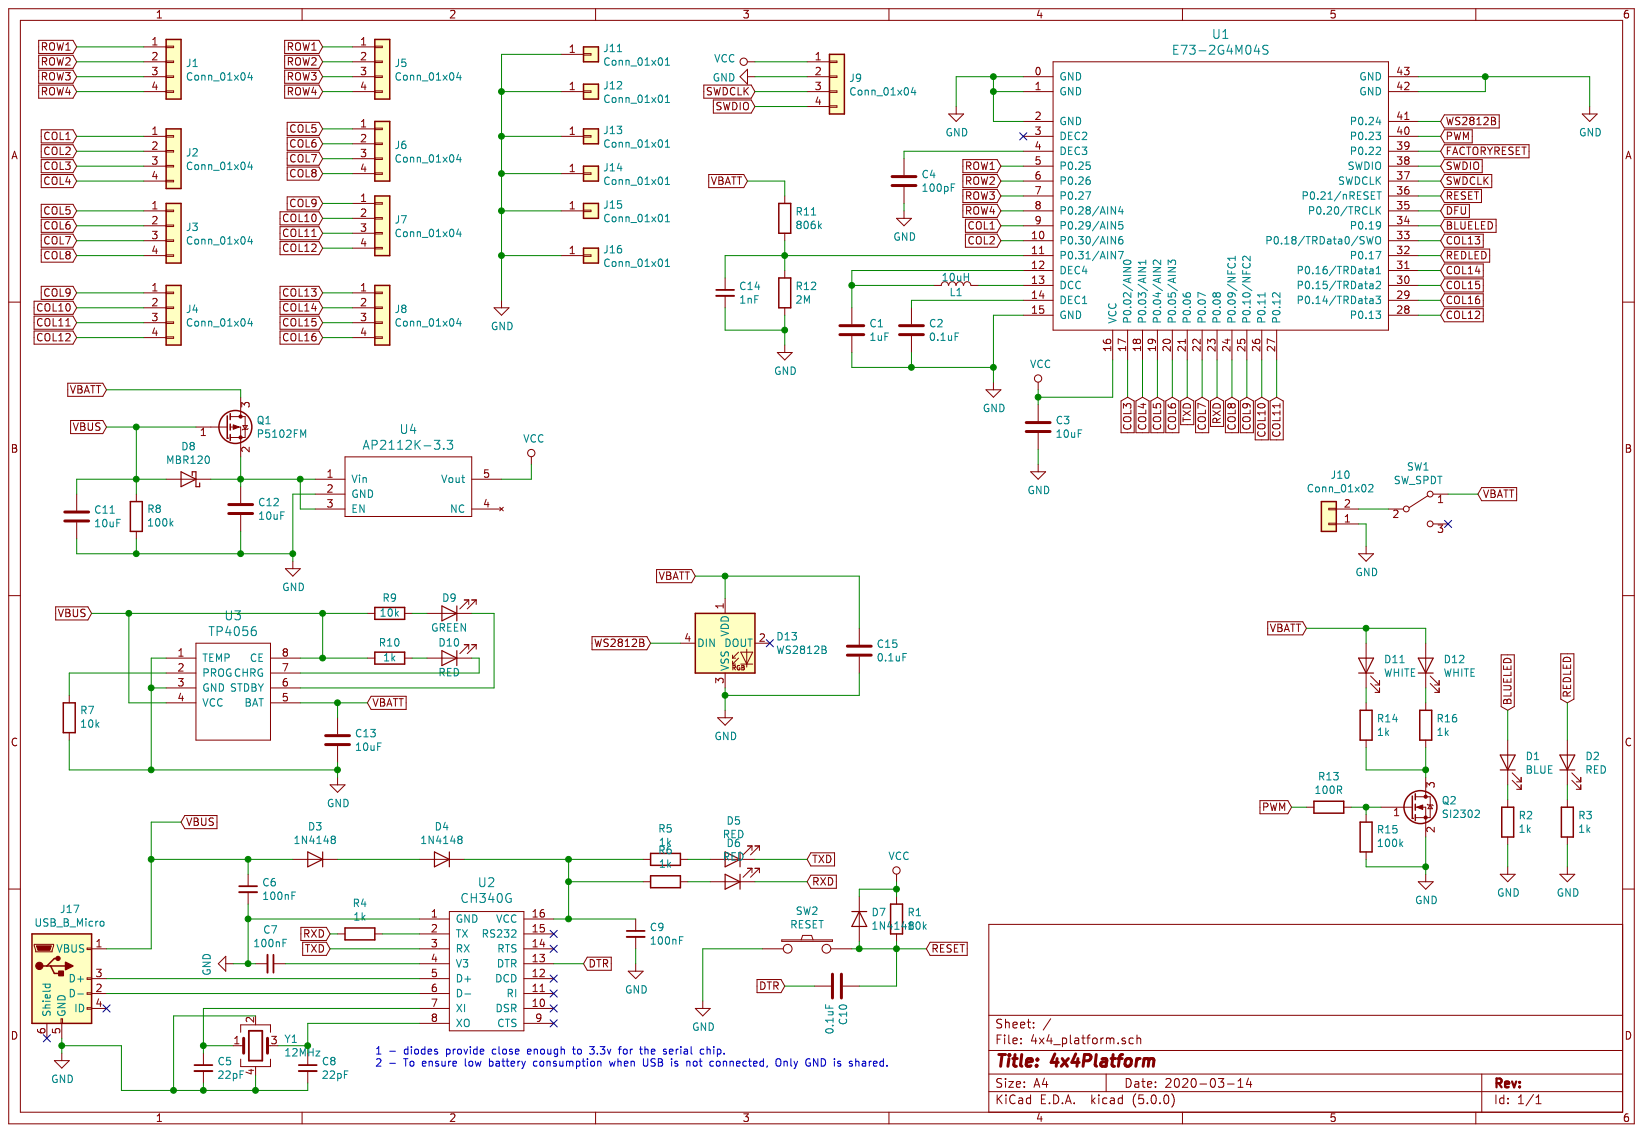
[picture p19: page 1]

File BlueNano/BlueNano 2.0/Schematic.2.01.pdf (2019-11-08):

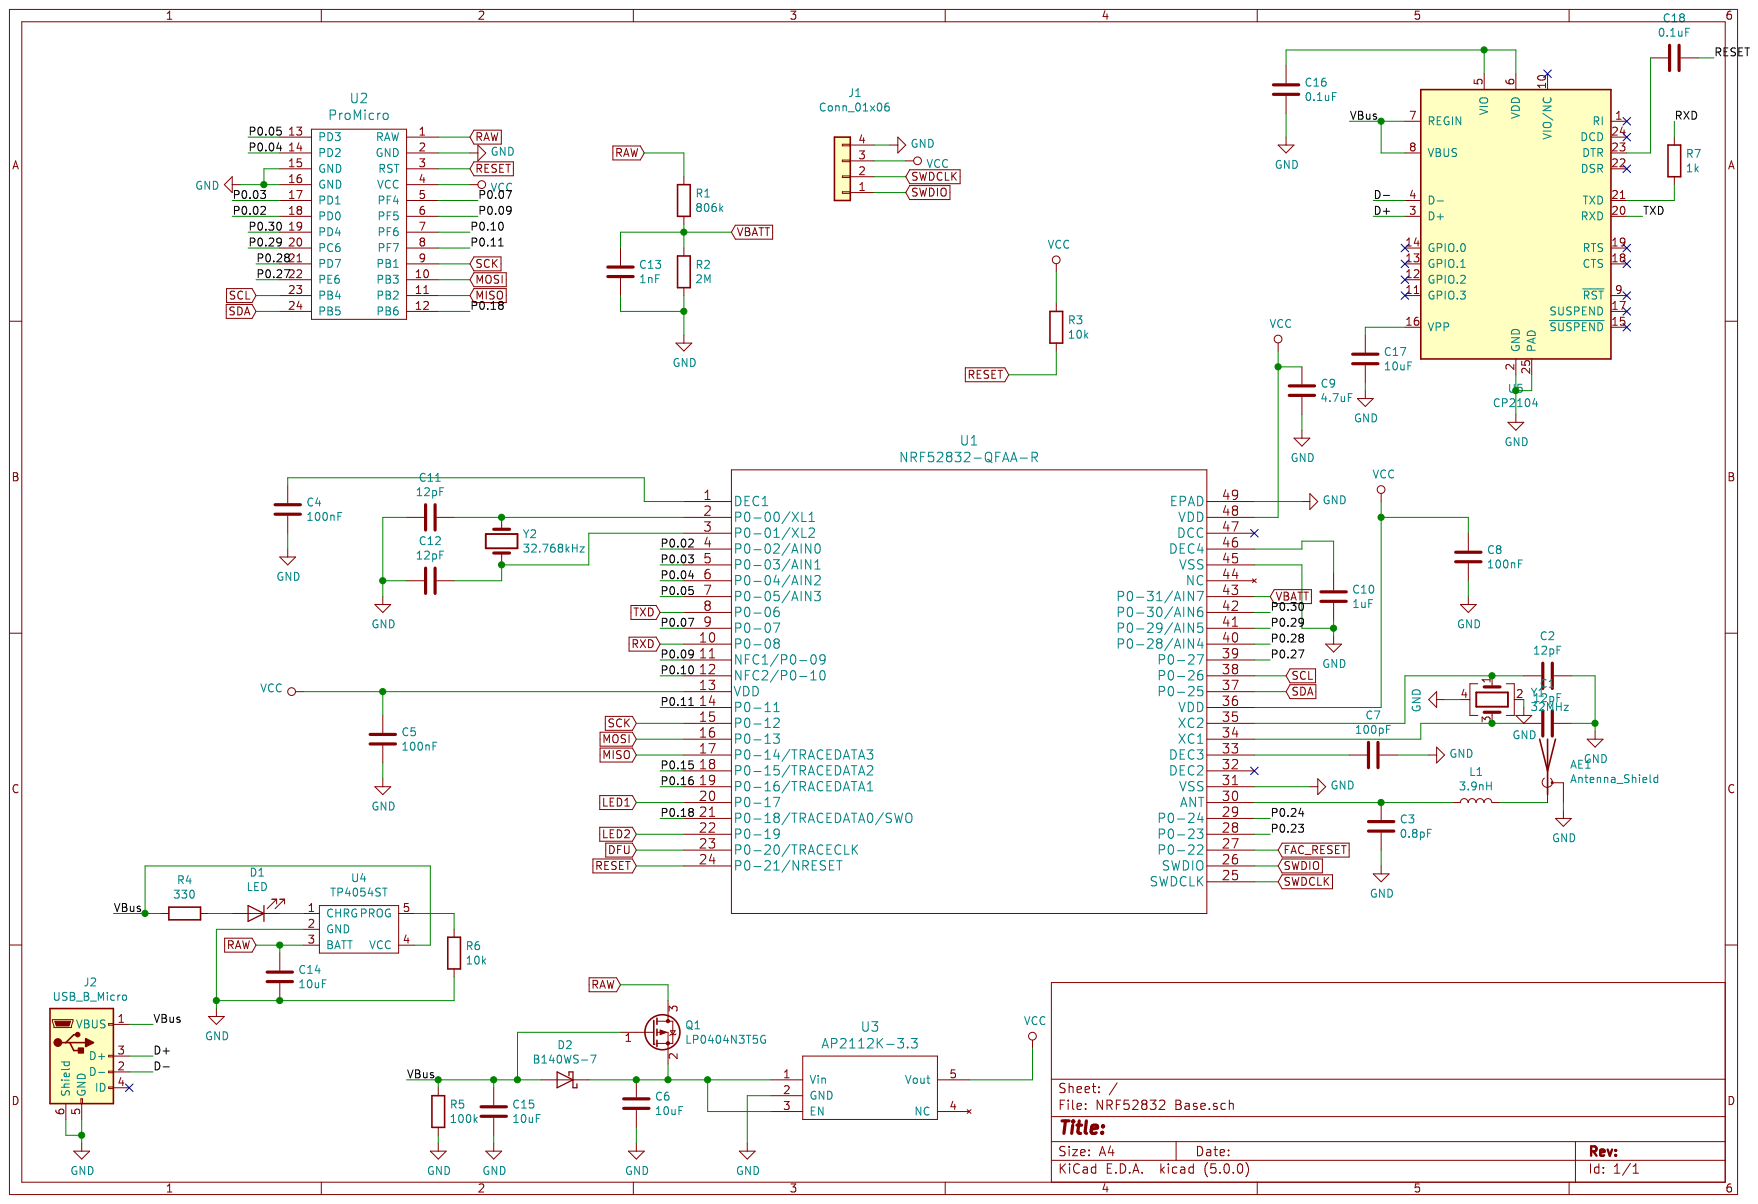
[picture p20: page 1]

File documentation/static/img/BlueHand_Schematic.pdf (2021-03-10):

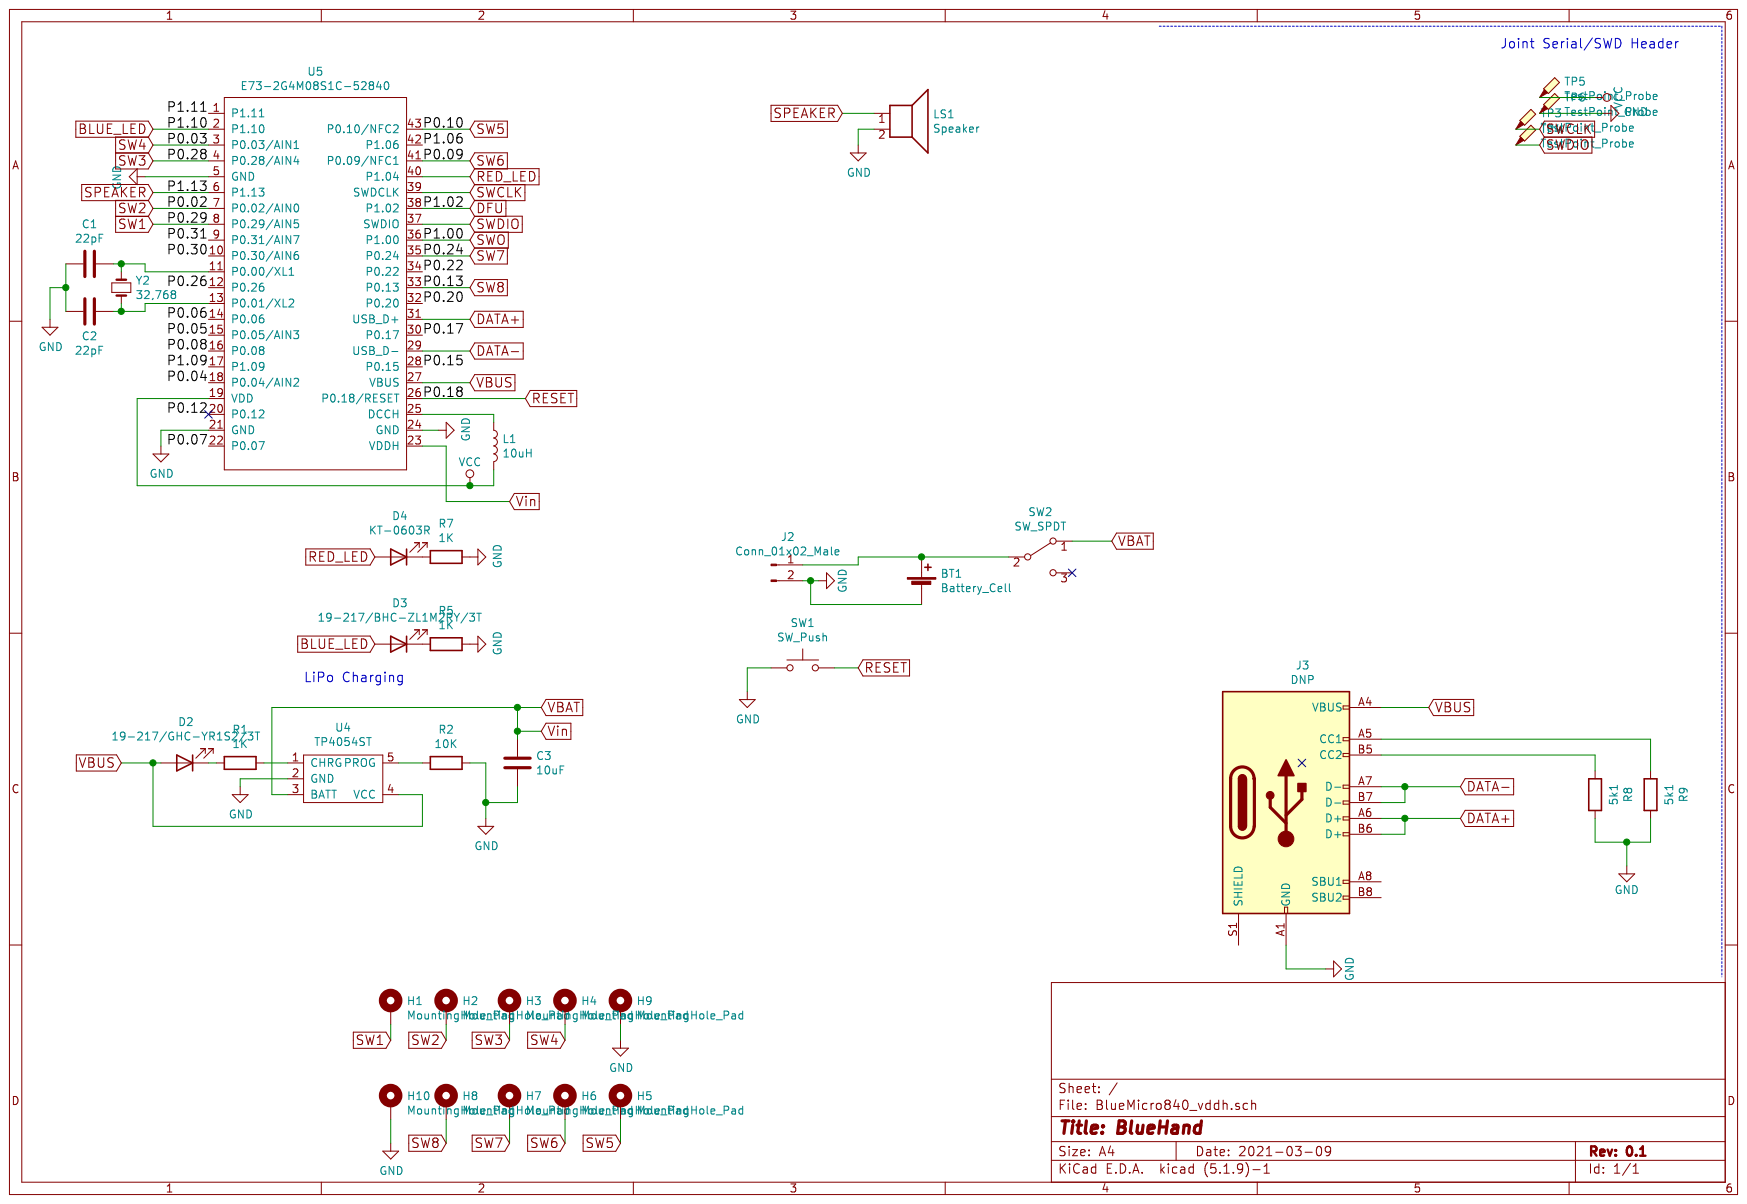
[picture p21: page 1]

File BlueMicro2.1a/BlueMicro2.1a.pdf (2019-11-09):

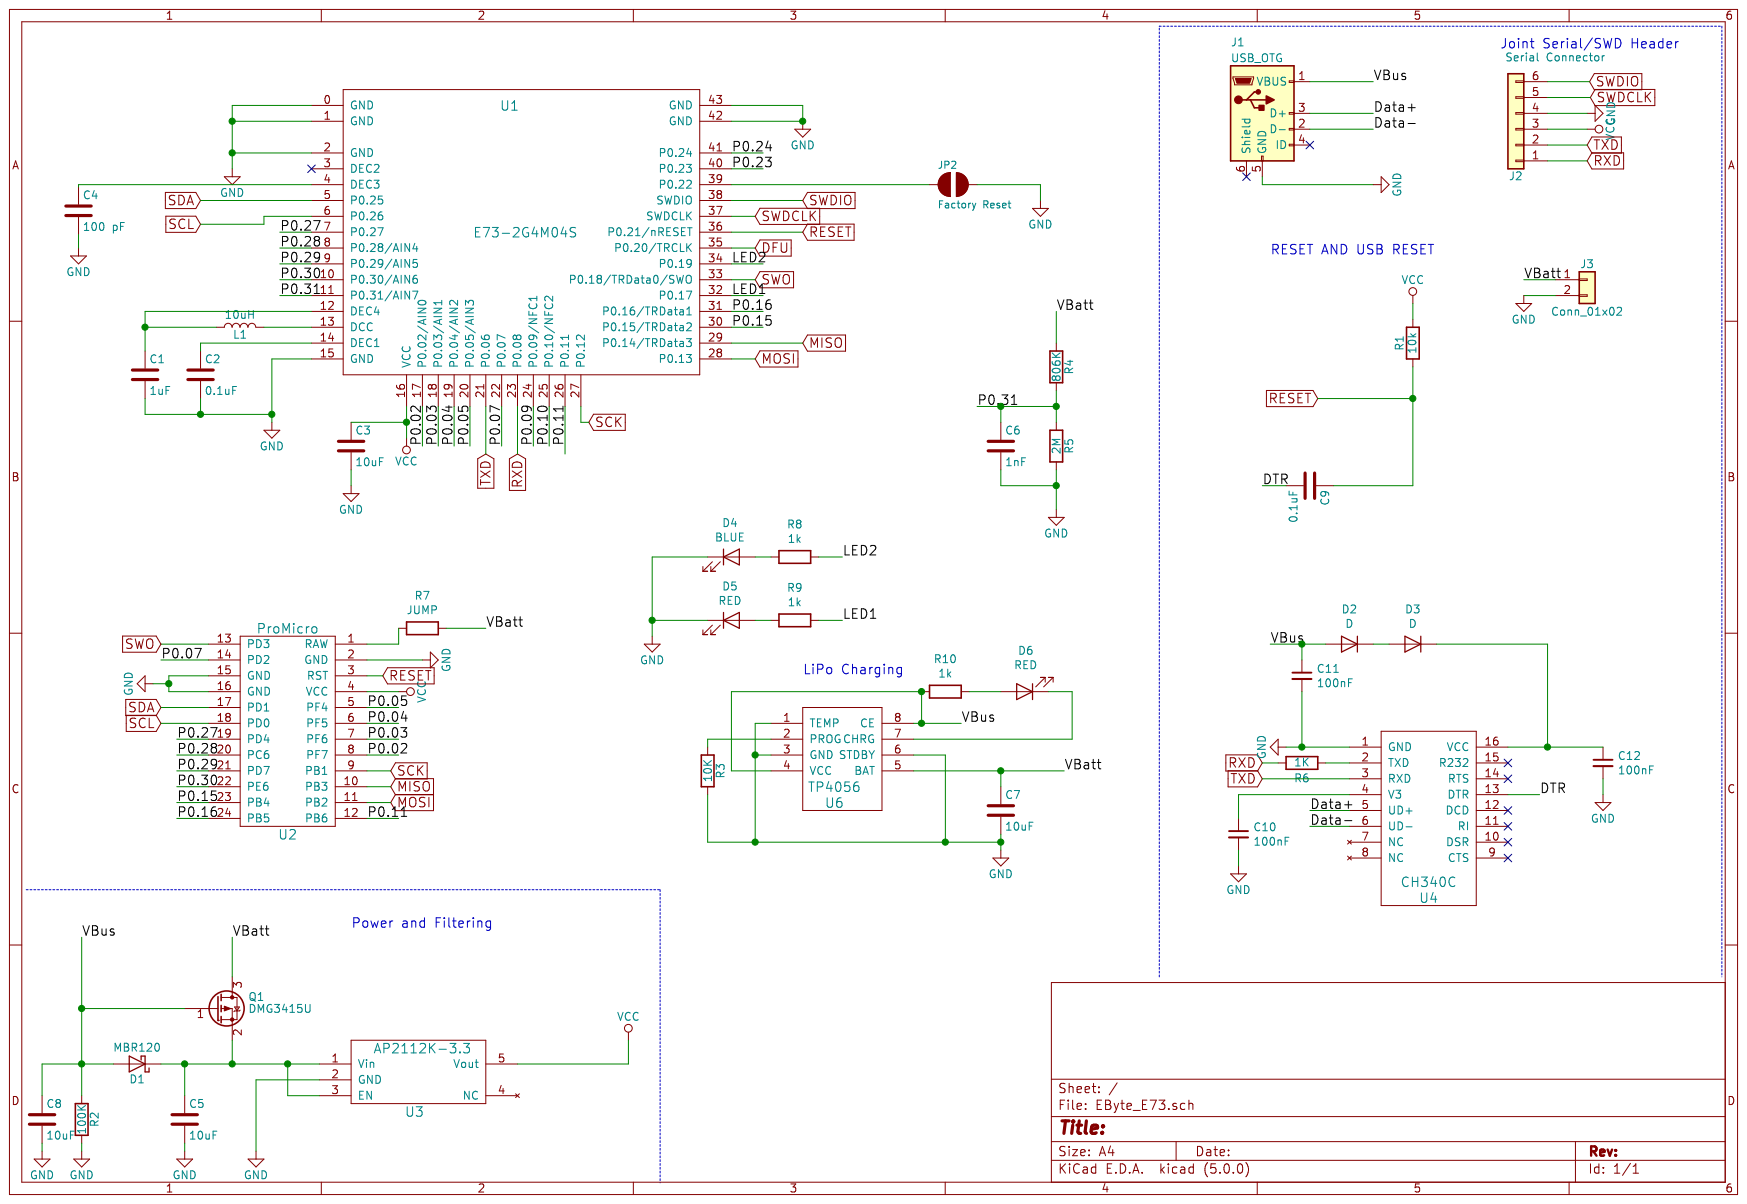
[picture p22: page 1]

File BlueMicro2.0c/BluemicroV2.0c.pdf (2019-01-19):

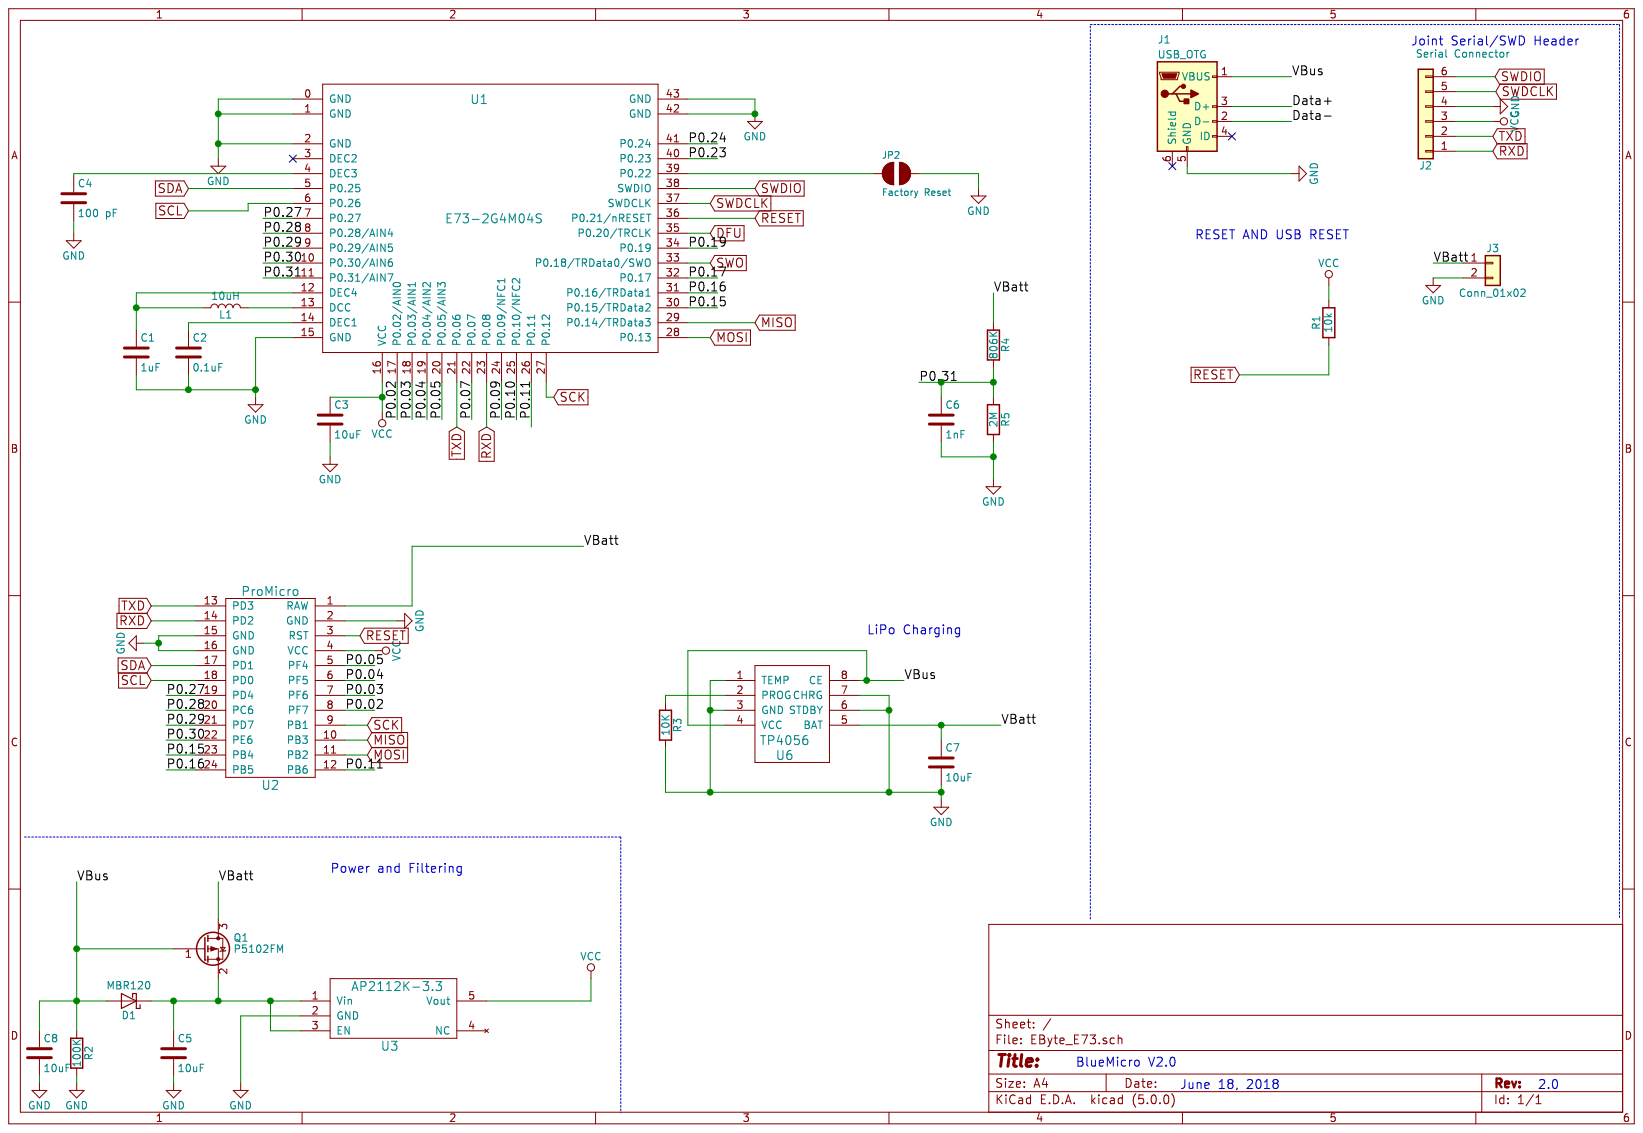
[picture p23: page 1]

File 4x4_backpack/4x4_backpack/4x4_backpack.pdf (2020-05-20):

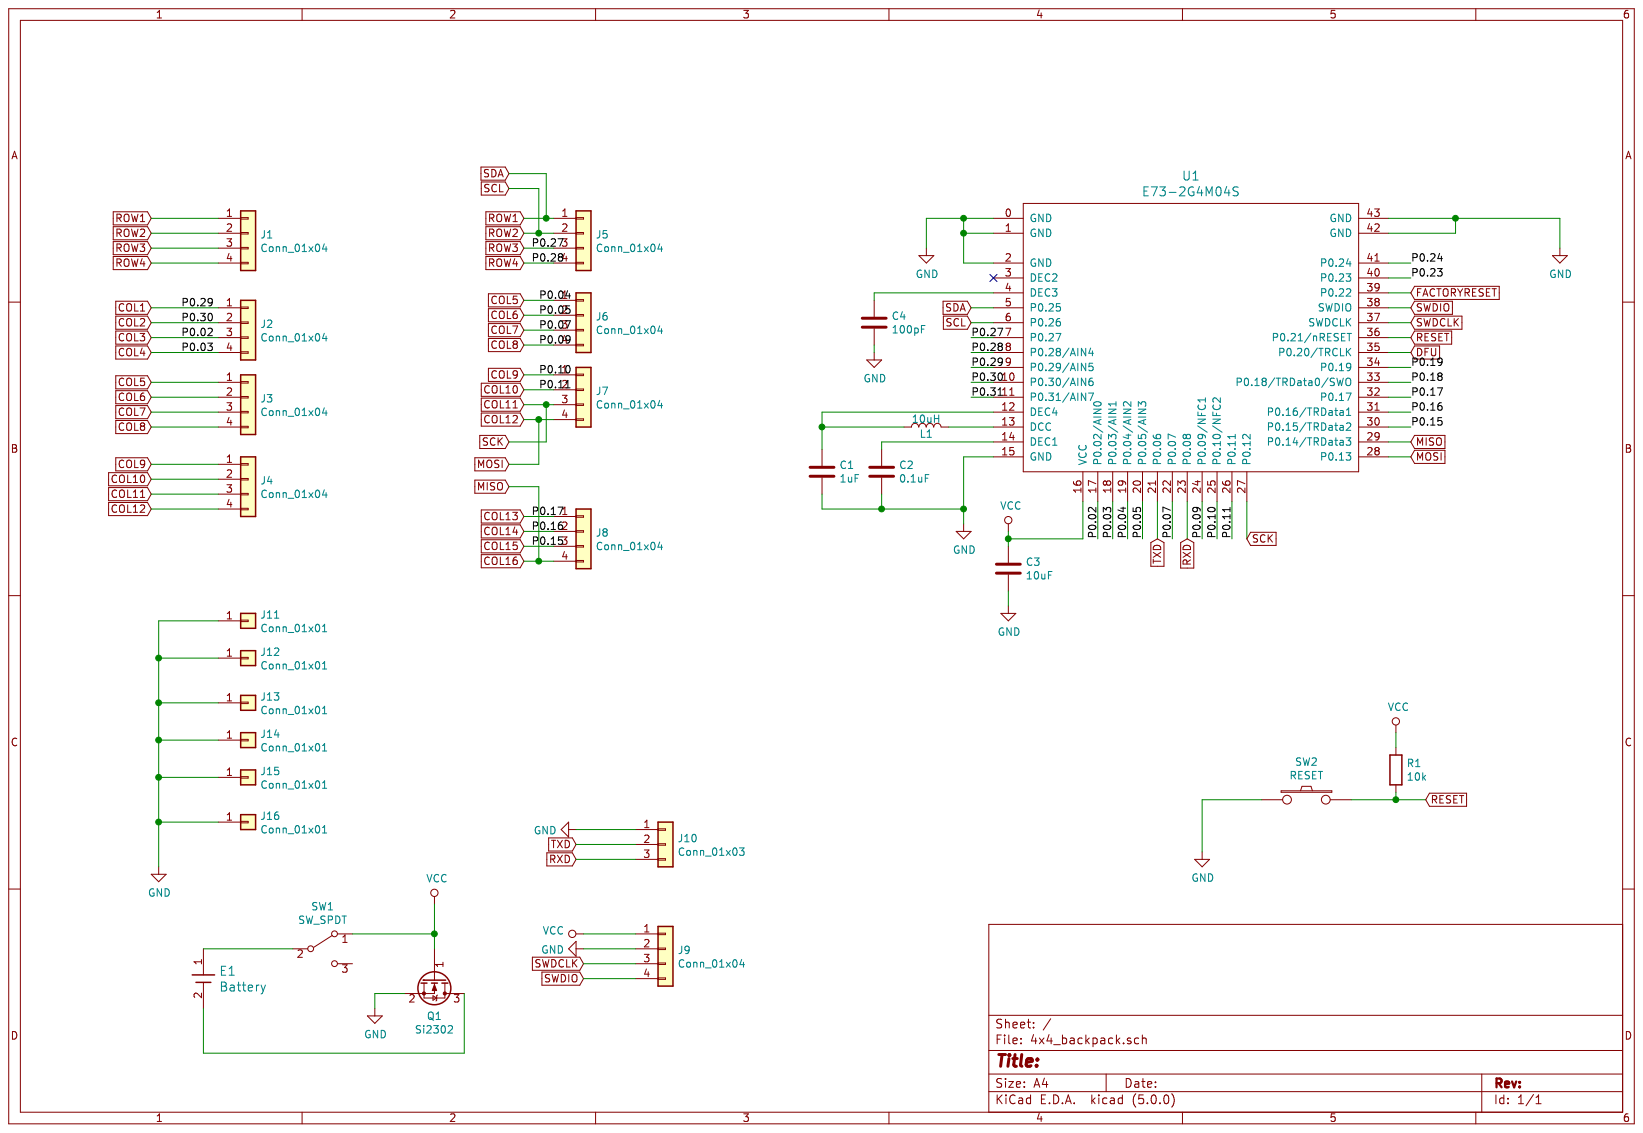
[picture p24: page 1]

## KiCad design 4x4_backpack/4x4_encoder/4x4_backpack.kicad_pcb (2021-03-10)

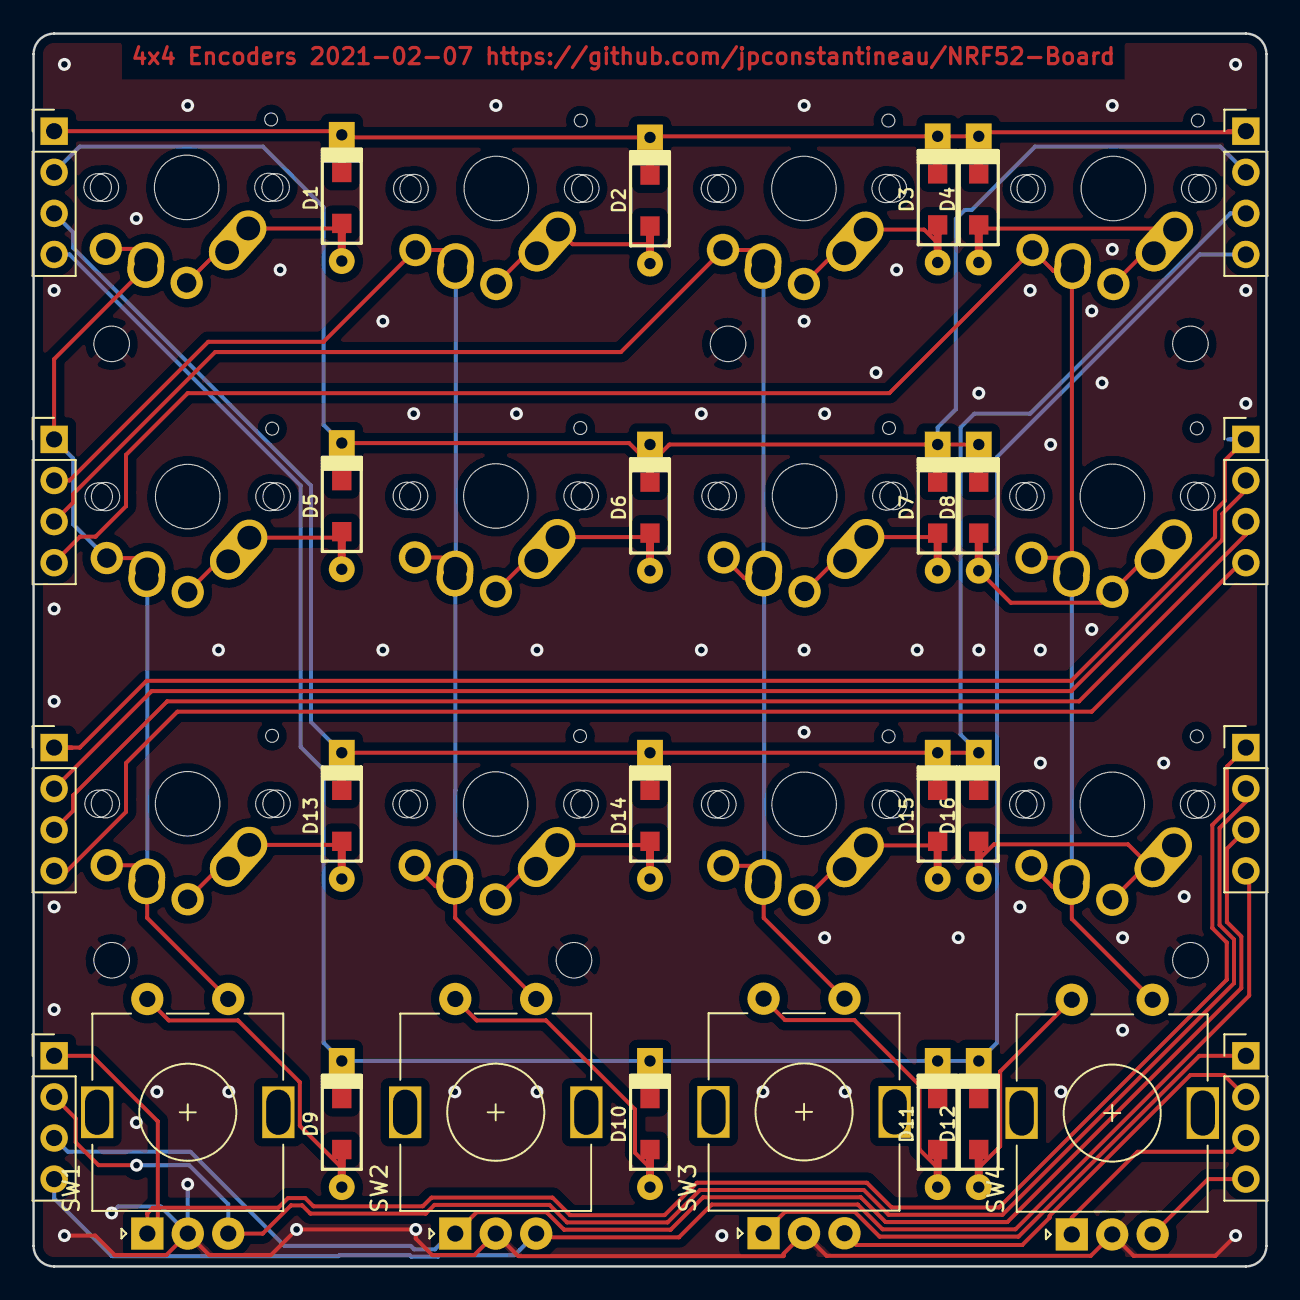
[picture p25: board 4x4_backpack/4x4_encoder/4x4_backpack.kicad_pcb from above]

Board: 2 copper layers, 76.2 x 76.2 mm, 46 parts (0 on the bottom side), 37 nets.

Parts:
D1, D2, D3, D4, D5, D6, D7, D8, D9, D10, D11, D12, D13, D14, D15, D16: DIODE; D_SOD123_axial-dual
J1, J2, J3, J4, J5, J6, J7, J8: Conn_01x04; PinHeader_1x04_P2.54mm_Vertical
J11, J12, J13, J14, J15, J16: Conn_01x01; MountingHole_2.2mm_M2_ISO7380
S1, S2, S3, S4, S5, S6, S7, S8, S13, S14, S15, S16: CHERRY_MX; MX-Alps-Choc-1U
SW1, SW2, SW3, SW4: Rotary_Encoder_Switch; RotaryEncoder_Alps_EC11E-Switch_Vertical_H20mm

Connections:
COL1: J2.1, S1.2, S2.2, S13.2, SW1.S1
COL2: J2.2, S3.2, S4.2, S14.2, SW2.S1
COL3: J2.3, S5.2, S6.2, S15.2, SW3.S1
COL4: J2.4, S7.2, S8.2, S16.2, SW4.S1
COL5: J3.1, J6.1
COL6: J3.2, J6.2
COL7: J3.3, J6.3
COL8: J3.4, J6.4
COL9: J4.1, J7.1, SW1.A
COL10: J4.2, J7.2, SW1.B
COL11: J4.3, J7.3, SW2.A
COL12: J4.4, J7.4, SW2.B
COL13: J8.1, SW3.A
COL14: J8.2, SW3.B
COL15: J8.3, SW4.A
COL16: J8.4, SW4.B
GND: J11.1, J12.1, J13.1, J14.1, J15.1, J16.1, SW1.C, SW2.C, SW3.C, SW4.C
unnamed: D1.2, S1.1
unnamed: D2.2, S3.1
unnamed: D3.2, S5.1
unnamed: D4.2, S7.1
unnamed: D5.2, S2.1
unnamed: D6.2, S4.1
unnamed: D7.2, S6.1
unnamed: D8.2, S8.1
unnamed: D9.2, SW1.S2
unnamed: D10.2, SW2.S2
unnamed: D11.2, SW3.S2
unnamed: D12.2, SW4.S2
unnamed: D13.2, S13.1
unnamed: D14.2, S14.1
unnamed: D15.2, S15.1
unnamed: D16.2, S16.1
ROW1: D1.1, D2.1, D3.1, D4.1, J1.1, J5.1
ROW2: D5.1, D6.1, D7.1, D8.1, J1.2, J5.2
ROW3: D13.1, D14.1, D15.1, D16.1, J1.3, J5.3
ROW4: D9.1, D10.1, D11.1, D12.1, J1.4, J5.4

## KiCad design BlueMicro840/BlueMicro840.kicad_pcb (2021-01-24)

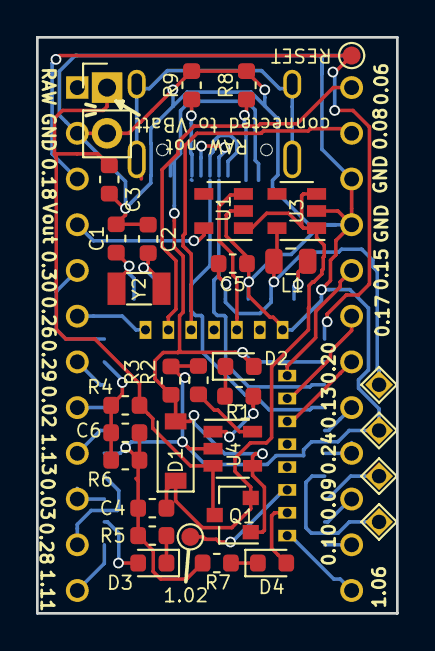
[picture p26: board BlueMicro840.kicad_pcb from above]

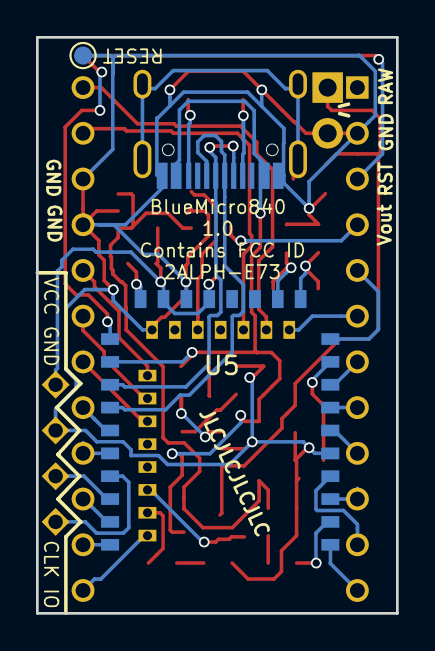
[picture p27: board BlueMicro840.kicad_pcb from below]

Board: 2 copper layers, 20.0 x 32.0 mm, 36 parts (3 on the bottom side), 44 nets.

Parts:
C1, C2: 22pF; C_0603_1608Metric
C3, C4, C5: 10uF; C_0603_1608Metric
C6: 1nF; C_0603_1608Metric
D1: B5819W; D_SOD-123
D2: 19-217/GHC-YR1S2/3T; LED_0603_1608Metric
D3: 19-217/BHC-ZL1M2RY/3T; LED_0603_1608Metric
D4: KT-0603R; LED_0603_1608Metric
J2: Conn_01x02_Male; PinHeader_1x02_P2.54mm_Vertical
J3: DNP; HRO-TYPE-C-31-M-12-C165948
L1: DNP; L_0805_2012Metric
Q1: SI2301CDS-T1-GE3; SOT-23
R1, R5, R7: 1K; R_0603_1608Metric
R2: 10K; R_0603_1608Metric
R3: 100K; R_0603_1608Metric
R4: 806k; R_0603_1608Metric
R6: 2M; R_0603_1608Metric
R8, R9: 5k1; R_0603_1608Metric
TP1, TP7, TP8: TestPoint_Probe; TestPoint_Pad_D1.0mm
TP3, TP4, TP5, TP6: TestPoint_Probe; TestPoint_THTPad_1.1x1.1mm_Drill0.8mm
U1, U3: AP2112K-3.3TRG1; SOT-23-5
U2: ProMicro; pro_micro
U4: TP4054ST; SOT-23-5
U5: E73-2G4M08S1C-52840
Y2: 32,768; Crystal_SMD_3215-2Pin_3.2x1.5mm

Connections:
1.02: TP1.1, U5.38
/P0.02: U2.8, U5.7
/P0.03: U2.10, U5.3
/P0.09: U2.22, U5.41
/P0.10: U2.23, U5.43
/P0.13: U2.20, U5.33
/P0.15: U2.17, U5.28
/P0.17: U2.18, U5.30
/P0.20: U2.19, U5.32
/P0.24: U2.21, U5.35
/P0.26: U2.6, U5.12
/P0.28: U2.11, U5.4
/P0.29: U2.7, U5.8
/P0.30: U2.5, U5.10
/P0.31: C6.1, R4.2, R6.1, U5.9
/P1.06: U2.24, U5.42
/P1.11: U2.12, U5.1
/P1.13: U2.9, U5.6
BLUE_LED: D3.2, U5.2
DATA+: J3.A6, J3.B6, U5.31
DATA-: J3.A7, J3.B7, U5.29
GND: C1.2, C2.1, C3.2, C4.2, C5.2, C6.2, J2.2, J3.A1, R2.2, R3.2, R5.2, R6.2, R7.2, R8.2, R9.2, TP6.1, TP8.1, U1.2, U2.2, U2.15, U2.16, U3.2, U4.2, U5.5, U5.21, U5.24
unnamed: C1.1, U5.11, Y2.1
unnamed: C2.2, U5.13, Y2.2
unnamed: D2.1, R1.1
unnamed: D3.1, R5.1
unnamed: D4.1, R7.1
unnamed: J3.A5, R9.1
unnamed: J3.B5, R8.1
unnamed: L1.1, U5.25
unnamed: R1.2, U4.1
unnamed: R2.1, U4.5
RED_LED: D4.2, U5.40
RESET: TP7.1, U2.3, U5.26
RXD: U2.14, U5.16
SWCLK: TP3.1, U5.39
SWDIO: TP4.1, U5.37
TXD: U2.13, U5.14
VBAT: C3.1, J2.1, Q1.3, R4.1, U4.3
VBUS: D1.2, D2.2, J3.A4, Q1.1, R3.1, U4.4, U5.27
VCC: C5.1, L1.2, TP5.1, U3.5, U5.19, U5.23
Venable: U1.3, U5.20
Vin: C4.1, D1.1, Q1.2, U1.1, U3.1, U3.3
Vout: U1.5, U2.4

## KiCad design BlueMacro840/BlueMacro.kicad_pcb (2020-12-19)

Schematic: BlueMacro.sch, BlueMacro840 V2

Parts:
C1, C2: 22pF; C_0603_1608Metric; LCSC C1653
C3, C4, C5: 10uF; C_0603_1608Metric; LCSC C19702
C6: 1nF; C_0603_1608Metric; LCSC C1588
D1: B5819W; D_SOD-123; LCSC C8598
D2: 19-217/GHC-YR1S2/3T; LED_0603_1608Metric; LCSC C72043
D3: KT-0603R; LED_0603_1608Metric; LCSC C2286
D4: 19-217/BHC-ZL1M2RY/3T; LED_0603_1608Metric; LCSC C72041
J1: Conn_01x02; PinHeader_1x02_P2.54mm_Vertical
J3: USB_C_Receptacle; HRO-TYPE-C-31-M-12-C165948; LCSC C165948
L1: L; L_0805_2012Metric; LCSC C1046
Q1: SI2301CDS-T1-GE3; SOT-23; LCSC C10487
R1: 100k; R_0603_1608Metric; LCSC C25803
R2: 10k; R_0603_1608Metric; LCSC C25804
R3, R7, R8: 1k; R_0603_1608Metric; LCSC C21190
R4: 806k; R_0603_1608Metric; LCSC C23250
R5: 2M; R_0603_1608Metric; LCSC C22976
R6, R9: 5.1k; R_0603_1608Metric; LCSC C23186
TP1: VCC; TestPoint_THTPad_1.1x1.1mm_Drill0.8mm
TP2: GND; TestPoint_THTPad_1.1x1.1mm_Drill0.8mm
TP3: SWDCK; TestPoint_THTPad_1.1x1.1mm_Drill0.8mm
TP4: SDWIO; TestPoint_THTPad_1.1x1.1mm_Drill0.8mm
U1: TP4054ST; SOT-23-5; LCSC C32574
U2: E73-2G4M08S1C; E73-2G4M08S1C-52840
U3, U5: AP2112K-3.3TRG1; SOT-23-5; LCSC C51118
U4: Micro; arduino_micro
Y1: 32.768kHz; Crystal_SMD_3215-2Pin_3.2x1.5mm; LCSC C32346

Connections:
/3V3: U4.19, U5.5
/P0.02: U2.7, U4.8
/P0.03: U2.3, U4.2
/P0.04: U2.18, U4.20
/P0.05: U2.15, U4.12
/P0.06: U2.14, U4.11
/P0.07: U2.22, U4.18
/P0.08: U2.16, U4.13
/P0.09: U2.41, U4.33
/P0.10: U2.43, U4.34
/P0.12: U2.20, U4.16
/P0.13: U2.33, U4.23
/P0.15: U2.28, U4.24
/P0.17: U2.30, U4.25
/P0.20: U2.32, U4.26
/P0.22: U2.34, U4.22
/P0.24: U2.35, U4.21
/P0.26: U2.12, U4.10
/P0.28: U2.4, U4.3
/P0.29: U2.8, U4.9
/P0.30: U2.10, U4.7
/P1.02: U2.38, U4.17
/P1.06: U2.42, U4.15
/P1.09: U2.17, U4.14
/P1.11: U2.1, U4.1
/P1.13: U2.6, U4.4
BLUE_LED: D4.2, U2.2
D+: J3.A6, J3.B6, U2.31
D-: J3.A7, J3.B7, U2.29
GND: C1.2, C2.2, C3.2, C4.2, C5.2, C6.2, J1.2, J3.A1, R1.2, R2.1, R5.2, R6.1, R7.1, R8.1, R9.1, TP2.1, U1.2, U2.5, U2.21, U2.24, U3.2, U4.6, U4.31, U5.2
unnamed: C1.1, U2.11, Y1.1
unnamed: C2.1, U2.13, Y1.2
unnamed: C3.1, D1.1, Q1.2 (S), U3.1, U3.3, U5.1
unnamed: D2.1, R3.2
unnamed: D3.1, R7.2
unnamed: D4.1, R8.2
unnamed: J3.A5, R9.2
unnamed: J3.B5, R6.2
unnamed: L1.1, U2.25
unnamed: R2.2, U1.5
unnamed: R3.1, U1.1
RED_LED: D3.2, U2.40
Reset: U2.26, U4.5, U4.30
SWDCLK: TP3.1, U2.39
SWDIO: TP4.1, U2.37
SWO: U2.36, U5.3
VBatt: C4.1, J1.1, Q1.3 (D), R4.1, U1.3, U4.32
VBatt_Monitor: C6.1, R4.2, R5.1, U2.9
VBus: D1.2, D2.2, J3.A4, Q1.1 (G), R1.1, U1.4, U2.27, U4.29
VCC: C5.1, L1.2, TP1.1, U2.19, U2.23, U3.5

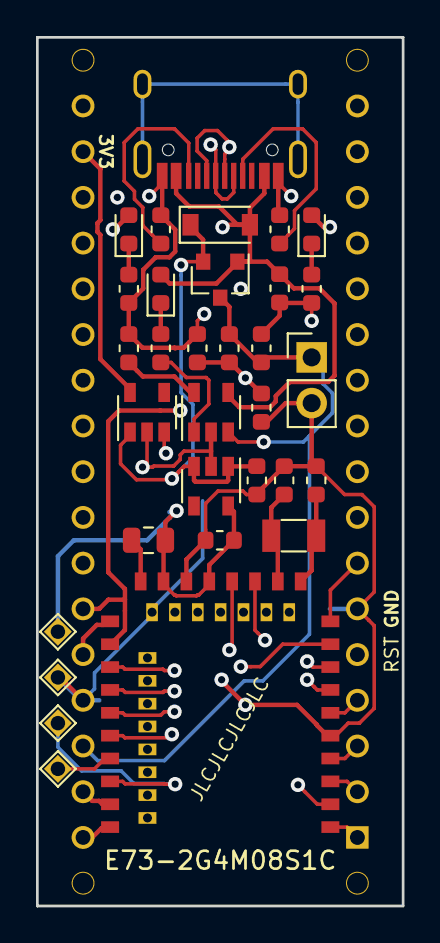
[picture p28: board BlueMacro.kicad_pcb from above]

Board: 4 copper layers, 20.3 x 48.3 mm, 33 parts (0 on the bottom side), 50 nets.

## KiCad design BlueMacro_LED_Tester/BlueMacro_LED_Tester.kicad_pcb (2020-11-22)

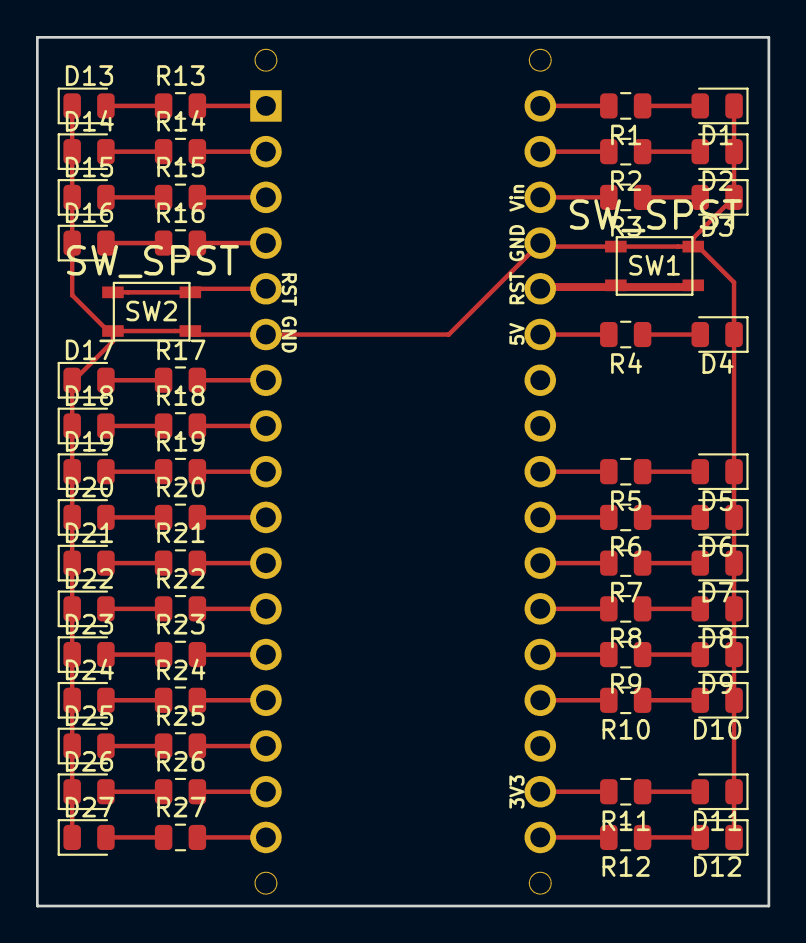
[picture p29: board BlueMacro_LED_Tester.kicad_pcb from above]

Board: 2 copper layers, 40.6 x 48.3 mm, 57 parts (0 on the bottom side), 57 nets.

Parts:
D1, D2, D3, D4, D5, D6, D7, D8, D9, D10, D11, D12, D13, D14, D15, D16, D17, D18, D19, D20, D21, D22, D23, D24, D25, D26, D27: LED; LED_0805_2012Metric
R1, R2, R3, R4, R5, R6, R7, R8, R9, R10, R11, R12, R13, R14, R15, R16, R17, R18, R19, R20, R21, R22, R23, R24, R25, R26, R27: R; R_0805_2012Metric
SW1, SW2: SW_SPST; SW_TACT_TS-1145A_C318904
U1: Micro; arduino_micro_large

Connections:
GND: D1.1, D2.1, D3.1, D4.1, D5.1, D6.1, D7.1, D8.1, D9.1, D10.1, D11.1, D12.1, D13.1, D14.1, D15.1, D16.1, D17.1, D18.1, D19.1, D20.1, D21.1, D22.1, D23.1, D24.1, D25.1, D26.1, D27.1, SW1.1, SW2.2, U1.6, U1.31
unnamed: D1.2, R1.1
unnamed: D2.2, R2.1
unnamed: D3.2, R3.1
unnamed: D4.2, R4.1
unnamed: D5.2, R5.1
unnamed: D6.2, R6.1
unnamed: D7.2, R7.1
unnamed: D8.2, R8.1
unnamed: D9.2, R9.1
unnamed: D10.2, R10.1
unnamed: D11.2, R11.1
unnamed: D12.2, R12.1
unnamed: D13.2, R13.1
unnamed: D14.2, R14.1
unnamed: D15.2, R15.1
unnamed: D16.2, R16.1
unnamed: D17.2, R17.1
unnamed: D18.2, R18.1
unnamed: D19.2, R19.1
unnamed: D20.2, R20.1
unnamed: D21.2, R21.1
unnamed: D22.2, R22.1
unnamed: D23.2, R23.1
unnamed: D24.2, R24.1
unnamed: D25.2, R25.1
unnamed: D26.2, R26.1
unnamed: D27.2, R27.1
unnamed: R1.2, U1.34
unnamed: R2.2, U1.33
unnamed: R3.2, U1.32
unnamed: R4.2, U1.29
unnamed: R5.2, U1.26
unnamed: R6.2, U1.25
unnamed: R7.2, U1.24
unnamed: R8.2, U1.23
unnamed: R9.2, U1.22
unnamed: R10.2, U1.21
unnamed: R11.2, U1.19
unnamed: R12.2, U1.18
unnamed: R13.2, U1.1
unnamed: R14.2, U1.2
unnamed: R15.2, U1.3
unnamed: R16.2, U1.4
unnamed: R17.2, U1.7
unnamed: R18.2, U1.8
unnamed: R19.2, U1.9
unnamed: R20.2, U1.10
unnamed: R21.2, U1.11
unnamed: R22.2, U1.12
unnamed: R23.2, U1.13
unnamed: R24.2, U1.14
unnamed: R25.2, U1.15
unnamed: R26.2, U1.16
unnamed: R27.2, U1.17
unnamed: SW1.2, U1.30
unnamed: SW2.1, U1.5

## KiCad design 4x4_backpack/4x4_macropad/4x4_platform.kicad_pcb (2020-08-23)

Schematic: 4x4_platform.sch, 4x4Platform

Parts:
BT1: Battery_Cell; Keystone_1058_1x2032-CoinCell
C1: 1uF; C_0805_2012Metric_Pad1.15x1.40mm_HandSolder; LCSC C28323
C2, C6, C7, C9, C10: 100nF; C_0805_2012Metric_Pad1.15x1.40mm_HandSolder; LCSC C49678
C3, C11, C12, C13: 10uF; C_0805_2012Metric_Pad1.15x1.40mm_HandSolder; LCSC C15850
C4: 100pF; C_0805_2012Metric_Pad1.15x1.40mm_HandSolder; LCSC C1790
C14: 1nF; C_0805_2012Metric_Pad1.15x1.40mm_HandSolder; LCSC C46653
D1: BLUE; LED_0805_2012Metric_Pad1.15x1.40mm_HandSolder; LCSC C2293
D2, D10: RED; LED_0805_2012Metric_Pad1.15x1.40mm_HandSolder; LCSC C84256
D3, D4, D7: 1N4148; D_SOD-123; LCSC C81598
D8: B5819W; D_SOD-123; LCSC C8598
J1, J2, J3, J4, J5, J6, J7, J8: Conn_01x04; PinHeader_1x04_P2.54mm_Vertical
J9: Conn_02x05_Counter_Clockwise; Tag-Connect_TC2050-IDC-NL_2x05_P1.27mm_Vertical
J10: Conn_01x02; PinHeader_1x02_P2.54mm_Vertical
J11, J12, J13, J14, J15, J16: Conn_01x01; MountingHole_2.2mm_M2_ISO7380
J17: USB_B_Micro; USB_Micro-B_Molex-105017-0001
L1: 10uH; C_0805_2012Metric_Pad1.15x1.40mm_HandSolder; LCSC C1046
Q1: SI2301CDS-T1-GE3; SOT-23; LCSC C10487
R1: 10k; C_0805_2012Metric_Pad1.15x1.40mm_HandSolder; LCSC C17414
R2, R3, R4, R10: 1k; R_0805_2012Metric_Pad1.15x1.40mm_HandSolder; LCSC C17513
R7: 10k; R_0805_2012Metric_Pad1.15x1.40mm_HandSolder; LCSC C17414
R8: 100k; R_0805_2012Metric_Pad1.15x1.40mm_HandSolder; LCSC C17407
R11: 806k; R_0805_2012Metric_Pad1.15x1.40mm_HandSolder; LCSC C63494
R12: 2M; R_0805_2012Metric_Pad1.15x1.40mm_HandSolder; LCSC C26112
SW1: SW_SPDT; SPDT_C128955
SW2: RESET; SW_TACT_ALPS_SKQGABE010; LCSC C318884
U1: E73-2G4M04S
U2: CH340C; SOP-16_4.4x10.4mm_P1.27mm; LCSC C84681
U3: TP4056; SSOP-8_3.95x5.21x3.27mm_P1.27mm; LCSC C16581
U4: AP2112K-3.3; SOT-23-5; LCSC C51118

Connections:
BLUELED: D1.2, U1.34
COL1: J2.1, U1.9
COL2: J2.2, U1.10
COL3: J2.3, U1.17
COL4: J2.4, U1.18
COL5: J3.1, J6.1, U1.19
COL6: J3.2, J6.2, U1.20
COL7: J3.3, J6.3, U1.22
COL8: J3.4, J6.4, U1.24
COL9: J4.1, J7.1, U1.25
COL10: J4.2, J7.2, U1.26
COL11: J4.3, J7.3, U1.27
COL12: J4.4, J7.4, U1.28
COL13: J8.1, U1.33
COL14: J8.2, U1.31
COL15: J8.3, U1.30
COL16: J8.4, U1.29
DTR: C10.2, U2.13
GND: BT1.2, C1.2, C2.2, C3.2, C4.2, C6.2, C7.2, C9.2, C11.2, C12.2, C13.2, C14.2, J9.3, J10.1, J11.1, J12.1, J13.1, J14.1, J15.1, J16.1, J17.5, R2.2, R3.2, R7.1, R8.1, R12.2, SW2.1, U1.0, U1.1, U1.2, U1.15, U1.42, U1.43, U2.1, U3.1, U3.3, U4.2
unnamed: BT1.1, J10.2, SW1.2
unnamed: C1.1, L1.1, U1.12
unnamed: C2.1, U1.14
unnamed: C4.1, U1.4
unnamed: C7.1, U2.4
unnamed: C9.1, D4.1, U2.16
unnamed: C12.1, D8.1, Q1.2 (S), U4.1, U4.3
unnamed: C14.1, R11.2, R12.1, U1.11
unnamed: D1.1, R2.1
unnamed: D2.1, R3.1
unnamed: D3.1, D4.2
unnamed: D10.1, U3.7
unnamed: D10.2, R10.2
unnamed: J17.2, U2.6
unnamed: J17.3, U2.5
unnamed: L1.2, U1.13
unnamed: R4.1, U2.2
unnamed: R7.2, U3.2
REDLED: D2.2, U1.32
RESET: C10.1, D7.2, R1.2, SW2.2, U1.36
ROW1: J1.1, J5.1, U1.5
ROW2: J1.2, J5.2, U1.6
ROW3: J1.3, J5.3, U1.7
ROW4: J1.4, J5.4, U1.8
RXD: R4.2, U1.23
SWDCLK: J9.4, U1.37
SWDIO: J9.2, U1.38
TXD: U1.21, U2.3
VBATT: C13.1, Q1.3 (D), R11.1, SW1.1, U3.5
VBUS: C6.1, C11.1, D3.2, D8.2, J17.1, Q1.1 (G), R8.2, R10.1, U3.4, U3.8
VCC: C3.1, D7.1, J9.1, R1.1, U1.16, U4.5

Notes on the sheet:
1 - diodes provide close enough to 3.3v for the serial chip. 2 - To ensure low battery consumption when USB is not connected, Only GND is shared.

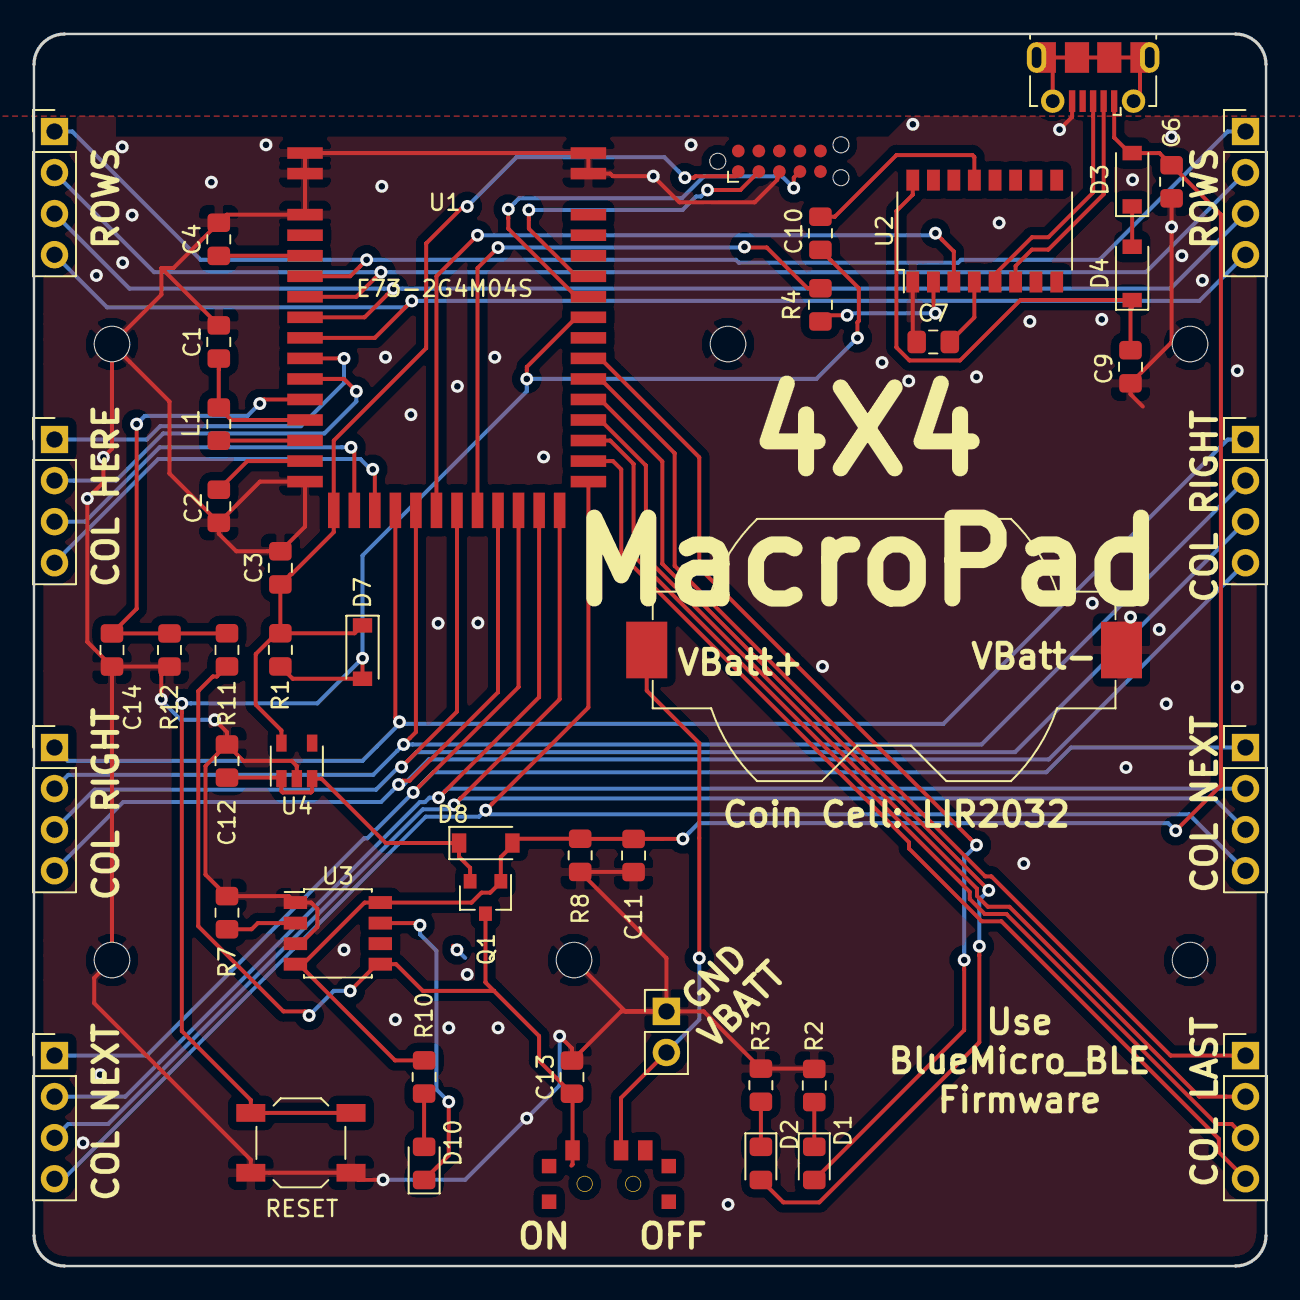
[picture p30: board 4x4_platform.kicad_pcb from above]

Board: 2 copper layers, 76.2 x 76.2 mm, 54 parts (0 on the bottom side), 50 nets.

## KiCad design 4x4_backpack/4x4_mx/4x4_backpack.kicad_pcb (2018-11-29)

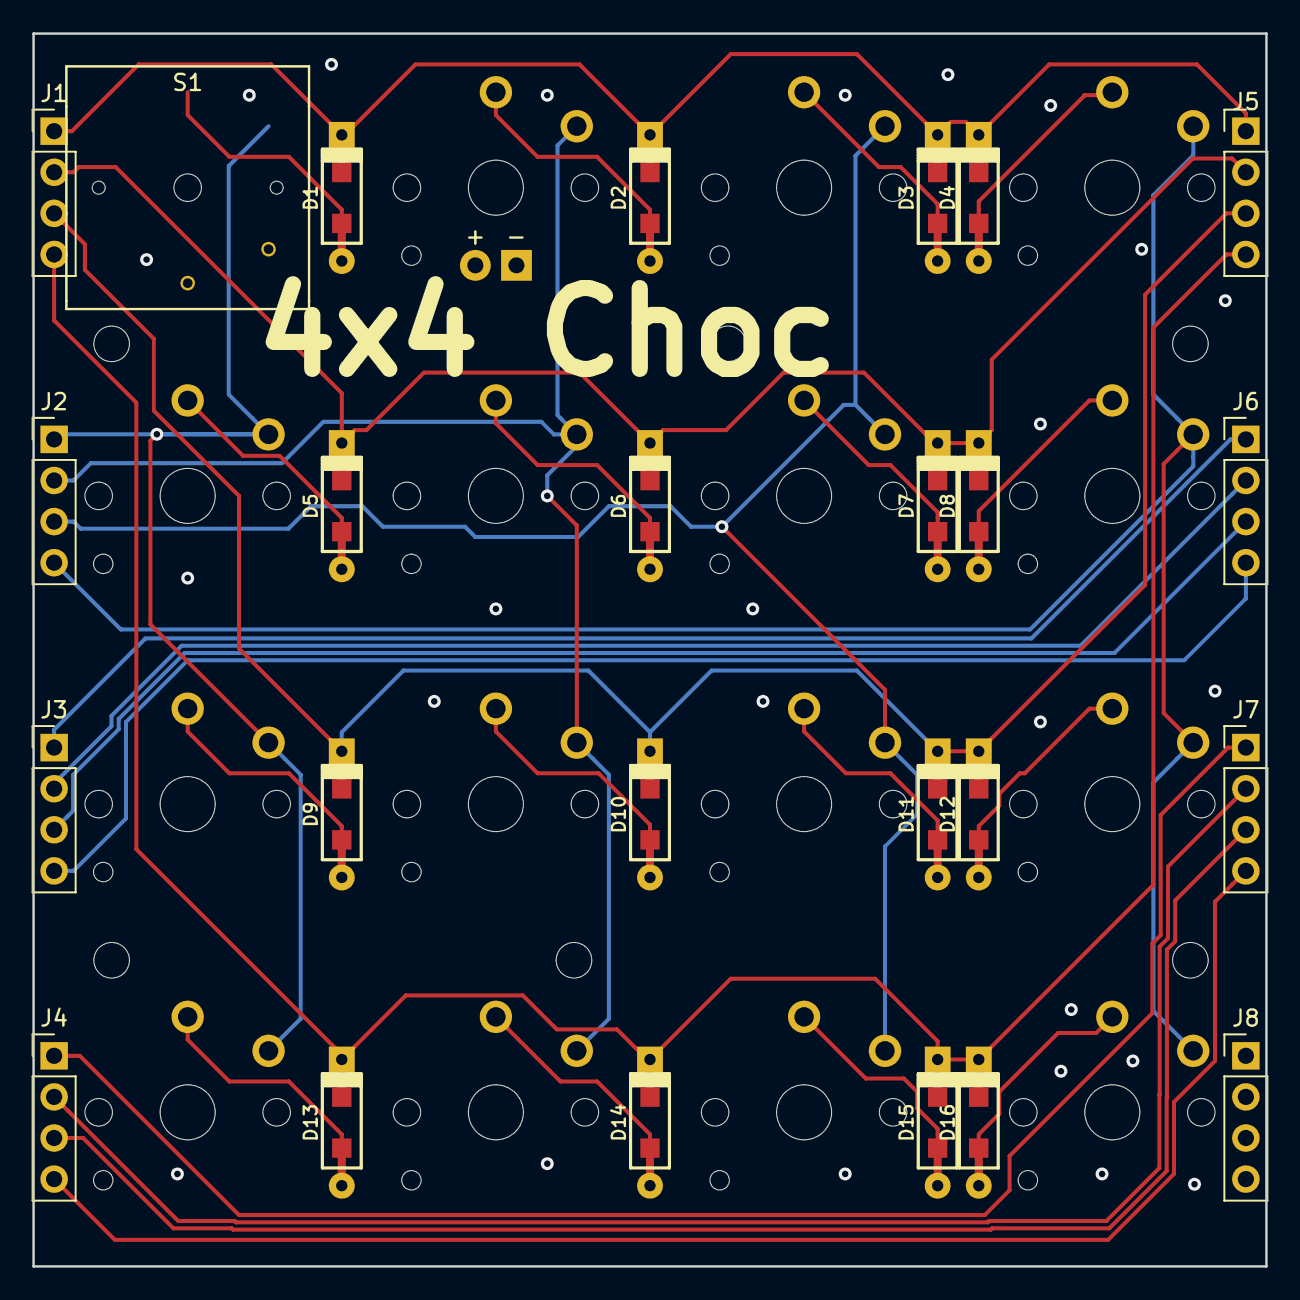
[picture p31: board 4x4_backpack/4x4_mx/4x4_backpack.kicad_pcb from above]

Board: 2 copper layers, 76.2 x 76.2 mm, 46 parts (0 on the bottom side), 33 nets.

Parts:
D1, D2, D3, D4, D5, D6, D7, D8, D9, D10, D11, D12, D13, D14, D15, D16: DIODE; D_SOD123_axial-dual
J1, J2, J3, J4, J5, J6, J7, J8: Conn_01x04; PinHeader_1x04_P2.54mm_Vertical
J11, J12, J13, J14, J15, J16: Conn_01x01; MountingHole_2.2mm_M2_ISO7380
S1: CHERRY_MX; kailh_low
S2: CHERRY_MX; Kailh-PG1350-1u
S3, S4, S5, S6, S7, S8, S9, S10, S11, S12, S13, S14, S15, S16: CHERRY_MX; Kailh-PG1350-1u-noled

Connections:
COL1: J2.1, S1.2, S5.2, S9.2, S13.2
COL2: J2.2, S2.2, S2.4, S6.2, S10.2, S14.2
COL3: J2.3, S3.2, S7.2, S11.2, S15.2
COL4: J2.4, S4.2, S8.2, S12.2, S16.2
COL5: J3.1, J6.1
COL6: J3.2, J6.2
COL7: J3.3, J6.3
COL8: J3.4, J6.4
COL9: J4.1, J7.1
COL10: J4.2, J7.2
COL11: J4.3, J7.3
COL12: J4.4, J7.4
GND: J11.1, J12.1, J13.1, J14.1, J15.1, J16.1
unnamed: D1.2, S1.1
unnamed: D2.2, S2.1, S2.3
unnamed: D3.2, S3.1
unnamed: D4.2, S4.1
unnamed: D5.2, S5.1
unnamed: D6.2, S6.1
unnamed: D7.2, S7.1
unnamed: D8.2, S8.1
unnamed: D9.2, S9.1
unnamed: D10.2, S10.1
unnamed: D11.2, S11.1
unnamed: D12.2, S12.1
unnamed: D13.2, S13.1
unnamed: D14.2, S14.1
unnamed: D15.2, S15.1
unnamed: D16.2, S16.1
ROW1: D1.1, D2.1, D3.1, D4.1, J1.1, J5.1
ROW2: D5.1, D6.1, D7.1, D8.1, J1.2, J5.2
ROW3: D9.1, D10.1, D11.1, D12.1, J1.3, J5.3
ROW4: D13.1, D14.1, D15.1, D16.1, J1.4, J5.4

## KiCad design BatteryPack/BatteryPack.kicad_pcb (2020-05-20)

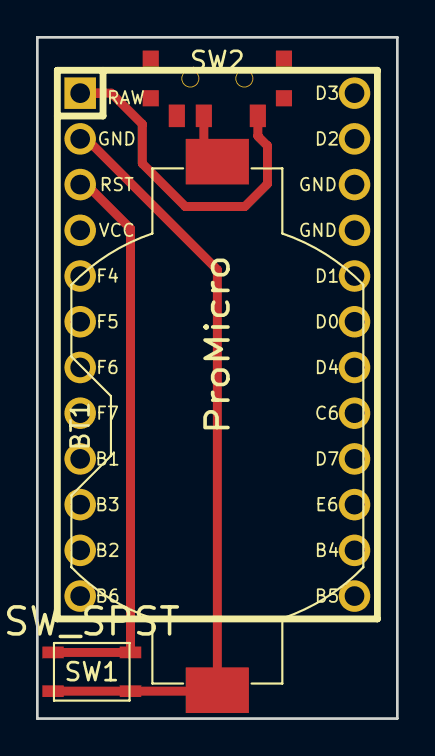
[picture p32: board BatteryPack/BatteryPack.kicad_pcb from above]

Board: 2 copper layers, 20.0 x 37.8 mm, 4 parts (0 on the bottom side), 4 nets.

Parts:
BT1: Battery_Cell; Keystone_1058_1x2032-CoinCell
SW1: SW_SPST; SW_TACT_TS-1145A_C318904
SW2: SW_SPDT; SPDT_C128955
U1: ProMicro; Pro_Micro

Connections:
GND: BT1.2, SW1.2, U1.2
unnamed: BT1.1, SW2.2
unnamed: SW1.1, U1.3
unnamed: SW2.1, U1.1

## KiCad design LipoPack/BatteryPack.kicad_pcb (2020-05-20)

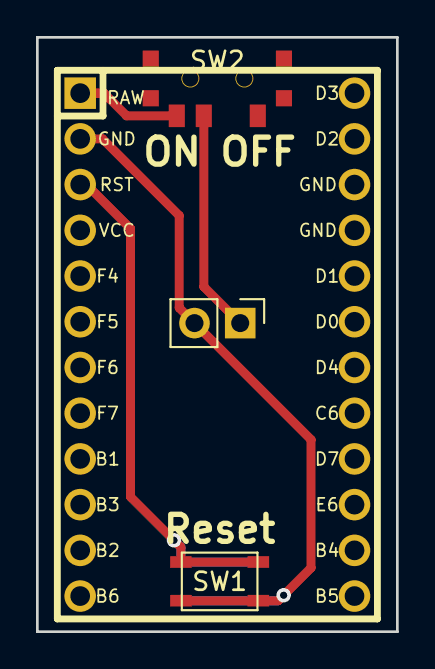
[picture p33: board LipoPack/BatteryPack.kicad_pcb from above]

Board: 2 copper layers, 20.0 x 33.0 mm, 5 parts (1 on the bottom side), 4 nets.

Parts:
J1: Conn_01x02; PinHeader_1x02_P2.54mm_Vertical
SW1, SW3: SW_SPST; SW_TACT_TS-1145A_C318904
SW2: SW_SPDT; SPDT_C128955
U1: ProMicro; Pro_Micro

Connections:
GND: J1.2, SW1.2, SW3.2, U1.2
unnamed: J1.1, SW2.2
unnamed: SW1.1, SW3.1, U1.3
unnamed: SW2.3, U1.1

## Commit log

2018-03-28 Added Scematic Library
    [EByte_E73.kicad_pcb, EByte_E73.sch]
2018-03-29 adding more schematics
    [EByte_E73.sch]
2018-04-06 Adding PCB
    [EByte_E73.sch]
2018-04-07 Finished NRF52 Board incl Gerber
    [EByte_E73-B.Cu.gbr, EByte_E73-B.Mask.gbr, EByte_E73-B.SilkS.gbr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]
2018-04-07 Minor changes to Gerber - capacitor size
    [EByte_E73-B.Cu.gbr, EByte_E73-B.Mask.gbr, EByte_E73-B.SilkS.gbr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]
2018-04-15 adding decoupling capacitor
    [Battery-B.Cu.gbr, Battery-B.Mask.gbr, Battery-B.SilkS.gbr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]
2018-04-25 Switching License to BSD
2018-05-25 fixing folder typo
    [Battery-B.Cu.gbr, Battery-B.Mask.gbr, Battery-B.SilkS.gbr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]
2018-05-29 updating to V1.1 - segregating GPIO from Serial
    [Battery-B.Cu.gbr, Battery-B.Mask.gbr, Battery-B.SilkS.gbr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]
2018-06-04 adding Development Kit Links
    [EByte_E73-B.Cu.gbr, EByte_E73-B.Mask.gbr, EByte_E73-B.SilkS.gbr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]
2018-06-05 completed V2.0
    [EByte_E73-B.Cu.gbr, EByte_E73-B.Mask.gbr, EByte_E73-B.SilkS.gbr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]
2018-09-24 adding BlueMicro Tester PCB
    [EByte_E73-2018-09-23-10-29-53.sch, EByte_E73_tester-2018-09-22-21-38-46.sch, EByte_E73_tester-2018-09-22-21-42-18.sch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]
2018-09-27 adding battery switch PCB
    [Batt_Charger_Regulator.kicad_pcb, Batt_Charger_Regulator.sch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]
2018-09-27 adding antennas
    [EByte_E73-2018-09-26-16-18-53.sch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]
2018-10-11 last kicad 4 commit
2018-10-24 adding boards
2018-11-28 adding BlueNano V2.0 Schematic
    [BlueMicro V2.0c BOM.xlsx, EByte_E73-2018-11-20-18-47-47.sch, EByte_E73-2018-11-27-10-59-48.sch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]
2018-11-29 adding 4x4 an 5x5 backpack
    [4x4_backpack-B.Cu.gbr, 4x4_backpack-B.Mask.gbr, 4x4_backpack-B.Paste.gbr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]
2018-11-29 adding BlueNano BOM for LCSC
    [BlueNano V2.0 - LCSC BOM.xlsx]
2019-01-19 updating pdfs
    [EByte-E73-NRF52840.kicad_pcb, EByte-E73-NRF52840.sch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]
2019-11-08 bringing all changes and tests in here
    [4layers.kicad_pcb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]
2019-11-08 recovering BlueMicro 2.0a
    [EByte_E73-2019-11-08-11-55-58.sch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]
2019-11-08 adding 840backpack
    [4layers.kicad_pcb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]
2019-11-08 adding testing jigs
    [BlueMicro_LED_tester-B.Cu.gbr, BlueMicro_LED_tester-B.Mask.gbr, BlueMicro_LED_tester-B.Paste.gbr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]
2019-11-08 re-org of folders
    [4x4_backpack-B.Cu.gbr, 4x4_backpack-B.Mask.gbr, 4x4_backpack-B.Paste.gbr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]
2019-11-09 updated to 2.1a
    [EByte_E73-2018-09-23-10-29-53.sch, EByte_E73-2018-09-26-16-18-53.sch, EByte_E73-2019-11-08-11-49-44.sch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]
2020-05-20 adding bunch of stuff (sorry for the massive changes)
    [4x4_backpack-B.Cu.gbr, 4x4_backpack-B.Mask.gbr, 4x4_backpack-B.Paste.gbr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]
2020-08-23 adding BlueMicro840
    [4x4_backpack-B.Cu.gbr, 4x4_backpack-B.Mask.gbr, 4x4_backpack-B.Paste.gbr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]
2020-08-24 adding Visual BOM to vddh
2020-11-22 updates to BlueMacro840
    [BlueMacro-B.Cu.gbr, BlueMacro-B.Mask.gbr, BlueMacro-B.SilkS.gbr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]
2020-11-22 updated to main landing page
2020-11-22 added schematics
2020-11-22 added more schematics
2020-11-23 removing kicadscripts automation
2020-11-23 adding PCB pictures to docs
    [4x4_platform-B.Cu.gbr, 4x4_platform-B.Mask.gbr, 4x4_platform-B.Paste.gbr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]
2020-11-25 adding BOM to Docs
    [BlueMacro-B.Cu.gbr, BlueMacro-B.Mask.gbr, BlueMacro-B.SilkS.gbr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]
2020-11-25 fix to bom link
2020-11-26 added description to BMs
2020-12-19 fixed bluemacro840 schematic in docs
    [BlueMacro-B.Cu.gbr, BlueMacro-B.Mask.gbr, BlueMacro-B.SilkS.gbr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]
2021-01-24 errata on BlueMicro840 - 0.31 should read 0.26 - gerber updated
    [BlueMicro840-B.Mask.gbr, BlueMicro840-B_Cu.gbr, BlueMicro840-B_Mask.gbr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]
2021-03-10 added BlueHand to docs
    [4x4_backpack-B.Cu.gbr, 4x4_backpack-B.Mask.gbr, 4x4_backpack-B.Paste.gbr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]
2021-03-10 added encoderpad
2021-05-21 update to bluehand pcb image
2021-10-15 added docs for 833
    [BlueMicro840-B_Cu.gbr, BlueMicro840-B_Mask.gbr, BlueMicro840-B_Paste.gbr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]
